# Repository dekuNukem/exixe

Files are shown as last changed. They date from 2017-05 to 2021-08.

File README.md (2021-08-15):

# exixe: Low-cost miniature Nixie tube driver modules

[Get exixe](https://www.tindie.com/products/dekuNukem/exixe-miniture-nixie-tube-driver-modules/) | [User manual](getting_started.md)



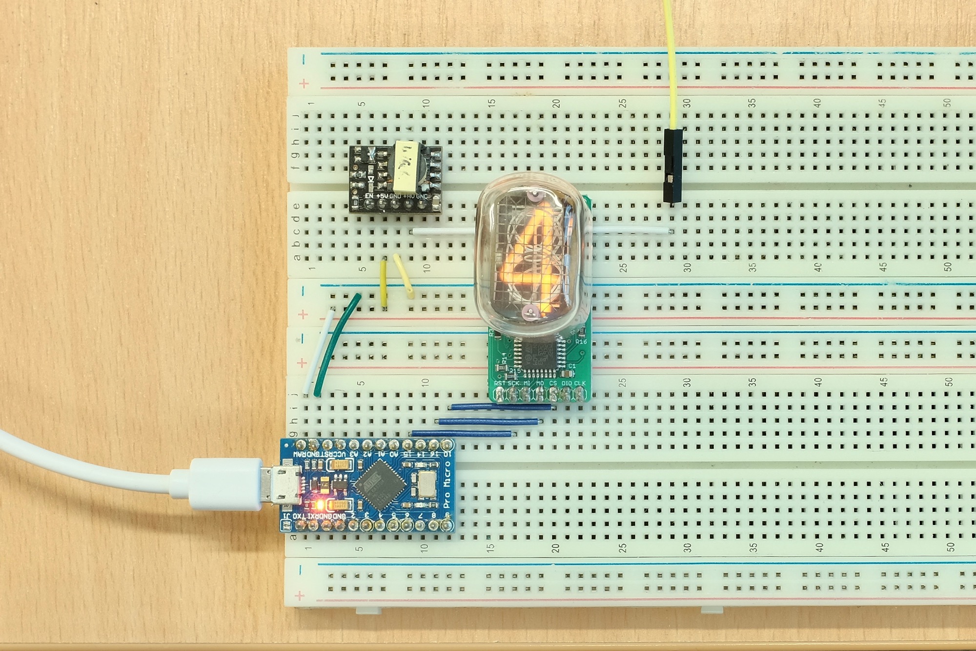
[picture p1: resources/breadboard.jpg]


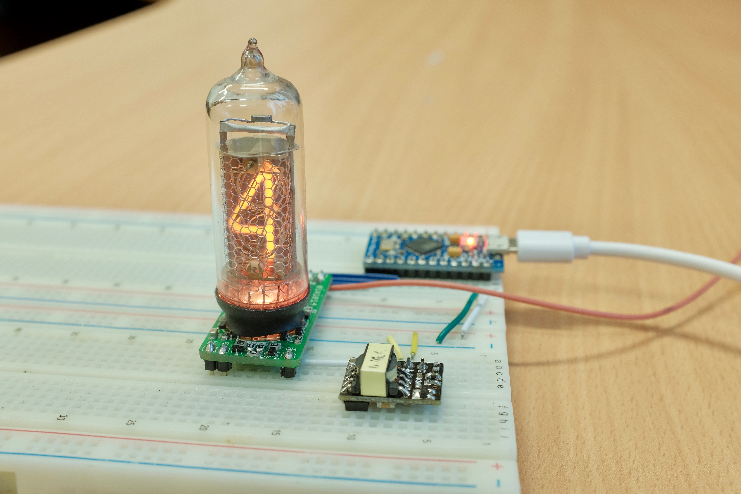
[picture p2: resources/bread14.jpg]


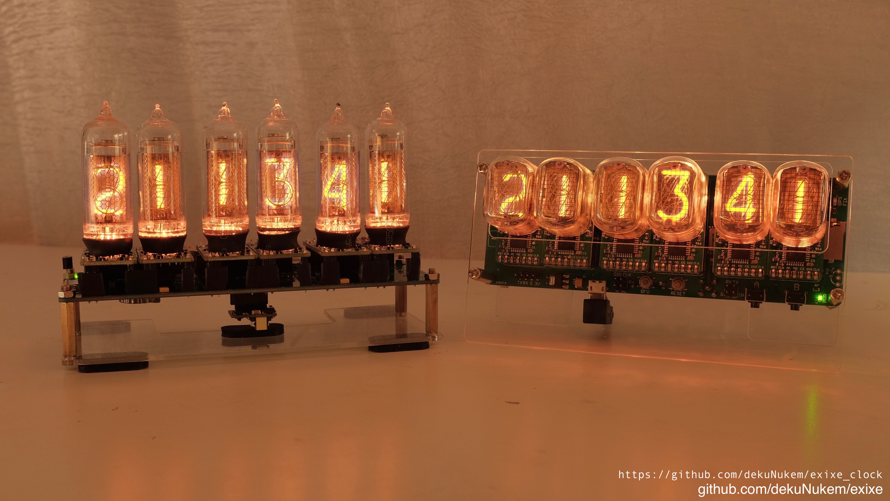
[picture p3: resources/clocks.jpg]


exixe is a miniature driver module for IN-12 and IN-14 Nixie tubes.

It aims to simplify Nixie tube related projects by eliminating the need for obscure vintage driver chips and multiplexing circuits. Instead, you can control every digit and the RGB backlight via SPI using only 3 wires and 1 line of code.

exixe is cheap, small and modular for easy integration. It is compatible with Arduino, Raspberry Pi, and virtually all embedded dev boards today.

## Buy exixe on Tindie!

I did a small production run of exixe modules, and now you can buy them directly on Tindie:

https://www.tindie.com/products/dekuNukem/exixe-miniture-nixie-tube-driver-modules/

## Features

Compared to the traditional approach, exixe modules offers significant advantages:

#### Small and modular
* 2x4 cm (0.79x1.57 inches)
* Breadboard friendly
* Easy integration
* Reusable

#### SPI interface
* High speed, up to 24MHz SCLK
* Simple 16-byte command packet
* Available on virtually all embedded systems including Arduino and Raspberry Pi

#### Advanced control
* RGB backlight
* 128 brightness levels
* Hardware PWM on all cathodes and LEDs for smooth dimming and animations

#### Tube overdrive
* Optionally allows twice the cathode current
* For poisoned cathodes in second-hand tubes
* [Before](resources/no_overdrive.jpg) and [after](resources/with_overdrive.jpg).

#### No multiplexing
* Brighter display
* Longer tube life
* Simpler design
* Lower power consumption

## Getting started

Please see [getting_started.md](/getting_started.md)

## Arduino Library

Please [click here](arduino_library)

## Raspberry Pi/Python Library

Please [click here](python_library)

## Pinout, SPI command format and technical details

Please see [technical_details.md](/technical_details.md)

## Supported tubes

exixe-14 module is primarily designed for IN-14 Nixie tubes, but will also work with IN-16 and IN-19 tubes.

exixe-12 module is primarily designed for IN-12 Nixie tubes, but works with IN-15 tubes as well.

## Using other tubes

You can also use exixe module with unsupported tubes, with some modification.

Please see [unsupported_tubes.md](/unsupported_tubes.md)

## Making some yourself

Please see [making_some.md](/making_some.md)

## Contact

Questions? Feel free to [open an issue](https://github.com/dekuNukem/exixe/issues). This is the preferred way since it helps other people too.

You can also email me at `dekunukem gmail com` for inquires.

## More photos

exixe-12 working with an Arduino Micro, showing a smooth crossfade animation:



exixe-14 in action on a [finished clock](https://github.com/dekuNukem/exixe_clock):



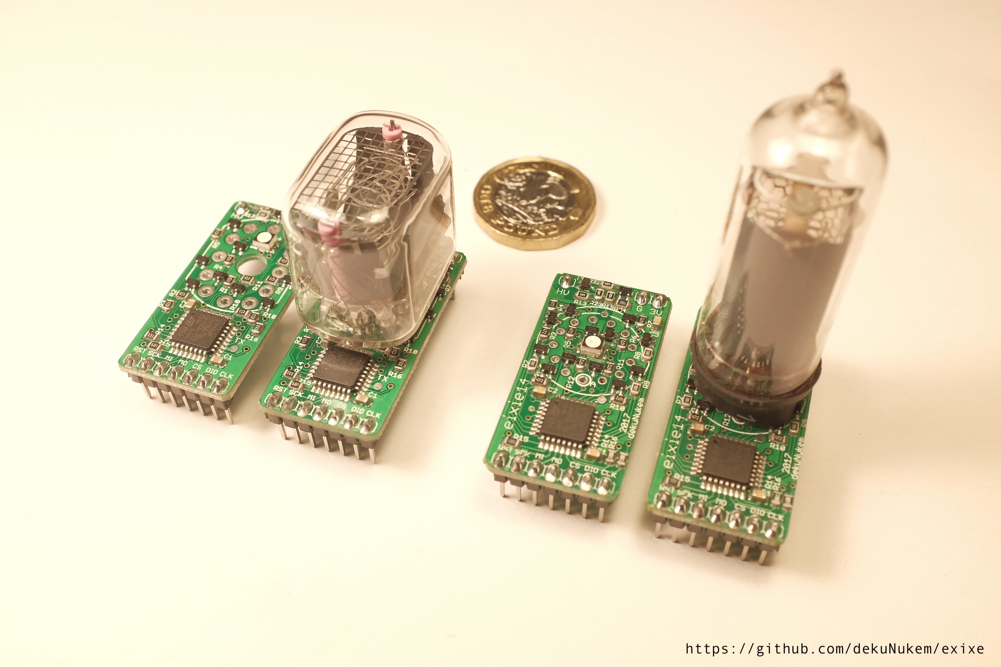
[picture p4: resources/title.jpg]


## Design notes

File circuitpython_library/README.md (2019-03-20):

# exixe Raspberry Pi/Python library

This is a simple Python library for exixe modules intended to be used on Adafruit CircuitPython devices.

# Requirements
Before you use this library, you should familiarize yourself with CircuitPython by reading through the 
following guides on the Adafruit Learning System. They will give you a good understanding of how
CircuitPython works, and differs from normal Python. They will also help you set up an appropriate 
Dev environment including the libraries you'll need, and help you make your your CircuitPython 
compatible board is set up properly
    https://learn.adafruit.com/welcome-to-circuitpython
    https://learn.adafruit.com/circuitpython-essentials/circuitpython-essentials
    https://learn.adafruit.com/circuitpython-basics-i2c-and-spi/spi-devices

# Usage 
The code has some good documentation that I dont want to repeat but this will be a general overview on how to use the library. 
1.	Create SPI initialization
> spi = busio.SPI(board.SCK, board.MOSI) <br>

2.	Identify CS pin to control the individual exixe
> cs_pin = board.D4

3.	Create exixe object
> exixe_1 = Exixe(cs_pin,spi)

4.	Control object
> exixe_1.set_digit(5) <br>
exixe_1.set_led(127,0,0) # turn led to red

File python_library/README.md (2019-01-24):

# exixe Raspberry Pi/Python library

This is a simple Python library for exixe modules intended to be used on a Raspberry Pi.

# Requirements
In order to use this library, you must have python installed, SPI interface turned on the Raspberry Pi and spidev python library installed.

# Configuration

## Turning on SPI
The SPI peripheral is not turned on by default. To enable it, do the following.
1.	Run sudo raspi-config.
2.	Use the down arrow to select 5 Interfacing Options
3.	Arrow down to P4 SPI.
4.	Select yes when it asks you to enable SPI,
5.	Also select yes if it asks about automatically loading the kernel module.
6.	Use the right arrow to select the < Finish > button.
7.	Select yes when it asks to reboot.

## Installing spidev 
**From pip:**
> pip install spidev

**From source:**
> sudo apt-get update sudo apt-get install python-dev <br>
git clone git://github.com/doceme/py-spidev <br>
cd py-spidev <br>
sudo python setup.py install <br>
sudo python3 setup.py install

# Usage 
The code has some good documentation that I dont want to repeat but this will be a general overview on how to use the library. 
1.	Create SPI initialization
> spi = spidev.SpiDev() <br>
spi.open(0,0) <br>
spi.max_speed = 7800000

2.	Identify CS pin to control the individual exixe
3.	Create exixe object
> exixe_1 = Exixe(cs_pin,spi)

4.	Control object
> exixe_1.set_digit(5) <br>
exixe_1.set_led(127,0,0) # turn led to red

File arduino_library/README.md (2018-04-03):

# exixe Arduino library

This is a simple Arduino library for exixe modules.

## Installation

[Click me](https://github.com/dekuNukem/exixe/blob/master/arduino_library/exixe.zip?raw=true) to download the library file.

In Arduino IDE, select `Sketch` -> `Include Library` -> `Add .ZIP Library`

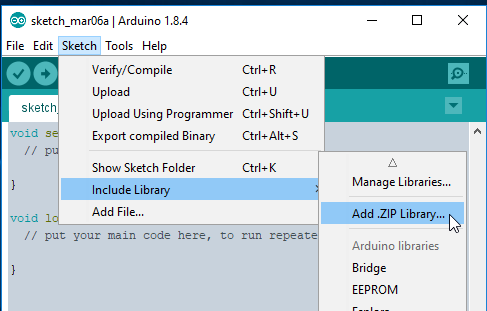
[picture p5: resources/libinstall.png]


Select the `exixe.zip` you just downloaded, and it should install automatically.

## Usage

A number of examples are [provided here](../arduino_examples). Take a look at the [getting started guide](../getting_started.md) to see how to use them.

#### `spi_init()`

* Initializes SPI peripheral, only call this once(even if you use multiple tubes) at the beginning of the sketch.

#### `show_digit(uint8_t digit, uint8_t brightness, uint8_t overdrive)`

* This sets `digit` in the tube to `brightness`.

* `digit` must be between 0 to 9.

* `brightness` must be between 0 and 127. 0 being off 127 being brightest.

* `overdrive` must be 0 or 1. When set to 1 the cathode current is doubled, helping to illuminate poisoned cathodes in second-hand tubes. [Before](../resources/no_overdrive.jpg) and [after](../resources/with_overdrive.jpg). Only use on poisoned tubes, otherwise it might shorten tube life.

* Overdrive is only available on exixe-14.

* [example usage](../arduino_examples/2_loop_digit_simple)

#### `set_led(uint8_t red, uint8_t green, uint8_t blue)`

* Set the LED backlight to provided RGB value.

* Color arguments must between 0 and 127, 0 being off 127 being brightest.

* [example usage](../arduino_examples/1_LED_test)

#### `set_dots(uint8_t left_brightness, uint8_t right_brightness)`

* Sets the decimal points in the tube to the brightness arguments.

* Brightness must be between 0 and 127, 0 being off 127 being brightest.

* IN-14 has 2 DPs, IN-12B has 1 DP, and IN-12A has no DP at all.

* You can use this to turn on DP alongside digits.

#### `clear()`

* Turns off all digits, DPs, and LED backlight.

#### `crossfade_init(uint8_t digit, uint16_t duration_frames, uint8_t brightness, uint8_t overdrive)`

* This sets up a crossfade animation.

* `digit` is the digit you want to fade into. Must be between 0 and 9.

* `duration_frames` is how long the crossfade animation should last, in number of frames. 1 second is 30 frames.

* `brightness` must be between 0 and 127, 0 being off 127 being brightest.

* `overdrive` must be 0 or 1. See `show_digit()` above for details.

* [example usage](../arduino_examples/3_loop_digit_crossfade)

#### `crossfade_run()`

* Executes the crossfade animation after `crossfade_init()`.

* Call this at **least every 33ms** for a smooth animation.

* This function is **non-blocking** and will return immediately, this allows you to do some other tasks while animation is underway. Just make sure to call it frequently enough as mentioned above.

* Check its return value to see if animation is finished. Once done it should return `EXIXE_ANIMATION_FINISHED`, otherwise `EXIXE_ANIMATION_IN_PROGRESS` is returned.

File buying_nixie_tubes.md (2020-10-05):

# Buying Nixie tubes

## Choices, choices...

Nixie tubes have been out of production for nearly 30 years. And thanks to the recent revival of Nixie clocks, the price of large tubes has gone through the roof. So if you want your project anywhere near reasonably priced and reliable, there are really only 2 tubes you can choose from, IN-12 or IN-14:

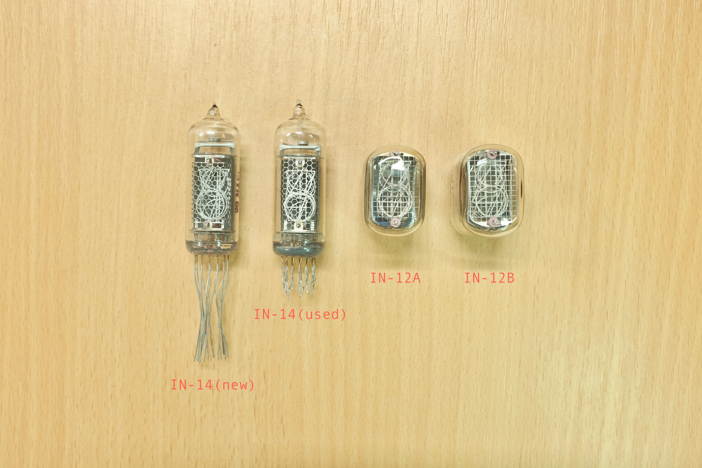
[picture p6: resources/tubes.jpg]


IN-14 is a side-view tube, while IN-12 is front-view. The digits inside are exactly the same, but IN-14 is more expensive thanks to its traditional tube shape. Still, those two mercury-enhanced USSR tubes have excellent reliability and easily last decades when properly driven.

exixe14 is compatible with IN-14 tubes, while exixe12 is for IN-12 tubes:



You can find those tubes on ebay by searching [IN-12 Nixie](https://www.ebay.com/sch/i.html?_from=R40&_nkw=in-12+nixie) or [IN-14 Nixie](https://www.ebay.com/sch/i.html?_from=R40&_nkw=in-14+nixie). Most of the sellers are from Ukraine, and often you have a choice of NOS (new old stock) or used tubes.

## NOS or used?

NOS tubes are brand new and have never been used before. They are more expensive but they are the best bet when it comes to reliability and brightness.

Used tubes are desoldered from old instruments. You don't know how long they have been operating and in what condition. They have shorter pins than new tubes, often have cathode poisoning, sometimes even missing digits or pins.

For IN-14 tubes, I recommend buying NOS if you can afford it. If not, used ones work too but you do need to buy a few more in case of duds.

IN-12 tubes are cheap enough that there are no reason to buy used ones at all. IN-12 has 2 variants. IN-12A has no decimal points, and IN-12B has a left decimal point. Both will work with exixe12 modules. 

## Symbol Tubes

There are a number of special tubes that has symbols inside them instead of numbers, usually for displaying the unit on a measuring equipment. Those tubes are cheaper than usual, but there aren't much you can do with them.

One example is the [IN-19 Nixie tube](http://www.tube-tester.com/sites/nixie/data/IN-19A/in-19a.htm). It is based on IN-14, so you can use it with exixe-14 modules, except all the numbers comes out as symbols instead. You can read more about it on [in-19_pin_mapping.md](in-19_pin_mapping.md)

Another example is [IN-15 Nixie tube](http://www.tube-tester.com/sites/nixie/data/in-15a.htm), which is based on IN-12. It will work with exixe-12 modules.

## Handling Nixie tubes

They are made of glass, and have mercury vapor inside, so don't break them.

Nixie tubes use a tiny amount of power and don't run hot at all, so it's alright to touch the glass while they are running. You can use rubbing alcohol and paper towel to clean the glass, although the alcohol might take the markings off.

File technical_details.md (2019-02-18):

## Specs

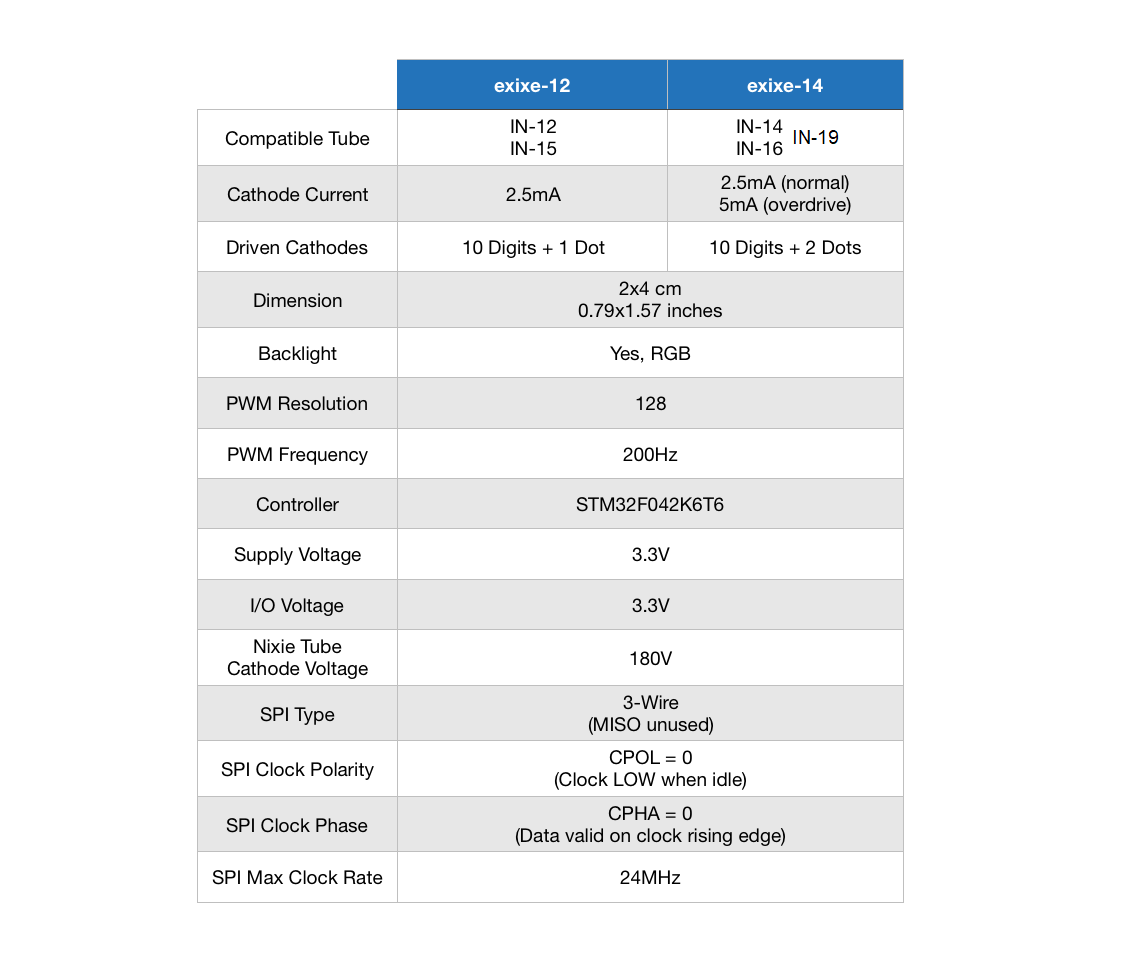
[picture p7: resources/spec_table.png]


Power consumption: 50mA per module at LED full brightness.

## Board pinout

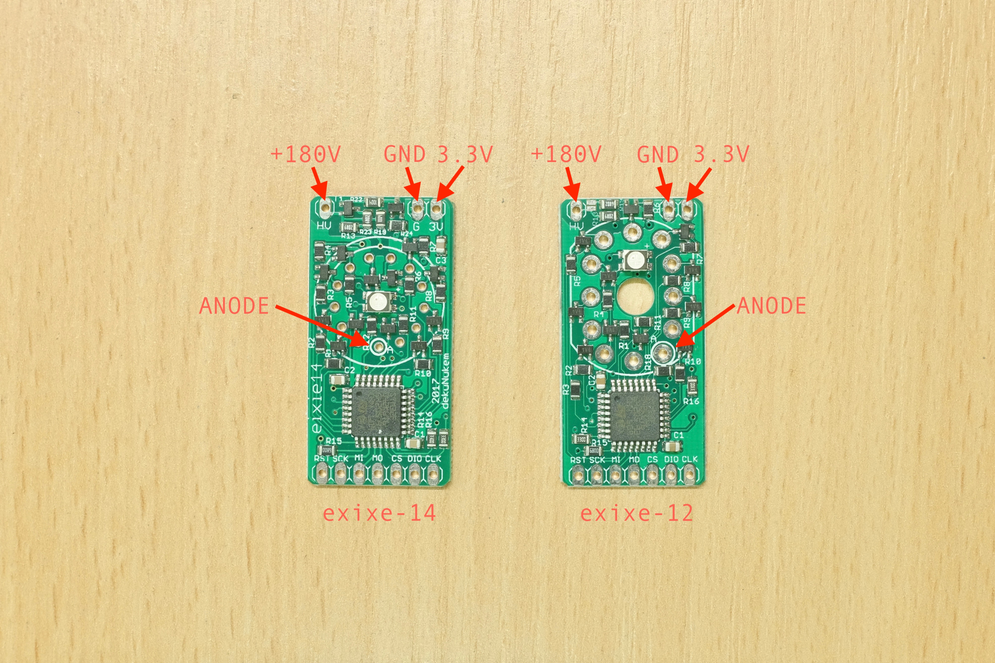
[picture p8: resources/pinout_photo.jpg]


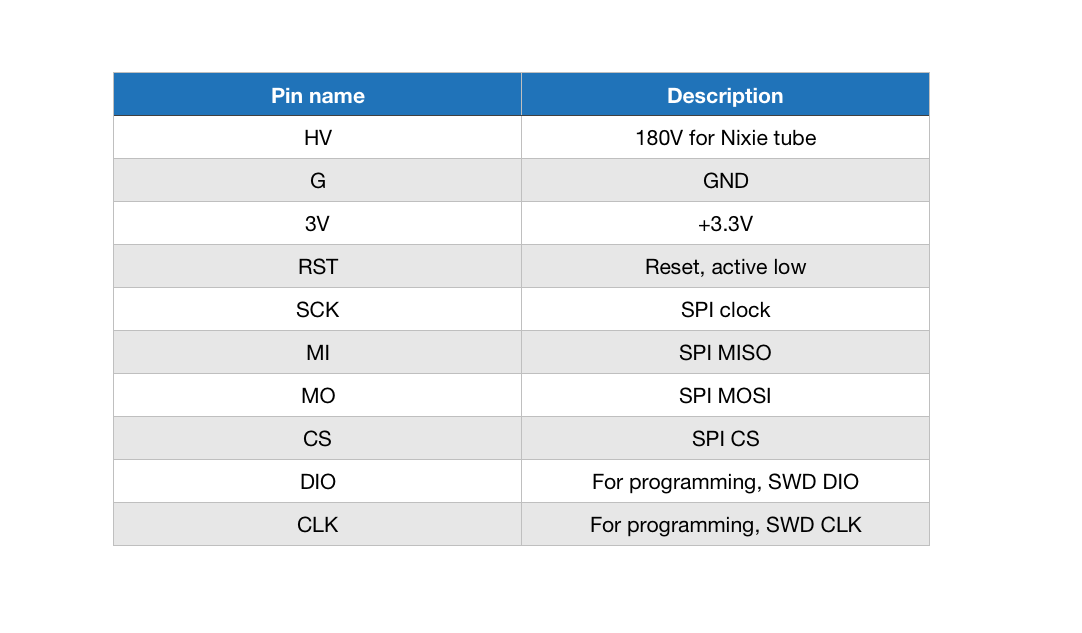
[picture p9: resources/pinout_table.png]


* Pinout and dimension are the same for exixe-12 and exixe-14.
* Officially, exixe modules are NOT 5V compatible, all signals are 3.3V level. However it does seem to work with 5V Arduinos without short term damage.
* Still, the module itself must be powered at 3.3V.

## SPI command protocol

### SPI configurations

* MSB first
* 8 bits per transfer
* Clock is LOW when inactive (CPOL = 0)
* MOSI data valid on clock rising edge (CPHA = 0)
* Max clock rate 24MHz (according to datasheet, I only tested up to 8MHz)
* Enable is active LOW
* MISO is not used.

### SPI data format

exixe expects a fixed 16-byte command, which should be sent within one CS activation (CS down, send 16 bytes, CS up):

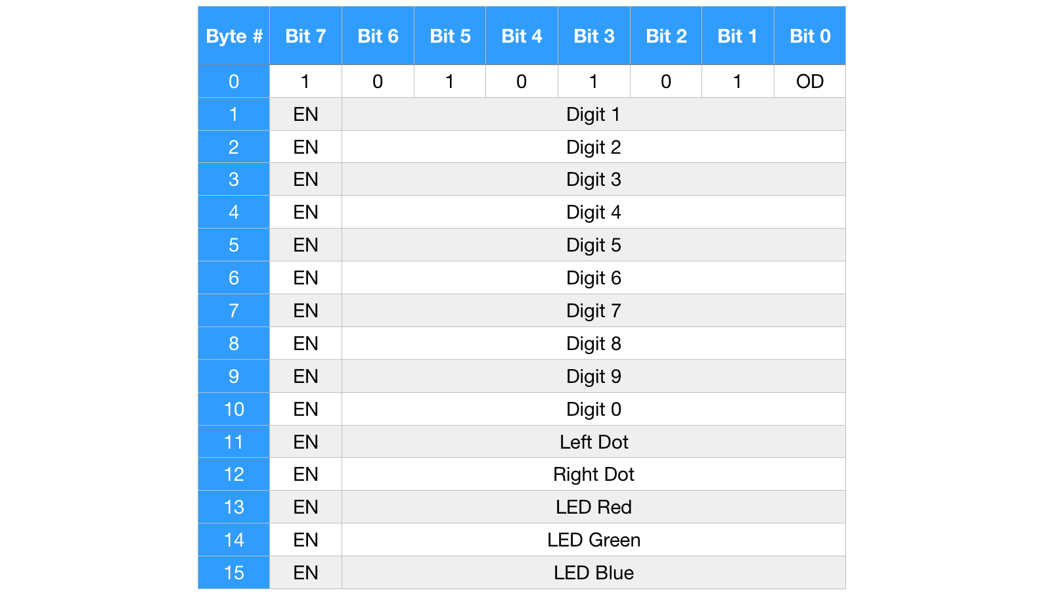
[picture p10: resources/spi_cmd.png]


* Byte 0 is sent first, byte 15 sent last.

* Set OD to 0 for regular current(2.5mA), 1 to enable overdrive (5mA)

* Set EN to 1 for the following value to take effect, 0 for no change.

* Brightness values are 7-bit integer from 0 to 127, 0 being off and 127 being brightest.

* SPI commands are the same for exixe-12 and exixe-14, however OD and right dot are not available on exixe-12, changing them will have no effect.

### Notes

* Only one single digit should be on at any given time, apart from during transition animations.

* Dots can be turned on alongside digits.

* If you are unfamiliar with SPI, or need a refresher, [sparkfun's introduction](https://learn.sparkfun.com/tutorials/serial-peripheral-interface-spi) is really helpful, and [the wikipedia page](https://en.wikipedia.org/wiki/Serial_Peripheral_Interface_Bus) has more details.

### Sample timing capture

Setting digit 4 to fully on while other digits are off, no overdrive, orange LED color:



Detailed timing for the first byte:



## Technical details

At the heart of the module is a STM32F042K6T6 microcontroller, which is connected to the cathodes of the Nixie tube through high-voltage transistors to turn them on or off. Thanks to the abundance of timers, every single cathode gets their own hardware PWM, which is much more consistent and smooth than software toggling.

The PWM frequency is 200Hz by default, it works well and can be changed by adjusting timer predivider values.

The microcontroller acts as a SPI slave and reads 16-byte commands from the master devices. Details of which can be found on the section above.

In normal operation each cathode has a 68K current resistor, allowing 2.6mA at 180V. However, if you're using IN-14 tubes chances are they are second-hand, and most I see doesn't light up all the way on digit 2 and 3. They are slightly poisoned and needs a bit more current to light up properly. Therefore exixe-14 features an overdrive command that allows twice that current to pass through.

Please note that you still need a high-voltage power supply around 180V for Nixie tubes to start glowing. You can design one yourself for your project, or use a pre-made module that takes 5V and outputs 180V. Just search "5V nixie power" on ebay, here's [one example](https://www.ebay.com/itm/DC-5V-12V-to-170V-DC-High-Voltage-NIXIE-Power-Supply-Module-PSU-NIXIE-TUBE-ERA-/322511957768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).

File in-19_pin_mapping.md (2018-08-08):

# IN-19(A,B,V) pin mapping

Exixe-14 modules are designed for IN-14 tubes, which have 13 pins. IN-19(A, B or V) tubes have 14 pins, but some are without function. The anode on IN-19 tubes (pin 8) is the one on the back and white inside the glass. Don't confuse it with the pin on the very front of the tube, which also has a white marking, but is unused (and sometimes cut off). The following table shows which pin to solder through which hole on the exixe module. Empty rows indicate that you should skip a hole and a pin. Also see the picture indicating which hole connects to which IN-14 pin. To show a IN-19 symbol using the arduino library, call `exixe::show_digit()` with the corresponding IN-14 digit, for example 3 to show a µ (IN-19A), Ω (IN-19B) or + (IN-19V).

| IN-14 pin | IN-14 symbol | IN-19 pin | IN-19A symbol | IN-19B symbol | IN-19V symbol |
|---:|---:|---:|---:|---:|---:|
| 1 | (anode) | 8 | (anode) | (anode) | (anode) |
| 2 | left dot | | | | |
| 3 | digit 1 | 10 | K | T | - |
| 4 | digit 2 | 11 | n | A | > |
| 5 | digit 3 | 12 | µ | Ω | + |
| 6 | digit 4 | | | | |
| 7 | digit 5 | 14 | °C | Hz | dB |
| 8 | digit 6 | | | | |
| 9 | digit 7 | 2 | % | S | Π |
| 10 | digit 8 | 4 | M | F | A/B |
| 11 | digit 9 | 5 | P | H | ~ |
| 12 | digit 0 | 6 | m | V | < |
| 13 | right dot | | | | |

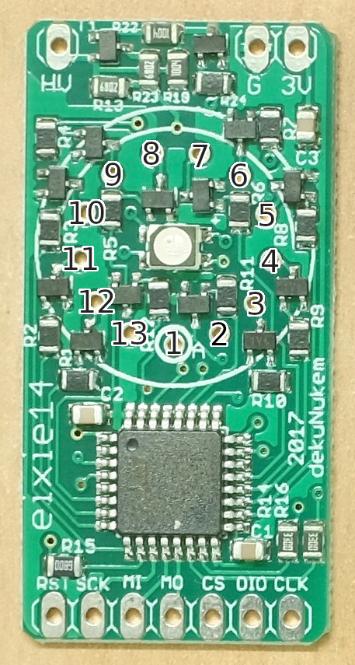
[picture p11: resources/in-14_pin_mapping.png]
IN-14 pin mapping


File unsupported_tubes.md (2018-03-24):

# Using other tubes with exixe modules

A number of people have been asking if they can use Nixie tubes other than IN-14 and IN-12 with exixe modules. The answer is, in most cases, yes. And here is a short guide on how to get started.

Note that I make no guarantee that it is going to work with an unsupported tube, or it won't damage the tube or itself.

Anyway, there are some subjects to consider:

## Which module?

I recommend using exixe-12 with unsupported tubes. It is cheaper and have larger holes that's easier to work with.

Get 1 or 2 at first to see if it works with your tube. [Click me to buy some](https://www.tindie.com/products/dekuNukem/exixe-miniture-nixie-tube-driver-modules/).

## Pin connections

Most likely the new tube will have a different pinout, and you won't be able to plug it in the module itself. As a result you need to use some extension wires to solder the correct pin into the correct hole. Consult this photo:

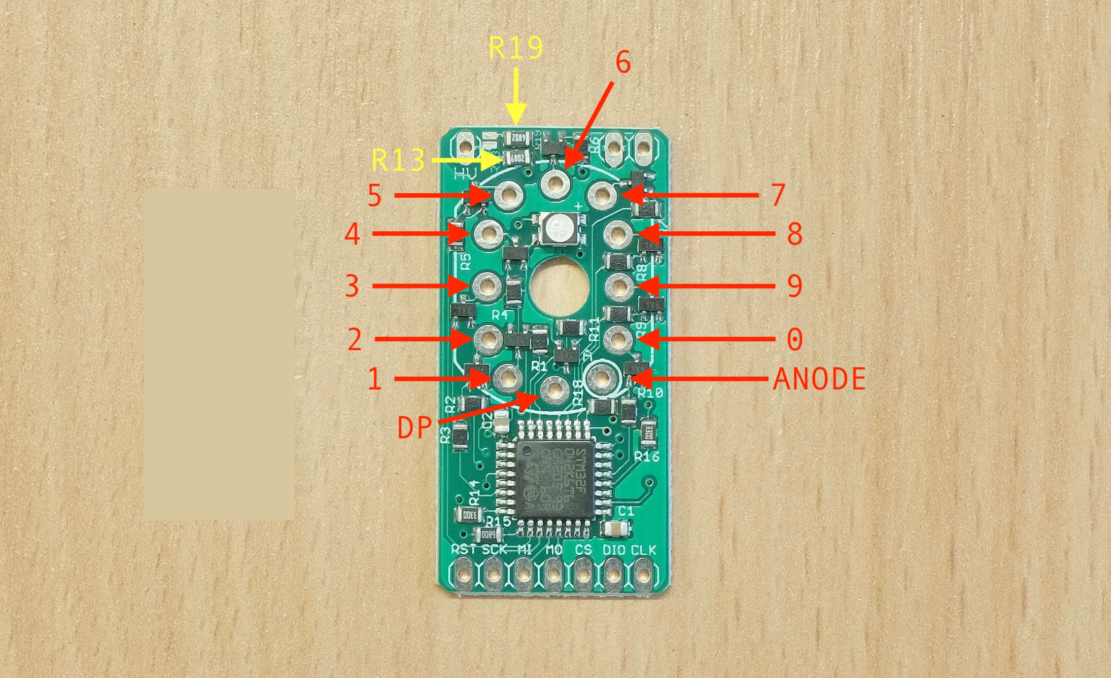
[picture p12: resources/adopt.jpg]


Connect the digit cathode pin to the corresponding hole, and anode pin to the anode hole.

## Cathode Current

The exixe modules limits cathode current to **`2.5mA`** by using an **`68K`** resistor before the anode.

If this works with your tube, you don't have to do anything.

If not, you will need to adjust the current limiting resistor. There are two ways of doing this.

### External resistor

This is the easiest way. Simply ignore the HV pin on the module and connect the +170V directly to your tube's anode **through a resistor of appropriate value**, then connect all the cathodes to the module as usual.

The external resistor will also be able to handle more power, so **use this method if the cathode current is more than 4mA**.

### Adjusting SMD resistor

You can also change the on-board resistor to one with the appropriate value. Here is the related circuit diagram:

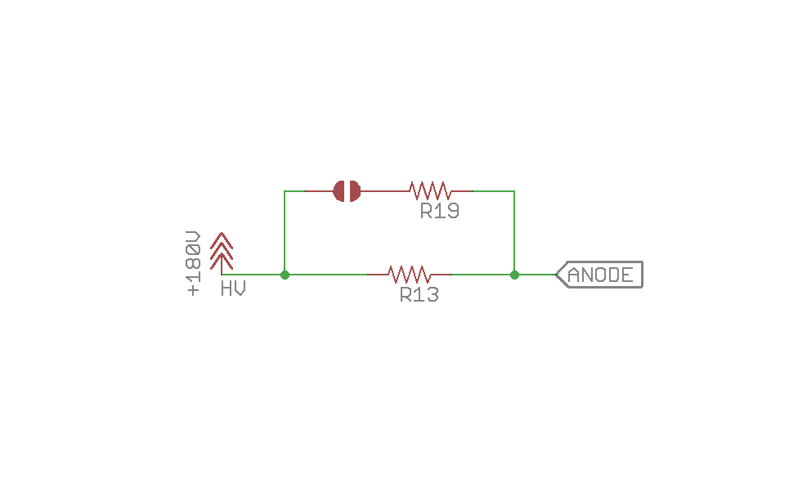
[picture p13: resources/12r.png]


As you can see, on the exixe12, the HV goes though R13 to the anode. Therefore you can change that 0805 resistor to the value you desire.

Conversely, you can also bridge the solder jumper and bring R19 into action. If you do, the two resistors will be in parallel but each will use less power, thus preventing them from overheating.

You can find the location of R13 and R19 on the photo in the `Pin connections` section above.

## Examples

An user have successfully adopted exixe-12 to work with Burroughs 5031/80376844A tubes. He used an external 10K resistor, and here is a video of it in action:

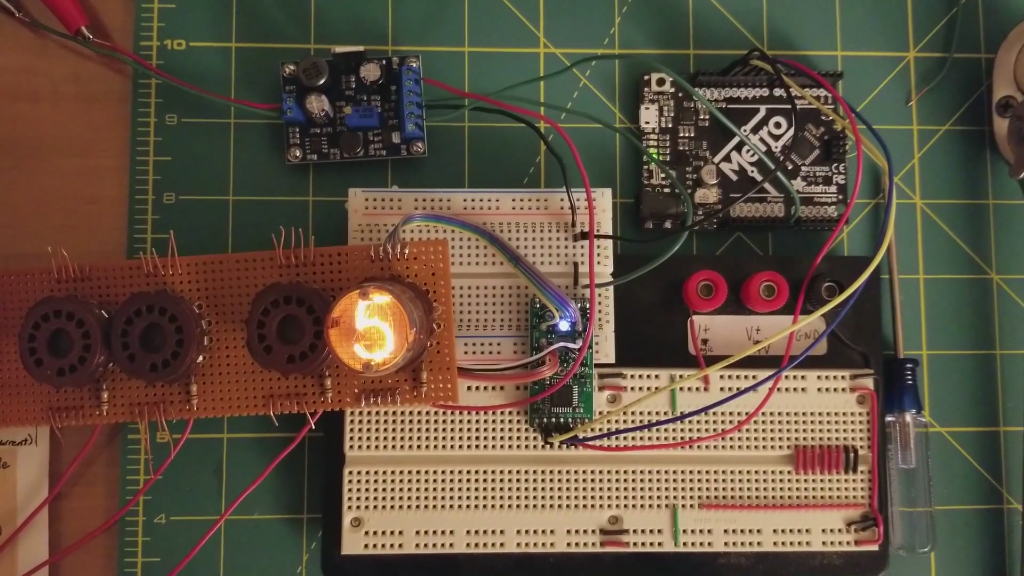
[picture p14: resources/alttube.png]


https://www.youtube.com/watch?v=TBaXTYCC1QY

## Questions?

That's pretty much it! As usual, feel free to [open an issue](https://github.com/dekuNukem/exixe/issues) if you have any questions. This is the preferred way since it helps other people too.

You can also email me at `dekunukem gmail com` for inquires.

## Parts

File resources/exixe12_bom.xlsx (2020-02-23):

Part | Value | Device | Package | Description
C1 | 1uF | CAP0805 | 0805 | Capacitor
C2 | 100nF | CAP0805 | 0805 | Capacitor
D1 | RGB LED | RGB_LED | 3528-COMMON-ANODE | SMD full-color LED
JP1 |  | PINHD-1X7 | 1X07 | PIN HEADER
JP2 |  | PINHD-1X7 | 1X07 | PIN HEADER
N1 | IN-12B | IN-12B | IN-12 | IN-12B: medium numeric topview nixie tube
Q1 |  | BF820 | SOT323 | NPN TRANSISTOR
Q2 |  | BF820 | SOT323 | NPN TRANSISTOR
Q3 |  | BF820 | SOT323 | NPN TRANSISTOR
Q4 |  | BF820 | SOT323 | NPN TRANSISTOR
Q5 |  | BF820 | SOT323 | NPN TRANSISTOR
Q6 |  | BF820 | SOT323 | NPN TRANSISTOR
Q7 |  | BF820 | SOT323 | NPN TRANSISTOR
Q8 |  | BF820 | SOT323 | NPN TRANSISTOR
Q9 |  | BF820 | SOT323 | NPN TRANSISTOR
Q10 |  | BF820 | SOT323 | NPN TRANSISTOR
Q11 |  | BF820 | SOT323 | NPN TRANSISTOR
R1 | 10K | RESISTOR0805-RES | 0805 | Resistor
R2 | 10K | RESISTOR0805-RES | 0805 | Resistor
R3 | 10K | RESISTOR0805-RES | 0805 | Resistor
R4 | 10K | RESISTOR0805-RES | 0805 | Resistor
R5 | 10K | RESISTOR0805-RES | 0805 | Resistor
R6 | 10K | RESISTOR0805-RES | 0805 | Resistor
R7 | 10K | RESISTOR0805-RES | 0805 | Resistor
R8 | 10K | RESISTOR0805-RES | 0805 | Resistor
R9 | 10K | RESISTOR0805-RES | 0805 | Resistor
R10 | 10K | RESISTOR0805-RES | 0805 | Resistor
R11 | 10K | RESISTOR0805-RES | 0805 | Resistor
R12 | 10K | RESISTOR0805-RES | 0805 | Resistor
R14 | 330 | RESISTOR0805-RES | 0805 | Resistor
R15 | 680 | RESISTOR0805-RES | 0805 | Resistor
R16 | 330 | RESISTOR0805-RES | 0805 | Resistor
R17 | 10K | RESISTOR0805-RES | 0805 | Resistor
R18 | 10K | RESISTOR0805-RES | 0805 | Resistor
R19 | 68K | RESISTOR0805-RES | 0805 | Resistor
U$2 | STM32F042K6T6 | STM32F042K6T6 | TQFP32-08 | STM32 microcontroller
 | Unlisted components need not to be populated

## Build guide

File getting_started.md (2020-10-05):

# Getting started with exixe modules

## Prerequisites

You do need a couple of things before we get going, so let's get them out of the way first:

#### Nixie Tubes

[Read this short guide to see what to buy.](buying_nixie_tubes.md)

#### High Voltage Power Supply

Nixie tubes need around 180V to start glowing. That means you need a high voltage supply.

You can design one yourself, although I recommend saving the trouble and getting a premade module [like this one](https://www.ebay.com/itm/DC-5V-12V-to-180V-DC-High-Voltage-NIXIE-Power-Supply-Module-PSU-NIXIE-TUBE-ERA-/322511957768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). They are tiny, inexpensive, efficient, and run on 5V. Just search [5V Nixie power supply](https://www.ebay.com/sch/i.html?_from=R40&_nkw=5V+Nixie+power+supply) on ebay or google. 

## What you should have

By now, you should have the tube, corresponding exixe board, headers, and the high voltage supply:

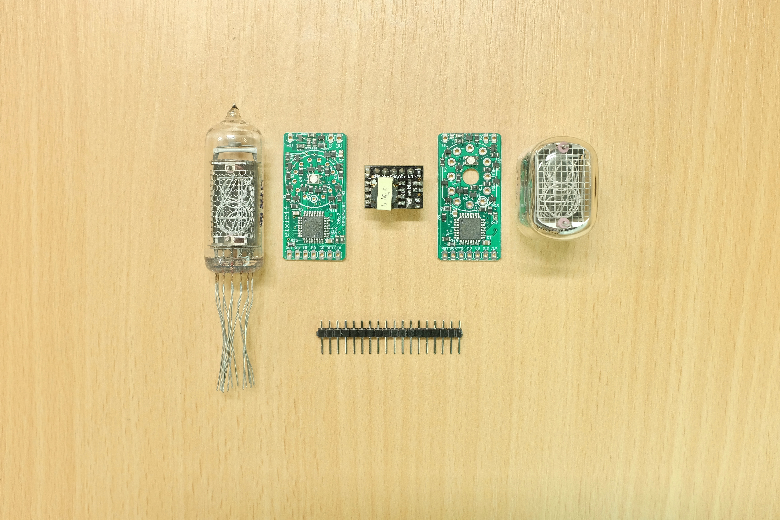
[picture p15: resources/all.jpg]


Good! Now we can get going.

## Installing the Arduino library

Take a look at the [Arduino library docs](arduino_library/README.md) to download and install the library.

If you're not using Arduino, there are some [barebone examples](/arduino_examples/barebone) too.

## Testing the bare module

Let's make sure the board works before soldering the tubes.

When handling the bare circuit board there is a risk of [electrostatic discharge](https://en.wikipedia.org/wiki/Electrostatic_discharge), where the static electricity(SE) on your body discharges and damages the board. This is especially a concern during dry weather. My suggestion is simply **wash your hands**, by doing so you discharge your existing SE through the metal water pipe, your hands are moist to prevent further SE build-up, and your clean hands won't leave greasy fingerprints all over the place, win-win-win!

So do that, solder on the headers, and take a look at the pinout in [technical_details.md](/technical_details.md). Turn off the power when hooking up the board, only turn it on after all connections are complete and double-checked!

First we hook up the power pins. Connect the GND to GND, and 3.3V power to 3V. 

Next are the SPI lines. Connect MO to MOSI line, SCK to SCK line, and CS to CS line. For Arduino UNO below, MOSI is pin 11, SCK is pin 13, CS is pin 10. Consult the datasheet if you're using other boards.

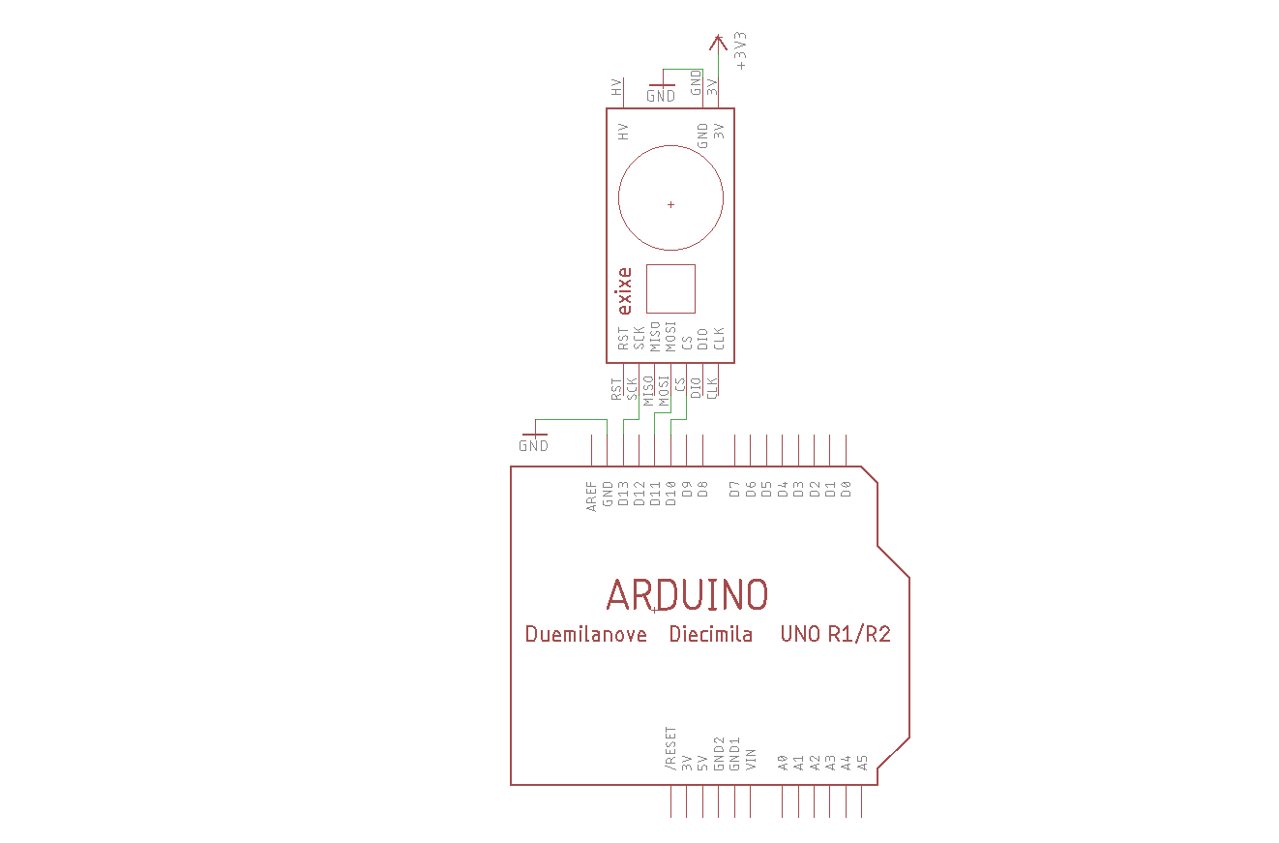
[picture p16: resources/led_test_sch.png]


Double check the connection, power on, and try the [LED test](/arduino_examples/1_LED_test). Change the `cs_pin` variable if you're using a different one. Compile and upload in Arduino IDE. 

The LED on the exixe module should turn purple. You can play around with the RGB values for other colors.

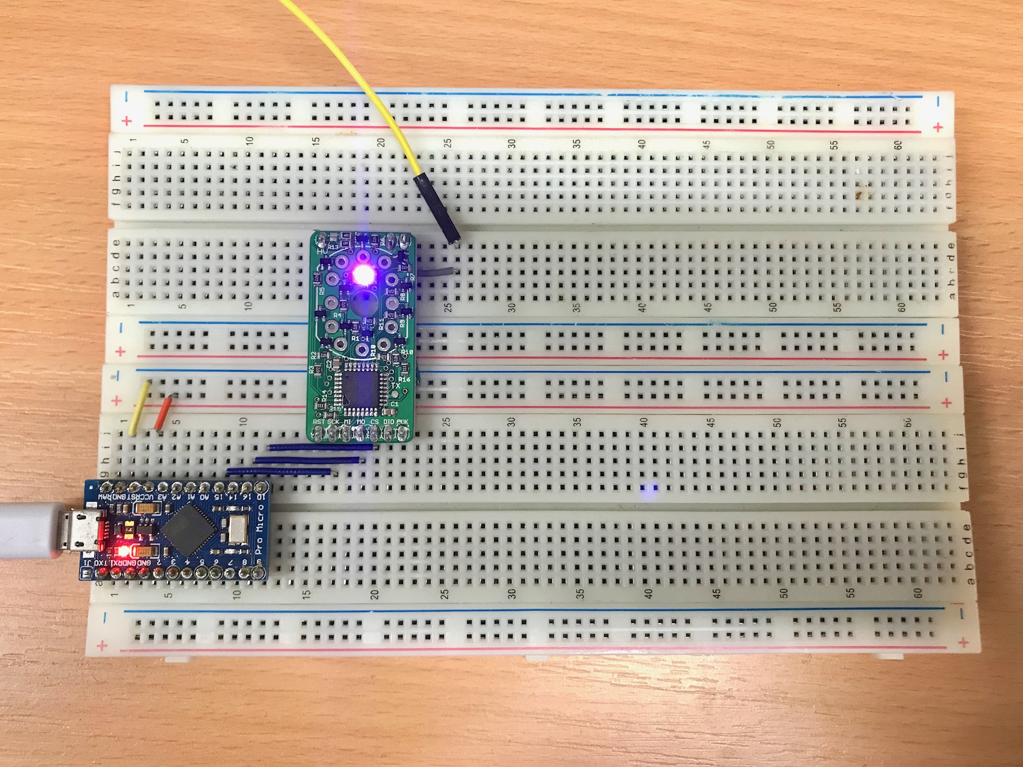
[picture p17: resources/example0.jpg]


If the board is not responding, take a look at the SPI commands in [technical_details.md](/technical_details.md) to make sure the SPI is configured properly, and the commands are valid. Also make sure the RST pin is HIGH, and CS pin is asserted properly. Use a logic analyzer to see what's going on if you have one.

### Testing tubes

I recommend testing your tubes first to make sure all digits light up, so you don't end up soldering a dud to the module.

First locate the anode on you tube:

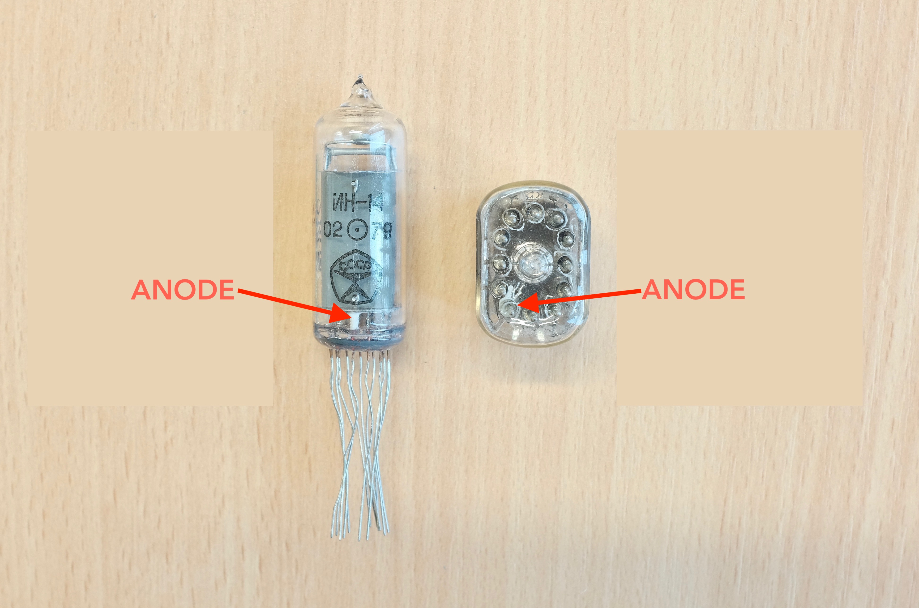
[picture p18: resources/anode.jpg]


On IN-14 the anode pin is on the very back of the tube and is white inside the glass. On IN-12 an arrow on the glass points to the anode pin, which is rather convenient.

Next, connect +5V to 5V input of the high voltage module, and GND to GND. You should get around 180V at the HV output pin. Be very careful not to touch that. It might not kill you but you'll definitely feel a shock.

To test the tube, connect the anode to 180V **THROUGH A 68K RESISTOR**, then touch each cathode with GND and see if the corresponding digit lights up:

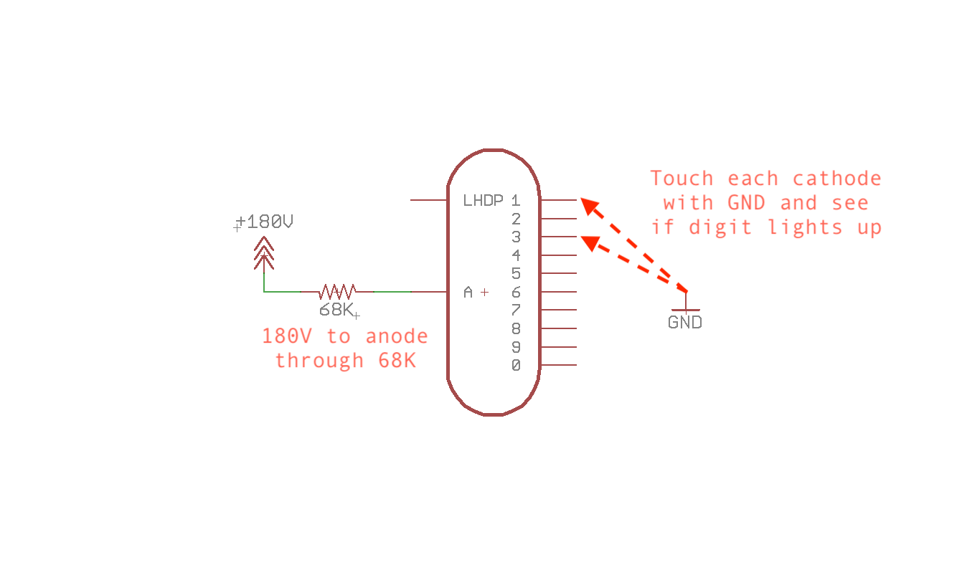
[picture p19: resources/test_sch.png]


Be very careful not to touch exposed metal pins, a pair of glove might help if you want to be sure.

## Solder it on

*If you're using IN-19 tube, please see [this guide](in-19_pin_mapping.md) for more information, otherwise read on.*

After confirming the tube is good, you can insert it to the module. Match anode pin to the anode hole, then line up everything else:

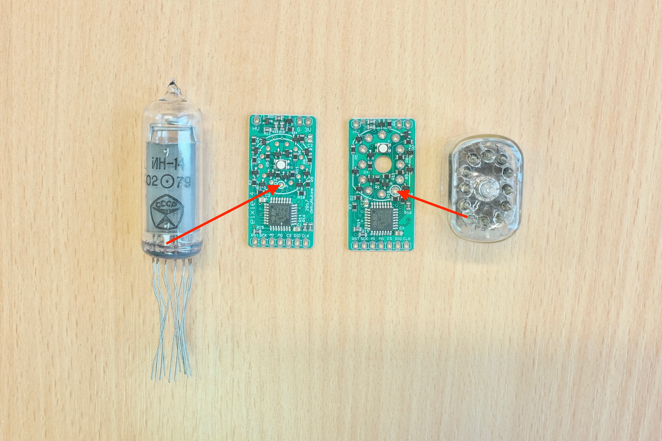
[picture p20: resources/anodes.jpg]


It's a bit tricky on the IN-14 since the pins are not rigid. Just be patient and eventually it will all go in. Again, make sure the anode and every other pin is lined up correctly, then solder the tube in place.

Try keeping the tube straight. For IN-14 leave around 5mm of pins between the PCB and the glass as demonstrated on the middle tube:

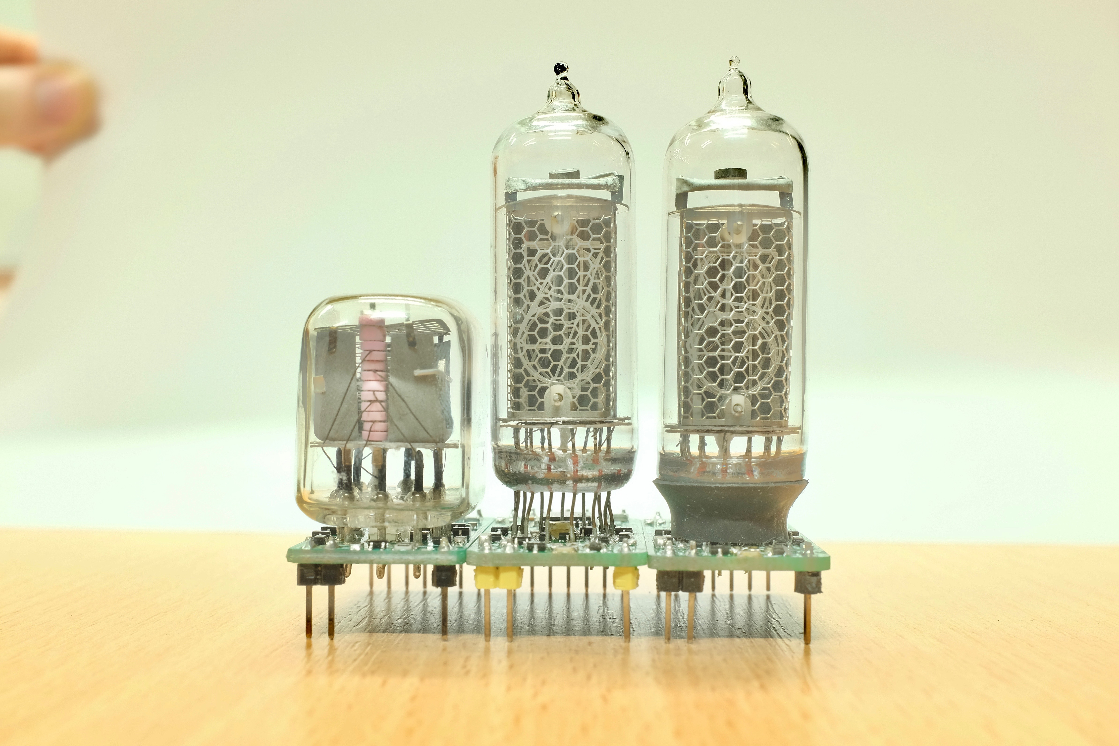
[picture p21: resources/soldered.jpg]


It's also a good idea to wrap the bottom of IN-14 tubes with heat-shrink tubing or electric tape like the one on the right, to prevent backlight leaking.

## Power consumption considerations

For the 3.3V power supply, please budget **at least 50mA** for *each* exixe module.

This is especially important if you're using Arduino UNO or other 5V Arduinos. The 3.3V power pin on those can only supply [50mA of current](resources/current.jpg), which is only enough for a single exixe module. If you connect more than one, things start to behave strangely.

You can either switch to a 3.3V Arduino where no such limit exists, or use a [5V to 3.3V regulator](https://www.sparkfun.com/products/526). Don't forget about the input and output capacitors, [they are important](https://electronics.stackexchange.com/questions/232935/why-is-there-always-a-capacitor-on-input-and-output-of-a-voltage-regulator)!

## Try some examples!

With tube soldered on, and [LED test](/arduino_examples/1_LED_test) working, connect 180V to the HV pin of exixe module, make sure your Arduino, high voltage supply, and exixe module all share the same GND. 

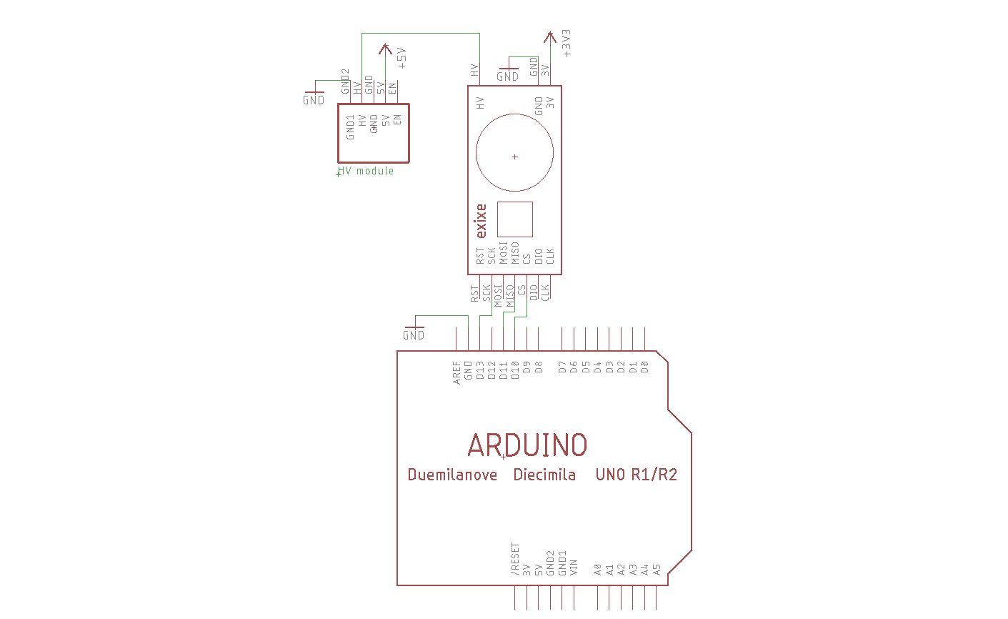
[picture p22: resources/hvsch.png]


First try the [loop digit](/arduino_examples/2_loop_digit_simple) example, which simply loops through all the digits from 0 to 9:



After that, you can try [crossfade](/arduino_examples/3_loop_digit_crossfade) to see the fancy crossfade animation:



If you're using more than one tube, take a look at [multiple tubes](/arduino_examples/4_multiple_tubes_simple) example:



Note that the multiple modules share the same SCK and MOSI line, only CS line is different.

Finally, the [multiple tubes crossfade](/arduino_examples/5_multiple_tubes_crossfade) example:



## Troubleshooting

If your exixe modules are behaving inconsistently, such as flickering or not responding to SPI commands, there are a couple of areas to check:

* As mentioned above, make sure your 3.3V power supply is adequate. Budget at least 50mA for **`EACH`** exixe module.

* Double check your connections. Make sure everything shares the same GND, and all the SPI lines are properly connected.

* If you're using a breadboard, beware of dead holes! It happened to one of my customers, so if you're truly desperate, try moving stuff around, or use a different breadboard.

* Some HV modules can produce significant noise on its output and corrupt SPI signals. Try leaving it out and see if situation improves (by playing with LED colours). You can reduce the noise by putting a ferrite bead along the HV wire, or try using decoupling capacitors. Make sure the voltage rating is adequate!

* Try using a logic analyzer or oscilloscope to see what exactly is happening on SPI lines. Make sure the [SPI configuration is correct](/technical_details.md#spi-command-protocol), and compare the waveform with [the correct sample capture](/technical_details.md#sample-timing-capture).

* If all else fails, start simple with a single module, no HV, and [barebone example](/arduino_examples/barebone). If that works, start adding more stuff in. This might give you a better idea of which part is causing the problem.

* Of course, you can always ask me! Feel free to [open an issue](https://github.com/dekuNukem/exixe/issues) or email me at `dekunukem gmail com`.

## Resources

Consult the [Arduino library docs](arduino_library/README.md) and [Python library docs](python_library/README.md) to see how to use library functions. And explore the [arduino sample sketches](/arduino_examples) and [python samples](/python_examples).

If you want to keep it simple, there are some self-contained [barebone examples](/arduino_examples/barebone) too.

For technical details and specifications, [see this guide](/technical_details.md).

## Go and have fun!

If you have any questions, feel free to [open an issue](https://github.com/dekuNukem/exixe/issues) or email me at `dekunukem gmail com`. The former is preferable since it helps other people too.

That's pretty much it! You can let your imagination run free now. Go wild and have fun!

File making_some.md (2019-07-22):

# Making some yourself

Making some exixe modules yourself is fairly straightforward, just order the PCBs and parts and solder them together. Since the component count is not small and they are densely populated, I suggest order the PCB in panels of 6 or 8 and get a matching stencil to apply the paste. Use of reflow oven or skillet reflow is also recommended, since soldering each and every component by hand is basically torture.

Full BOM here: [exixe12](resources/exixe12_bom.xlsx), [exixe14](resources/exixe14_bom.xlsx)

* The NPN transistor used on every cathode is [BF820](https://www.mouser.co.uk/Search/ProductDetail.aspx?R=BF820W%2c135virtualkey66800000virtualkey771-BF820W135)
* The single PNP transistor used in overdrive circuit is [MSB92](https://www.mouser.co.uk/Search/ProductDetail.aspx?R=MSB92ASWT1Gvirtualkey58410000virtualkey863-MSB92ASWT1G)
* Microcontroller is [STM32F042K6T6](https://www.mouser.co.uk/Search/ProductDetail.aspx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)
* LED is [Wurth Electronics 150141M173100](https://www.mouser.co.uk/Search/ProductDetail.aspx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)

## Upload Firmware

Once you have soldered the board together, you will need to upload the firmware to the STM32 microcontroller in order for the boards to function.

To do that you need a ST-Link V2 programmer. Just search "ST-Link V2" on ebay, they are dirt cheap (around $3). It should look like this:

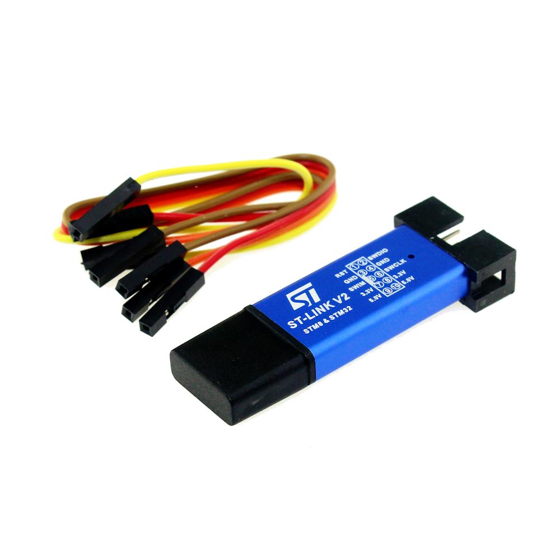
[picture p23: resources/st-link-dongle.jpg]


Then go and download the free STM32 ST-LINK Utility from the official ST website:

http://www.st.com/en/development-tools/stsw-link004.html

Click "get software" at the bottom of the page, then provide a name and email to get the download link. Use a fake name and a burner email like [this one](https://slippery.email/) to avoid spams.

The ST-LINK Utility will install the driver for the programmer automatically. After which you can connect the programmer to the exixe board:

* `GND` to `GND`
* `3.3V` to `3V`
* `SWDIO` to `DIO`
* `SWCLK` to `CLK`

After the board is connected to the programmer, plug the programmer into the USB port, then open the ST-LINK Utility. Click the button indicated below to connect to the microcontroller:

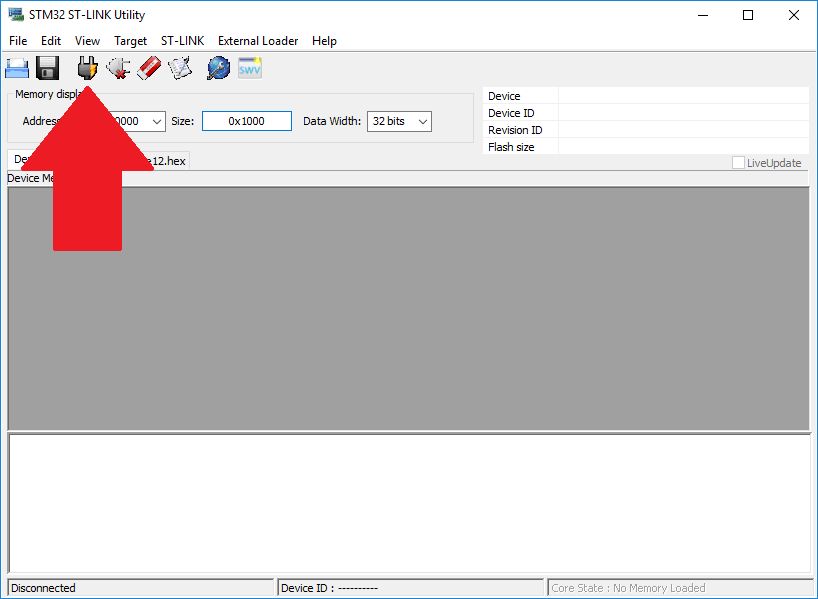
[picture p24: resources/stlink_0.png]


If your solder job is good, the ST-LINK Utility should be able to connect to the STM32 and show the content of its internal memory:

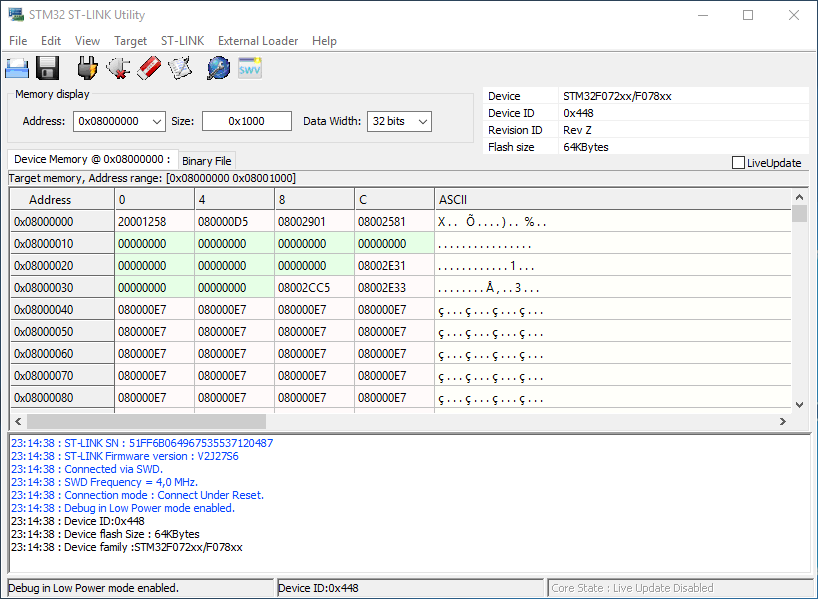
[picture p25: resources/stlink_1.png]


If the chip is brand new, everything shoud be 0xff. Anyway, click Target -> Program:

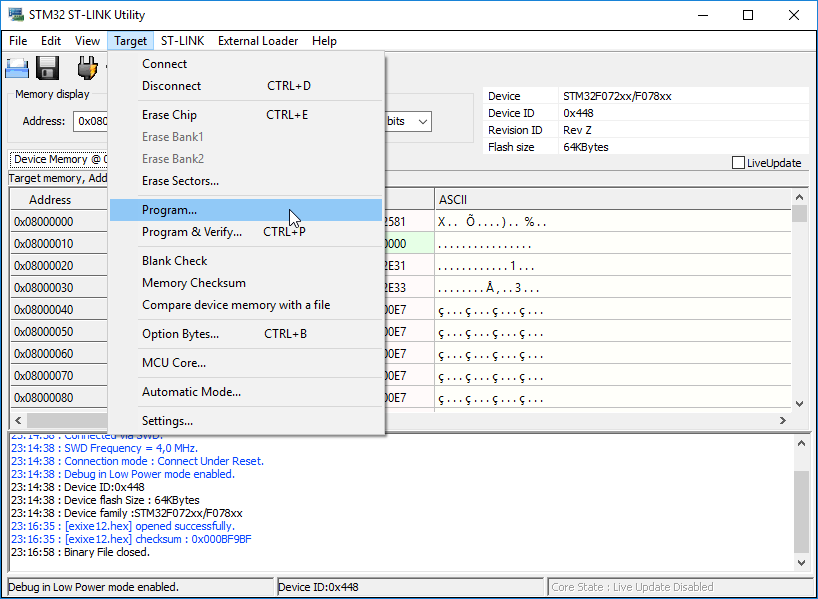
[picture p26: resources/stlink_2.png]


Then select the HEX file that you want to use, [exixe12](/firmware/exixe12/exixe12.hex) [exixe14](/firmware/exixe12/exixe14.hex):

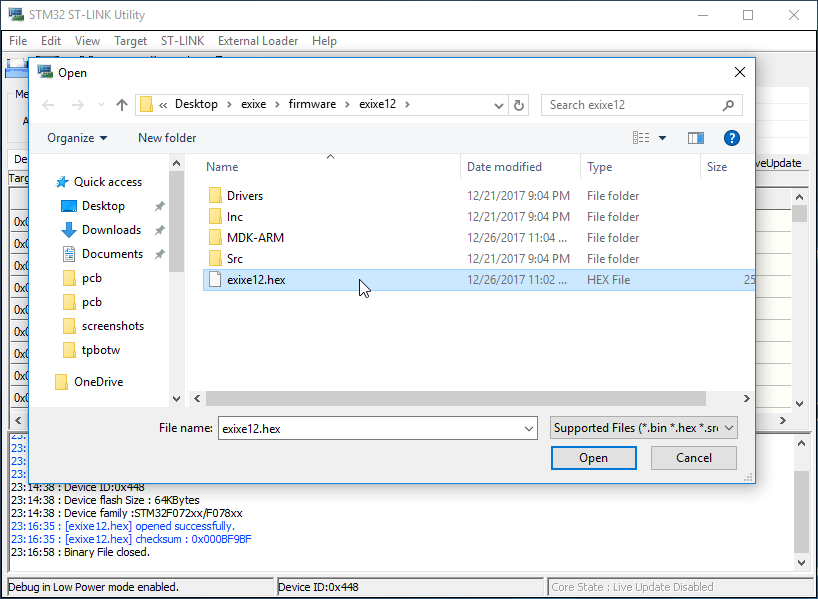
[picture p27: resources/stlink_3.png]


Then click start to upload the firmware:

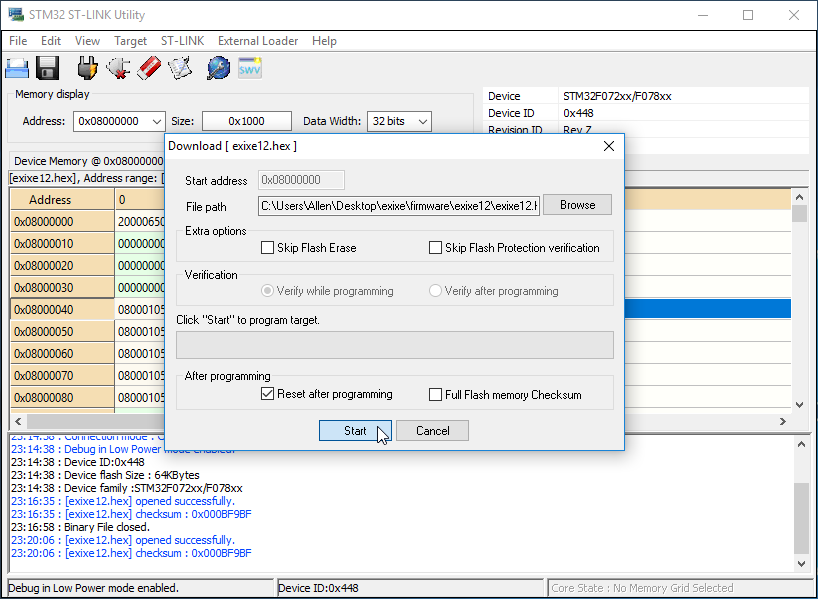
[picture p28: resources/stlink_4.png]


That's pretty much it if you don't want to recompile the firmware. If you do however you'll need to download the [Keil MDK](https://www.keil.com/demo/eval/arm.htm), it's slightly more involved, [see this guide](https://github.com/dekuNukem/STM32_tutorials) for details.

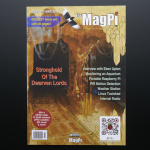
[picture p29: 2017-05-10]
resources/Choosing the Right Crystal and Caps for your Design « Adafruit Industries – Makers, hackers, artists, designers and engineers!_files/150x150_011.jpg

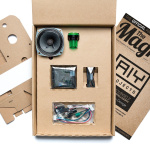
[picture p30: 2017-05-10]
resources/Choosing the Right Crystal and Caps for your Design « Adafruit Industries – Makers, hackers, artists, designers and engineers!_files/150x150_014.jpg

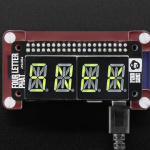
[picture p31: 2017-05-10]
resources/Choosing the Right Crystal and Caps for your Design « Adafruit Industries – Makers, hackers, artists, designers and engineers!_files/150x150_002.jpg

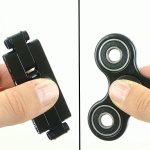
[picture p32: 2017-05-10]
resources/Choosing the Right Crystal and Caps for your Design « Adafruit Industries – Makers, hackers, artists, designers and engineers!_files/150x150_015.jpg

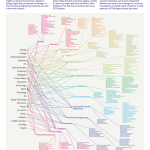
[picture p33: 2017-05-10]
resources/Choosing the Right Crystal and Caps for your Design « Adafruit Industries – Makers, hackers, artists, designers and engineers!_files/150x150_002.png

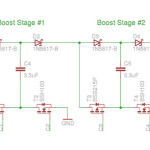
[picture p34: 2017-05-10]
resources/Choosing the Right Crystal and Caps for your Design « Adafruit Industries – Makers, hackers, artists, designers and engineers!_files/150x150_013.jpg

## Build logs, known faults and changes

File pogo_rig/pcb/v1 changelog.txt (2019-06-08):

removed unnecessary test points
changed pogo pin footprint
now using USBC connector
removed unused headers
removed unused LEDs
designed for STM32F042, added DFU button

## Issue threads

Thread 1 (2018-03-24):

LED does not stay lit

modalexii, 2018-03-24:
I think when you zero out the buffer in `exixe::set_led` and then `spi_write()` out that buffer, the LED gets turned off. Maybe unrelated, the LED does not light at all when `set_led()` is called in arduino's `setup()`.

dekuNukem, 2018-03-24:
Did LED work at all?  What kind of Arduino are you using?

I tested the library with an Arduino Uno and Arduino Micro and it seemed fine. I'll try it again tomorrow.

If there is no response from the module at all, then it's more likely something wrong with the wiring, maybe tell me more about it and I'll try to figure it out.

dekuNukem, 2018-03-24:
Here is a barebone sketch that doesn't use the library at all, maybe try it and see?

https://github.com/dekuNukem/exixe/blob/master/arduino_examples/barebone/0_LED_test/0_LED_test.ino

modalexii, 2018-03-25:
The LED works. Using Teensy 3.2 (& 3.5). The barebone sketch works, but it's different than the library - in both barebone sketches, the buffer is never cleared like it is in line 67 of `exixe.cpp`

modalexii, 2018-03-25:
Superficially this seems to fix it (I would submit a pull but the code is locked up in that zip :-) ):

`diff exixe.orig.cpp exixe.new.cpp `

```diff
67c67
<   memset(spi_buf, 0, EXIXE_SPI_BUF_SIZE); // clear SPI buffer
---
>   memset(spi_buf, 0, EXIXE_SPI_BUF_SIZE - 3); // clear SPI buffer except for LED
83d82
<   memset(spi_buf, 0, EXIXE_SPI_BUF_SIZE);// clear SPI buffer
136c135
< }
---
> }
```

dekuNukem, 2018-03-25:
well thanks modalexii! I'll update the library tomorrow and test it again.

dekuNukem, 2018-03-26:
I have updated the library file, please check it out and see if the issue is fixed

I also added the library files outside the zip file, so feel free to submit pull requests.

Closed 2018-04-02.

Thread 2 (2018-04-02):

Arduino library: Initialising multiple tubes doesn't seem to work

jbmorley, 2018-04-02:
I'm finding that initialising multiple exixe instances stops them all from working. For example,

```c
exixe_1 = exixe(cs_pin_1);
exixe_2 = exixe(cs_pin_2);
```

Individually each exixe works, but together, they do not.

I believe this is because the SPI initialisation is performed in the `exixe` method, and therefore called twice. This bit:

```c
  SPI.begin();
  SPI.beginTransaction(SPISettings(8000000, MSBFIRST, SPI_MODE0));
```

Removing this code, and performing it explicitly, just once, beforehand seems to work for me.

I propose introducing a new method, perhaps `begin`, or `setup`, which wraps the SPI setup and means that developers can still benefit from the convenience of using just the exixe library, but can also configure this all themselves if they want to.

dekuNukem, 2018-04-02:
I tested the multi module sketch on an Arduino Uno and Sparkfun Pro Micro and it was working, so I guess it's a ESP32 issue.

Still, it's a good practice to only initialising the SPI once. I'll rewrite and add a `exixe.begin` function tomorrow.

jbmorley, 2018-04-03:
Sounds great. Thanks!

Closed 2018-05-07.

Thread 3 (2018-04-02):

Arduino library: memset not defined

jbmorley, 2018-04-02:
I found that the library (used with the examples) wouldn't compile for me when targeting my Adafruit Huzzah32 ESP32-based board.

The specific issue appears to be that it can't find `memset`. I'm still not very familiar with Arduino and its idiosyncrasies, but some Googlging reveals that this can be fixed by importing Arduino.h.

I've added the following to the top of exixe.cpp and everything works fine:

```
#include "Arduino.h"
```

This could be an issue with my setup but it is, as far as I can tell, the default configuration for the ESP32 boards and I'm not aware I've done anything strange.

dekuNukem, 2018-04-02:
Thanks for the discovery, I don't have a ESP32 myself and apparently it's different.

Isn't `memset` in `string.h`?  Try`#include <string.h>` instead of `Arduino.h` and see if it works. I'll test and update the library tomorrow.

jbmorley, 2018-04-03:
A collection of other symbols seem to be missing with just `#include <string.h>`.

```
/Users/jbmorley/Documents/Arduino/libraries/exixe/exixe.cpp: In constructor 'exixe::exixe(int)':
/Users/jbmorley/Documents/Arduino/libraries/exixe/exixe.cpp:18:19: error: 'OUTPUT' was not declared in this scope
   pinMode(cs_pin, OUTPUT);
                   ^
/Users/jbmorley/Documents/Arduino/libraries/exixe/exixe.cpp:18:25: error: 'pinMode' was not declared in this scope
   pinMode(cs_pin, OUTPUT);
                         ^
/Users/jbmorley/Documents/Arduino/libraries/exixe/exixe.cpp:19:24: error: 'HIGH' was not declared in this scope
   digitalWrite(cs_pin, HIGH);
                        ^
/Users/jbmorley/Documents/Arduino/libraries/exixe/exixe.cpp:19:28: error: 'digitalWrite' was not declared in this scope
   digitalWrite(cs_pin, HIGH);
                            ^
/Users/jbmorley/Documents/Arduino/libraries/exixe/exixe.cpp: In member function 'void exixe::spi_write()':
/Users/jbmorley/Documents/Arduino/libraries/exixe/exixe.cpp:25:24: error: 'LOW' was not declared in this scope
   digitalWrite(cs_pin, LOW);
                        ^
/Users/jbmorley/Documents/Arduino/libraries/exixe/exixe.cpp:25:27: error: 'digitalWrite' was not declared in this scope
   digitalWrite(cs_pin, LOW);
                           ^
/Users/jbmorley/Documents/Arduino/libraries/exixe/exixe.cpp:26:11: error: 'delay' was not declared in this scope
   delay(10);
           ^
/Users/jbmorley/Documents/Arduino/libraries/exixe/exixe.cpp:29:24: error: 'HIGH' was not declared in this scope
   digitalWrite(cs_pin, HIGH);
                        ^
/Users/jbmorley/Documents/Arduino/libraries/exixe/exixe.cpp: In member function 'void exixe::crossfade_init(unsigned char, unsigned int, unsigned char, unsigned char)':
/Users/jbmorley/Documents/Arduino/libraries/exixe/exixe.cpp:107:34: error: 'millis' was not declared in this scope
   animation_start_frame = millis() / EXIXE_ANIMATION_FRAME_DURATION_MS;
                                  ^
/Users/jbmorley/Documents/Arduino/libraries/exixe/exixe.cpp: In member function 'unsigned char exixe::crossfade_run()':
/Users/jbmorley/Documents/Arduino/libraries/exixe/exixe.cpp:116:41: error: 'millis' was not declared in this scope
   unsigned long current_frame = (millis() / EXIXE_ANIMATION_FRAME_DURATION_MS) - animation_start_frame;
                                         ^
Multiple libraries were found for "WiFi.h"
 Used: /Users/jbmorley/Documents/Arduino/hardware/espressif/esp32/libraries/WiFi
 Not used: /Applications/Arduino.app/Contents/Java/libraries/WiFi
exit status 1
Error compiling for board Adafruit ESP32 Feather.
```

dekuNukem, 2018-04-03:
I updated the library just now so try it out.

Feel free to submit pull requests too if there are any other issues.

jbmorley, 2018-04-14:
Thank you so much!

Closed 2018-05-07.

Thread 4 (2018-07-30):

The MISO and MOSI pins are the wrong way around on the getting started page

jbmorley, 2018-07-30:
I've just noticed that the diagram on the getting_started.md page are switched:

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

This could be misleading.

jbmorley, 2018-07-30:
Wonderful. Thanks! 👍

chrisys, 2020-01-06:
@dekuNukem there's a second image on this page that's also wrong, the first one is now correct though

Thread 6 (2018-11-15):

exixe12_bom different capacitor values

BenRoe, 2018-11-15:
Hi,
in the [exixe12_bom.xlsx](https://github.com/dekuNukem/exixe/blob/master/resources/exixe12_bom.xlsx)
C1 has a capacity of 1uF, but in the eagle file it has 100nF (0,1uF).

100nF is the correct value?!

Btw thanks for sharing.

dekuNukem, 2018-11-15:
The capacitors on this board are for decoupling purposes only, so their values doesn't matter that much. Anywhere between 100nF and 1uF works, I used 100nF for my production run and hasn't had any problems.

BenRoe, 2018-11-15:
Ah ok. One more question. Is 0,125 W enough for the resistors?

dekuNukem, 2018-11-15:
Yes, I've measured that the voltage drop at the anode resistor is 44V, that with 68KΩ consumes 0.0284W of power, well below 0.125W.

Closed 2018-11-15.

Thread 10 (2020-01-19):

Windows 10 & STM32 ST-LINK

thijsdeschildre, 2020-01-19:
STM32 ST-LINK Utility (STSW-LINK004) doesn't seem to work on Windows 10.
I had the PCB's made, did an excellent job reflowing the PCB with solder paste, but couldn't connect with the programmer to the STM32. I used exactly the same software, programmer and settings.
After 2-3 hours of fiddling around I looked for another programmer, since the software looked quite old. STM32CubeProgrammer immediately connected to the STM32 and my board is working just fine.

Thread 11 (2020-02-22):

Exixe14 BOM not matching PCB

eben80, 2020-02-22:
Hi,
The labels on the pcb goes up to R28 while the BOM only goes to R25.
This means that i don't know the values for the bottom of pcb.

Thank you

dekuNukem, 2020-02-22:
Is R28 on the bottom layer? If so it is not needed. No components are soldered on bottom side.

eben80, 2020-02-23:
Hi,
Yes the highest R value on the top layer is R24.
So none of the 5 resistor pads need to be populated on the bottom?
I followed the markings on the resistors of your top layer with the posted photo.
Do you by any chance have a photo of the completed bottom of an Exixe14?
Thank you for an awesome design.

dekuNukem, 2020-02-23:
There are no components on the bottom layer at all, let me see if i can find a photo later today.

eben80, 2020-02-23:
OK thank you.

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

dekuNukem, 2020-02-23:
Here's a photo of the bottom side:

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

eben80, 2020-02-23:
Great thank you,
So just to confirm : Even though there's pads for resistors on the bottom,
they should not be populated when assembling my own.

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

dekuNukem, 2020-02-23:
that is correct.

eben80, 2020-02-24:
Thank you very much.

Closed 2020-02-24.

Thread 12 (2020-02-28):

Overdrive doesn't seem to do anything

chrisys, 2020-02-28:
I'm enjoying working with my boards. I have some tubes where certain digits are slightly faded in areas, which I thought the overdrive function could help with.

I've tried enabling it (I'm using the Python library on a Raspberry Pi), but don't seem to see any difference. I don't notice any increase in brightness or any help with the faded areas, so I question if I'm using it correctly. I'm doing `exixe.Exixe(cs_pin_m, spi, overdrive=True)` when initializing. I have 3 tubes next to each other and the one with overdrive turned on looks no different to the others.

So, am I using it incorrectly, or just expecting too much? TIA for any help!

dekuNukem, 2020-03-02:
Hi Chris:

The Python library on Raspberry Pi was ported by a contributor and I haven't tested it myself. It does seem to work on Arduino though:

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

It might be the library, and if you assembled and build the boards yourself, double check the components. And if you're using second-hand tubes, it might be they were so poisoned that even overdrive won't help. Although you probably should see a small difference with it being on and off.

Best Regards,

Allen

Closed 2020-06-03.

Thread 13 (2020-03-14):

Unable to completely turn of the LED

DunderStorm, 2020-03-14:
Hello!

I am unable to turn of the LED completely. When sending

my_tube.set_led(0, 0, 0);

I still get a weak white glow from the LED.

I get the same weak white glow from the LED when I first power a fresh board without connecting it to an arduino.

Is there anyway to fix this besides desoldering R14, R15 & R16.

dekuNukem, 2020-03-15:
This is a minor quirk that actually turned out to be slightly useful. It allows me to tell if a board is programmed or not during assembly, and it also shows if the board is powered on and working.

The dim glow won't be visible once the tube is installed, so I wouldn't worry too much about it.

Closed 2020-06-03.

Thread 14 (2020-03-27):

Mounting methods

spgfr, 2020-03-27:
Is there a preferred method of mounting the exixe board to something other than a breadboard?

chrisys, 2020-06-22:
I mounted mine with SIL headers, like this:

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

Hope this helps with some ideas, at least.

dekuNukem, 2020-06-22:
Hi Chris! Sorry for missing this issue, looks like you're using regular female headers, which is what I use myself. Looks pretty good!

Closed 2020-06-22.

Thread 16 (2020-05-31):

SPI pins

NegativCut, 2020-05-31:
Hi,are the green & blue addresses (spi_buf[14] and [15]) reversed in the Arduino 0_LED sketch? I find they are so I'm wondering if my boards have an issue. Tested 2x boards so far with the same results. exixe12. Thanks.

dekuNukem, 2020-05-31:
According to the [technical details](https://github.com/dekuNukem/exixe/blob/master/technical_details.md), spi_buf[13] should be red, spi_buf[14] should be green, and spi_buf[15] should be blue.

Are you saying on your boards spi_buf[14] and spi_buf[15] are reversed? As in spi_buf[14] is blue and spi_buf[15] is green? If true this is very bizarre indeed, I have never had this issue myself.

Have you tried the [Arduino examples with library](https://github.com/dekuNukem/exixe/blob/master/arduino_examples/1_LED_test/1_LED_test.ino)? And which Arduino board are you using?

NegativCut, 2020-06-01:
Arduino Nano being used.

Here is the code used to get a purple LED... left as original it's yellow.

`/*
  exixe modules:
  https://github.com/dekuNukem/exixe

  library docs:
  https://github.com/dekuNukem/exixe/tree/master/arduino_library

  Demo 1: LED test
*/

#include "exixe.h"

// change this to the cs pin you're using
int cs_pin = 10;
exixe my_tube = exixe(cs_pin);

void setup()
{
  my_tube.spi_init();
}

void loop()
{
  my_tube.set_led(127, 127, 0); // purple
  delay(500);
}`

dekuNukem, 2020-06-01:
This is very strange indeed. This project is more than 3 years old and it is my first time hearing this issue. I'll do a little testing myself.

dekuNukem, 2020-06-02:
Turns out all my Arduinos are at my workplace, and its closed.

I purchased a cheap one online, but it will take a day or two to arrive.

In the meantime, if its convient to do so, can you take a look at your exixe12 module and tell me what it says at the location below? Thanks.

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

NegativCut, 2020-06-02:
Hi, the area shown on the boards I have is blank, If you need a picture, I can supply one later today.

dekuNukem, 2020-06-02:
that would be great, thanks.

NegativCut, 2020-06-02:
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

NegativCut, 2020-06-02:
This one I am building at the moment.

dekuNukem, 2020-06-02:
woah this is a very old revision of the circuit board. It looks like a prototype-stage design from 2017. I didn't know you're building one yourself, I thought you purchased one from my Tindie shop.

Anyway, because this PCB revision is a very early design, I might have changed a few things around since then. The current library and documentation is for the production-run boards. If the swtiched RGB channel is the only issue, then thats actually not too bad!

NegativCut, 2020-06-02:
Yea I bought these off Tindie just during lockdown I've managed to get through a few projects :)
I have uploaded the hex from the repo and am using an Arduino, and all seems well except the RGB...

NegativCut, 2020-06-02:
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

Is this normal behavior running 2_loop_digit_simple?

dekuNukem, 2020-06-02:
It seems to be running a bit fast. In the [arduino code](https://github.com/dekuNukem/exixe/blob/master/arduino_examples/2_loop_digit_simple/2_loop_digit_simple.ino) the digit should be changing every half second, it looks about twice as fast in this gif.

The tube also turns off and flicker for a bit in the middle, if it happens on its own I would start by checking the 3.3V power supply. The 3.3V pin on 5V Arduino can hardly provide enough current for one module, so you might want to try a more beefy power source and see if it improves. I mentioned this issue in the [power consumption considerations](https://github.com/dekuNukem/exixe/blob/master/getting_started.md#power-consumption-considerations) sections of the user manual.

NegativCut, 2020-06-02:
Hmm, I'm running 5v through a 3v3 LD33 separate regulator, max 1A.

The other example, crossfade, is giving weird results. I'm going to try another Arduino to drive the spi.

dekuNukem, 2020-06-02:
The reset pin on the module is pulled up internally, so you don't have to pull it up again, but it wouldn't hurt.

I would check to make sure the SPI output from the arduino is at the correct speed and configuration with a logic analyser or osciliscope. You can [find the details here](https://github.com/dekuNukem/exixe/blob/master/technical_details.md).

NegativCut, 2020-06-02:
Ok, before I break out the saleae, I read the clock speed was tested up to 8Mhz, was there minimum viable during your tests?

dekuNukem, 2020-06-02:
Anything between 1MHz and 24MHz should work, although i would try slower speeds first to be on the safe side.

NegativCut, 2020-06-03:
Hi, so after connecting my Arduino and 3V3 grounds together the 2-digit counting and crossfading sketches are working just fine. I have tested the SPI clock up to 16Mhz and its working just fine.
Thanks for your help and feedback.

dekuNukem, 2020-06-03:
Yeah it's important that everything are at the same GND. Glad to hear it's working now.

Closed 2020-06-03.

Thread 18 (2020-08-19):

Inconsistent behavior with multiple exixe

poitch, 2020-08-19:
I'm trying to drive 4 nixie tubes (with the goal of driving 6 for a clock)

I'm seeing inconsistent behavior. I see either 0, 1, 2 or 3 tubes changing digits. Even when 2 tubes are running, sometimes a digit might not flip.

Based on the documentation, I'm guessing this might be due to a lack of power but the 4 exixe are getting the 3.3V from my power supply directly (3.3V rated at 800mA max) I do have a GPS module connected to the same supply and it is able to run and get a fix.

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

My code currently stores the last digit and calls show_digit when the digit changes for that particular tube
if (digit != tube_digit) {
tube.clear();
tube.show_digit(digit, 127, 0);
tube_digit = digit;
}

.spi_init() is only called once in setup()

If I use the first 2 exixe for seconds then I am able to see them count up based on GPS time. But the next 2 tubes which are hooked up to minutes aren't showing anything, even though I can see in the logs that I am calling show_digit.

I had followed the getting started guide and tested tubes and ran the LED test on the exixe board by themselves.

Any idea on how to debug the issue here? Thank you

dekuNukem, 2020-08-19:
There are a few things that I can think of. First off, check to make sure everything shares the same GND. There might be some noise on the SPI line, so maybe try calling `tube.show_digit()` multiple times in a row and see if it helps. Also, you don't need to call `tube.clear()` every time to update the tube, so maybe try leaving it out for now.

Also, only as a last resort, sometimes breadboards have dead holes in them, so try shifting the components around and see if it helps. This is unlikely, but it did happen to another user!

poitch, 2020-08-20:
I ran into the GND issue while running the LED test yesterday.

I just rewired everything from scratch and with only 2 tubes (no GPS) and made sure the ground was common between the Nano, the exixe, and the power supply.

I experimented some more and things are really bizarre at this point. I can get one tube to work really well when I connect SCK, MOSI, MISO, and CS but as soon as I remove MISO it stops working which does not make any sense.

If I ignore the fact that I shouldn't need MISO and add a second tube using the 4 lines (shared SCK, MOSI, MISO + 2 separate CS) then nothing works anymore. I even tried the multiple ```tube.show_digit()``` calls and removed ```tube.clear()``` that did not change anything.

I tried a few combinations and it seems that as soon as I plug in SCK or MOSI then the first tube stops working.

I have tried 2 different Nanos (unfortunately burnt one out), tried different holes in the breadboard, different jumper cables to no avail.

dekuNukem, 2020-08-20:
This is a bit bizarre indeed. It looks like the power supply board is providing both 170V and 3.3V, can you link the page of where you bought it from? I'd like to read about it a bit.

Other than that, I would suggest start as simple as possible with 1 exixe module, no high-voltage, and just the LED test in the example. If that works fine, expand the LED test to two modules and see if it works consistantly. It would also help if you have a oscilloscopeor logic analyser to see what's going on on the SPI line.

poitch, 2020-08-20:
I bought the power supply from ebay, but here is the [official website](https://www.lumos.sk/high-voltage-power-supply-extended/).

The 3.3V is actually coming from a DC-DC conversion from the 5V line. 5V is its own converter.

I have ordered a logic analyzer so I could see what was going on on the SPI lines.

poitch, 2020-08-21:
Tried again the basic LED test with one exixe only. Both using the 3.3V power supply and the Arduino Nano 3.3V. I did change the sequence to be ```tube.set_led(127, 0, 127); delay(500); tube.clear(); delay(500);```

I cannot get it to work consistently unless I hook up MISO.

It seems like when I fiddle around with the SCK cable I get the LED to light up sometimes, and sometimes it gets purple but in most cases, it is the wrong color. That seems to indicate some noise on the SCK line.

I'm curious though, what is MISO hooked up internally in the exixe to cause it to stabilize so well? I'm wondering if I'm still not sharing GND properly for some reason, but since I have the same problem when using the Arduino's power that seems unlikely.

I've tried a new breadboard and new cables to no avail.

What gauge would you recommend for the cables?

poitch, 2020-08-26:
I have tried quite many things over the last few days.

Looking at the logic analyzer and the decoded SPI messages, I see a lot of noise. Very often I see 0xAA only once out of many messages and even when I get 0xAA the body is usually not correct either. I made sure my logic analyzer was sampling at a multiple of 8MHz and that it was decoding MSB instead of LSB.

I also did try the bare bone example as well to make sure I would only send the one message and the logic analyzer would show garbled data and once in a while the proper message.

I have tried with the probe at the output of Arduino directly as well as along the lines.

With 6 tubes, I usually get only 0x00s on the MOSI line by the 5th tube.

I tried to mess around with the clock to no avail.

The code is the one from your example, so I'm not sure there is a lot of value for me to upload what I downloaded from you :)

Here is one example where I tried to have the 6 tubes connected and do a simple counter with nothing else and as usual saw only some digits light up here and there. As you can imagine with garbled SPI messages, the results are completely random and unpredictable.

```
#include <exixe.h>

#define CS1 10
#define CS2 9
#define CS3 8
#define CS4 7
#define CS5 6
#define CS6 5

exixe tube1 = exixe(CS1);
exixe tube2 = exixe(CS2);
exixe tube3 = exixe(CS3);
exixe tube4 = exixe(CS4);
exixe tube5 = exixe(CS5);
exixe tube6 = exixe(CS6);

void setup() {
  tube1.spi_init();
  tube1.clear();
  tube1.show_digit(0, 127, 0);

  tube2.clear();
  tube2.show_digit(0, 127, 0);

  tube3.clear();
  tube3.show_digit(0, 127, 0);

  tube4.clear();
  tube4.show_digit(0, 127, 0);

  tube5.clear();
  tube5.show_digit(0, 127, 0);

  tube6.clear();
  tube6.show_digit(0, 127, 0);
}

uint16_t count;

void loop() {
  count = (count + 1) % 100000;
  uint8_t v = (count / 100000) % 10;
  tube1.show_digit(v, 127, 0);

  v = (count / 10000) % 10;
  tube2.show_digit(v, 127, 0);

  v = (count / 1000) % 10;
  tube3.show_digit(v, 127, 0);

  v = (count / 100) % 10;
  tube4.show_digit(v, 127, 0);

  v = (count / 10) % 10;
  tube5.show_digit(v, 127, 0);

  v = (count / 1) % 10;
  tube6.show_digit(v, 127, 0);

  delay(300);
}
```

dekuNukem, 2020-08-26:
If attaching a probe changes the stability of the system, then it does seem like a noise issue. Is the SPI output correct straight from the Arduino pins when no exixe is connected? The logic analyzer sample rate doesn't haveto be multiples of SPI clock, just more than twice as fast is enough.

It would be great if you can post a screenshot of the logic analyzer capture of the problem SPI waveforms too.

poitch, 2020-08-28:
Yes, I had seen the capture which was really helpful in configuring my own logic analyzer.

See attached a capture straight out of the Arduino's pins. Arduino was just on a mat without nothing else plugged in. Only the USB to my computer and the probes of the logic analyzer on the header pins.

As you can see most messages aren't what they are supposed to be and eventually the header gets garbled and thus missed.

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

In this particular capture, 3 consecutive messages looked like this:
0xAA 0x80 0x80 0x80 0x80 0x80 0x80 0x00 0x80 0x80 0x80 0x80 0x00 0xFF 0x80 0xFF
0xAA 0x80 0x80 0x00 0x80 0x80 0x00 0x80 0x80 0x80 0x00 0x80 0x80 0xFF 0x01 0xFF
0x01 0x01 0x01 0x01 0x00 0x01 0x01 0x01 0x01 0x01 0x01 0x01 0x01 0x01 0xFF 0x01 0xFF

Here is the code that generated those captures:
```
#include <SPI.h>
#define SPI_BUF_SIZE 16
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
dekuNukem, 2020-08-28:
It looks like you have found the issue. If the SPI data is corrupted straight out of the arduino, then it's not suprising that exixe isn't working consistently as a result.

It is very strange to see SPI broken like this. The MOSI data is supposed to be valid and stable on the `rising` clock edge, so maybe check if that is the case.

You mentioned that you have tried a few different arduinos. Are they all like this?

RandomNameHere, 2020-09-19:
Hmm, I seem to have the exact same issue. No problems with single tubes at all, but running any more than one will cause numbers to not refresh, completely go away, or even have 2 numbers on the same tube. I don't understand the SPI data is getting corrupted (assuming that's the issue).

dekuNukem, 2020-09-19:
hi RandomNameHere! What microcontroller board are you using?

RandomNameHere, 2020-09-20:
Hey, I'm using a pro micro. Although I used an oscilloscope and figured the data isn't corrupt or anything. It seems that 3.3 volts isn't enough to consistently power multiple exixe modules. This is extremely strange to me. I am however using a linear voltage regulator to drop the input current down to 3.3 volts. The actual power source for the device is a 5 volt wall wart. No issues there and the input voltage is consistent. I don't see how the modules are requiring a higher voltage.

dekuNukem, 2020-09-20:
Can you post a photo of your setup?

I think I might have a pro micro somewhere too, and I'll try it out tomorrow if i can find it.

RandomNameHere, 2020-09-20:
Oh boy, I think I'm a huge idiot. I realized that I didn't run the CS lines through voltage regulators which was causing the exixe's to trigger off clock. I'm fixing it now and I don't think there should be issues otherwise.

User12512, 2022-02-09:
Sorry to wake this thread up after two years, but I'm having this exact issue. Random digits and backlight LED settings flashing only occasionally instead of the digit that was connected. I'm attempting to power 6 boards (currently have 3 rigged up at the moment) and using an LM2596 buck converter to power them with sufficient current. My ground is common between all components. From what I've gathered, this is an issue with the SPI lines but I don't see how that happens. RandomNameHere said having voltage regulators on each CS line would fix the problem, but would that be necessary? I just have digital pins connected directly to the CS pins on each exixe board.

dekuNukem, 2022-02-12:
Hi there! Sorry about missing the notification. Let's start simple with only one exixe module. Does that work reliability? Can you also let me know which microcontroller you're using, thanks!

User12512, 2022-02-14:
> Hi there! Sorry about missing the notification. Let's start simple with only one exixe module. Does that work reliability? Can you also let me know which microcontroller you're using, thanks!

Ok. One exixe works perfectly, but at two and up I get what others have mentioned - random digits and at times more than one illuminated. The backlight also goes from off to blue at random, even though in my code I commanded it to be dim. I'm using a single Arduino Uno to make the digits go from 00 through 99. Here's what that looks like:

https://user-images.githubusercontent.com/99311123/153782081-1ee7174f-7903-4f69-8bc3-87e1d8984625.mov

dekuNukem, 2022-02-14:
It could be a power issue, or even bad holes on the breadboard.

I wrote some suggestions at the [troubleshooting section](https://github.com/dekuNukem/exixe/blob/master/getting_started.md#troubleshooting), maybe try some of them out and see if it improves.

User12512, 2022-02-26:
Hey, sorry for such a long delay. I'm going ahead with putting together the module I'm trying to build, it's going to be entirely solder joints and prototyping board with header pins just so nothing's absolutely permanent. I'll let you know if it doesn't work after that.

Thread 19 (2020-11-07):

Random blinking numbers and inconsistent LED behaviour

Eternoxy, 2020-11-07:
Hello there,

i got myself some nixie tubes and the IN14 driver boards.
I tried hooking up the cables as shown in the getting started page and double checked the connections.
Then I tried running the LED-test code as prescribed. I could change the colour of the LED, but it also happened, that the LED changed randomly from bright to low white(ish) and to purple. So no consistent behaviour here.
When I tried the digit loop, the LED start blinking random, changing colour between purple and red and the digits of the Nixie tube show up, but in a random way and definetly not all 0.5s.
What could be possibly wrong and what else could I try to get this thing working?

I figured out several things what could be, but I´m not sure how to fix this.
What do you mean with RST must be high/low and how can I change this?

Should i attach a video with my current setup?

I´m not an electronic expert and I´m just starting to dive in the world of Arduino & Co, but I still want to figure out whats wrong and get this thing working. Unfortunately I dont own a logic analyzer yet. Would such a thing help figuring out the issue?

As a result i want 6 Nixie tubes showing a clock and changing to user defined values whenever i want it.
Its maybe still a long and bumpy road till there, but I think I can make it with some help.

dekuNukem, 2020-11-07:
Hi eternoxy! It would be great if you can provide a photo / video of your setup so I can take a closer look.

From what you describe it seems that the SPI command might be corrupted one way or the other. Does it happen to all the modules, or just one? The RST pin should be connected to 3.3V.

Eternoxy, 2020-11-07:
Hello dekuNukem,

thank you very much for your quick reply.
I did some more desperate testing and got some positive results with the RST connected to 3.3V but I´m still not there yet.
But at least I can say that the wiring should be correct.

I can now reliable change the LED colour. I can verify it by changing the RGB values in the arduino sketch. Sidenote here: I have to reconnect the power supply (sometimes several times) after uploading the sketch, the reset button won´t work to see an effect.

Next step would be getting the simple digit loop to work.
But when i upload the sketch and reconnect the power supply, i get a blue LED and nothing else.
I can confirm that the nixie tubes and the power supply works, because when i disconnect the 3.3V from RST pin, "magical" things happen and the whole thing goes blinkie blinkie but not the way its supposed to ;)

Any ideas?
I can provide a photo or video tomorrow. The way its built now you probably wont be able to see any mistake between all the beginning mistakes im currently doing.

Eternoxy, 2020-11-08:
Ok, after some more testing i could also get the simple digit loop kind of to work.

This gives me a red 3 after uploading the code and reconnecting RST to 3.3V.

`  my_tube.set_led(127, 0, 0);
   my_tube.show_digit(3, 127, 0);`

How will the digit loop work without reconnecting the RST pin every time?
Does it still need kind of a resistor?

dekuNukem, 2020-11-08:
I guess you can connect the RST pin to a digital pin on arduino. At the very start of the sketch make it go down like 50 milliseconds then back up, this will reset the module, then you program can start as usual :)

Eternoxy, 2020-11-08:
I´ve tried this now and it worked out:

`/*
  exixe modules:
  https://github.com/dekuNukem/exixe

  library docs:
  https://github.com/dekuNukem/exixe/tree/master/arduino_library

  Demo 2: loop digits
*/

#include "exixe.h"

// change this to the cs pin you're using
int cs_pin = 10;
unsigned char count;

exixe my_tube = exixe(cs_pin);
int rst_pin = 9;
void setup()
{
  my_tube.spi_init();
  my_tube.clear();
  pinMode(rst_pin, OUTPUT);
  digitalWrite(rst_pin, LOW);
  delay (50);
  digitalWrite(rst_pin, HIGH);
}

void loop()
{
  count++;
  my_tube.set_led(127, 0, 0); // purple
  /*
  1st arg: Digit to show, 0 to 9
  2nd arg: Digit brightness, 0 to 127
  3rd arg: Overdrive, 0 disable 1 enable
  */
  my_tube.show_digit(count, 127, 0);
  delay(500);
}`

Pin 9 is connected to RST.

I hope this  helps someone out. I can´t understand though why it worked for you without connecting the RST pin.

dekuNukem, 2020-11-08:
Great to hear that you got it working! I would put the reset right at the very beginning, and also give it a delay after it goes high. Something like this:

```
void setup()
{
  pinMode(rst_pin, OUTPUT);
  digitalWrite(rst_pin, LOW);
  delay (50);
  digitalWrite(rst_pin, HIGH);
  delay(50);
  my_tube.spi_init();
  my_tube.clear();
}
```
But if it works, it works!

The reason it worked for me without connecting to the RST pin is that it is weakly pulled up internally with a resistor around 13K, so it would stay high if nothing is connected to it. However if the circuit is noisy it's better to be sure and connect it properly.

Eternoxy, 2020-11-09:
Ok, i´ll try it also this way.
Thanks again for your quick and super helpful support!!!

I might have to ask something again, but thats it for now.
Wish me luck with the coding for the clock.

Closed 2020-11-09.

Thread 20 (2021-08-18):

The exixe 2018 boards not working

TheMobas0, 2021-08-18:
I have two exixe 2017 boards that work just fine, but when i tested the exixe 2018 boards with the same set-up, they didn't work.

dekuNukem, 2021-08-18:
hi there! Can you describe the issue in a bit more detail? Also let me know your order number and I can look it up too.

TheMobas0, 2021-08-18:
Hi, my order number is #273464. I've attached two nixies to two new 2018 exixe-14 boards, and then I put them on a breadboard and connected it, but then I turned it on the nixie tubes weren't working. I tried that exact set-up with my two other 2017 exixe boards and they worked just fine. Also am using a Raspberry Pi 4 and Python.

TheMobas0, 2021-08-19:
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
Added a photo to show one 2018 exixe board and one 2017 exixe board for context.

dekuNukem, 2021-08-19:
The soldering on the pin header on the upper board seems to be a bit iffy, especially the reset pin, I would suggest make sure they have good contact and no cold solder joints.

I would also suggest try starting with the simplest example, [LED test](https://github.com/dekuNukem/exixe/blob/master/arduino_examples/1_LED_test/1_LED_test.ino), see if the LED changes colour, and go from there.

Also, the year and production run is printed in the back of the modules, feel free to let me know the markings on yours.

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

TheMobas0, 2021-08-19:
LEDs work on both the 2017 and 2018 boards. My working 2017 boards have the number on the back but the 2018 don't. I attached pictures of both back and front of my 2018 boards.
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

dekuNukem, 2021-08-20:
You have tested the tubes before installing them right? That might well be the issue here. Make sure the HV pin is soldered properly.

Anyway, if it turns out to be an hardware issue with the board, I can send you a few replacement modules with the latest production date so you can try them out.

TheMobas0, 2021-08-20:
Yes, I tested both tubes before soldering them onto the boards. Also i rechecked the HV pin and its soldered properly.

dekuNukem, 2021-08-20:
Sure, I'll send you two replacement exixe14 boards to try out, same address as the order #273464?

TheMobas0, 2021-08-21:
Sorry, I made a mistake, it's actually order #270289 (the order where I purchesed the 2 not working exixes). Even Though the adresses should be the same.

TheMobas0, 2021-09-14:
Hello, I recieved my replacement exixes yesterday and finished desoldering and soldering today. The exixes work perfectly and the low-temprature solder was perfect for desoldering the nixies off the broken exixes. Thank you.

dekuNukem, 2021-09-14:
Glad to hear it worked out! Those low temp solders are amazingly versatile, perfect for desoldering chips without damaging them!

Closed 2021-09-14.

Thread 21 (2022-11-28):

sourcing STM32F030K6T6

thijsdeschildre, 2022-11-28:
Are there any requirements for the type of STM32F being used?
Availability of these chips is still bad. From what I can see, it needs to support the SPI bus and be in 32-LQFP footprint?

dekuNukem, 2022-11-28:
Yeah the availability of those chips is still very low, and cost has gone way up, that's why I'm not doing a production run right now.

Anyway, it has to support SPI, in LQFP32, and also has hardware timer PWM output on all cathode pins for smooth dimming. So I STM32F042K6T6 / K4T6 are pretty much the only option. You can also try QFN32 variants, but that would require redesigning the circuit board a bit.

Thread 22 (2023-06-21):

Created and assembled board, connected to ST Link V2

Mmma2345, 2023-06-21:
Hi DekuNukem,

so, firstly a massive thanks for the project; this is exactly what I’m looking for !

I’m also a beginner in electronics. But am a very quick learner. Before starting this I have done research and practiced using various boards etc.
so I believe my soldering job is half decent.

I’ve had the boards printed (Exixe-14)
I’ve assembled 1 board so far using the BOM provided and attached a working (and tested) IN-14 Nixie Tube.

I’ve soldered pins to pads :
3.3v
GND
DIO
CLK

from here I’ve attached the four pins via jumper wires to a ST LINK V2 as suggested. With the suggested software.

I click the button to link to the STM32 via the software but an error appears showing : no st link found ( I’m writing this from memory so will double check the wording of this when next at the pc! )

I also checked the voltage across the GND and 3.3v pins when connected to the ST LINK V2 with a multimeter; this only showed around 0.1volts.
but once disconnected the ST LINK V2 showed 3,3volts again. Seems odd ?

Any helps would be great!!

Mmma2345, 2023-07-02:
Turns out I had on positions C2, C3 a Feed through Capacitor, which was reducing the voltage to the circuit?

So Ive replaced this for a normal/ correct one and now the circuit has power.

But now/ still I am having issues connecting to the STlink Utility, it does not connect.

Please, if there is anything you can suggest to do?

Michail1, 2024-04-04:
If you include pictures, it may help in determining your problem.  After the CAP changes, were you able to have 3.3v?  Provide a HD picture of your board and I might be able to spot any issue.  (I've made many board and they work).  Also, provide picture of your STLink wiring.  Might be something as simple as wrong wiring.
Just try a firmware up on the STLink without anything connected just to see if the computer can at least talk to the programmer.
Then wire and try the board or boards you have made.  eMail me directly for other help and pictures.

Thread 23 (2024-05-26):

STM32 ST-LINK Utility Error (Can not connect to target!)

ccmilbrot, 2024-05-26:
I'm new to building and SMD components to pcb and have run into a problem trying to load the firmware to the STM-32  module. Attached is a photo of the error I'm running into, plus the front and back of the Exixe-12 board I soldered the components onto (maybe I messed that up).

Hoping someone can help me out or point me in the right direction.

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

ccmilbrot, 2024-06-02:
I solved this on my own. The cables that came with my ST-LINK V2 clone were too long at 18cm. I cut all the wires down to 10cm and reconnected them between the ST-LINK V2 and the Exixe12 board and launched STM32 ST-LINK Utility and it immediately connected to the target
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

Michail1, 2025-05-16:
Glad you got it to work, but I don't think the length was the issue.  My leads are about two feet without a problem; however, I don't use bread boards.  I wonder if the connection is simply poor enough to have caused the issue.  Also consider using a test rig with pogo pins or the pogopin rig in the github.

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

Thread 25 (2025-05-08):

Still viable?

jet438, 2025-05-08:
Is this still a viable project to buy a premade board?

nobodydontknow, 2025-05-09:
I'm also interested in this. I submitted once to PCBWay for another project (BlueSCSI) but that one had CSV files for the BOM and pick and play info. I didn't see that in this project.

Michail1, 2025-05-15:
I think he stopped making them a couple of years ago.  I have since started making my own since I use them alot.
You're welcome to email me for help/info.     M1@Michail.com

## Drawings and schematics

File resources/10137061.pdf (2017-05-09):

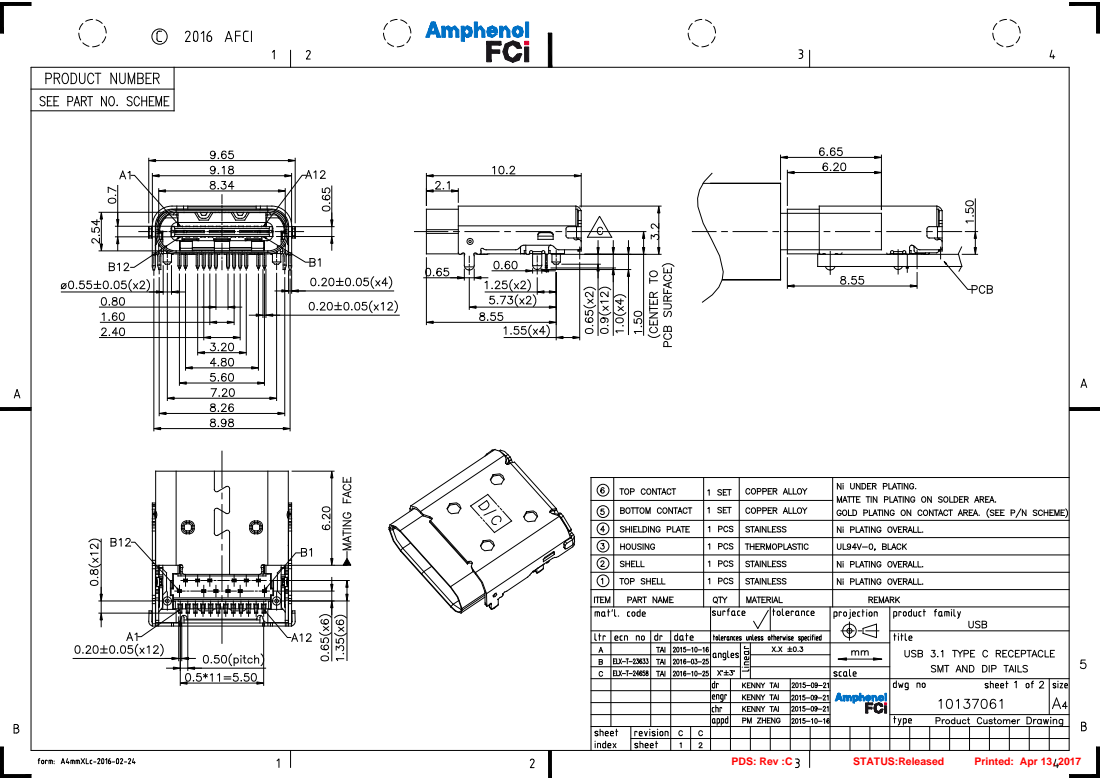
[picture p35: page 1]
PDS: Rev :C; STATUS:Released; Printed: Apr 13, 2017

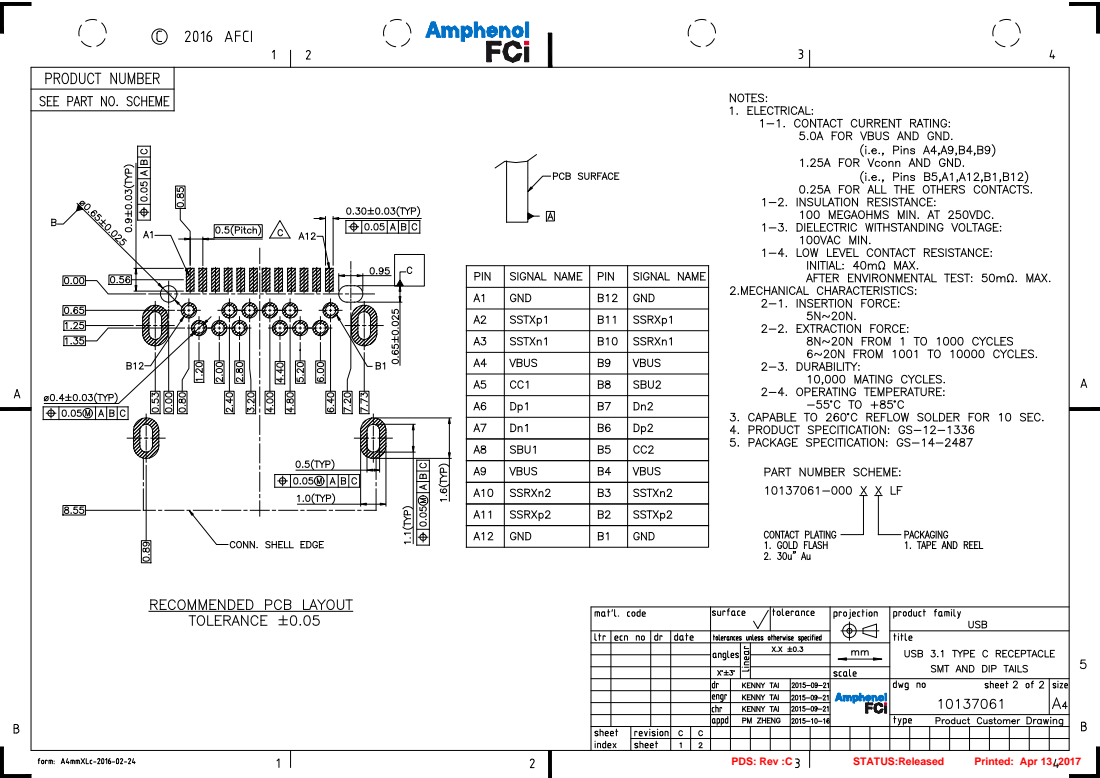
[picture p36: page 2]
PDS: Rev :C; STATUS:Released; Printed: Apr 13, 2017

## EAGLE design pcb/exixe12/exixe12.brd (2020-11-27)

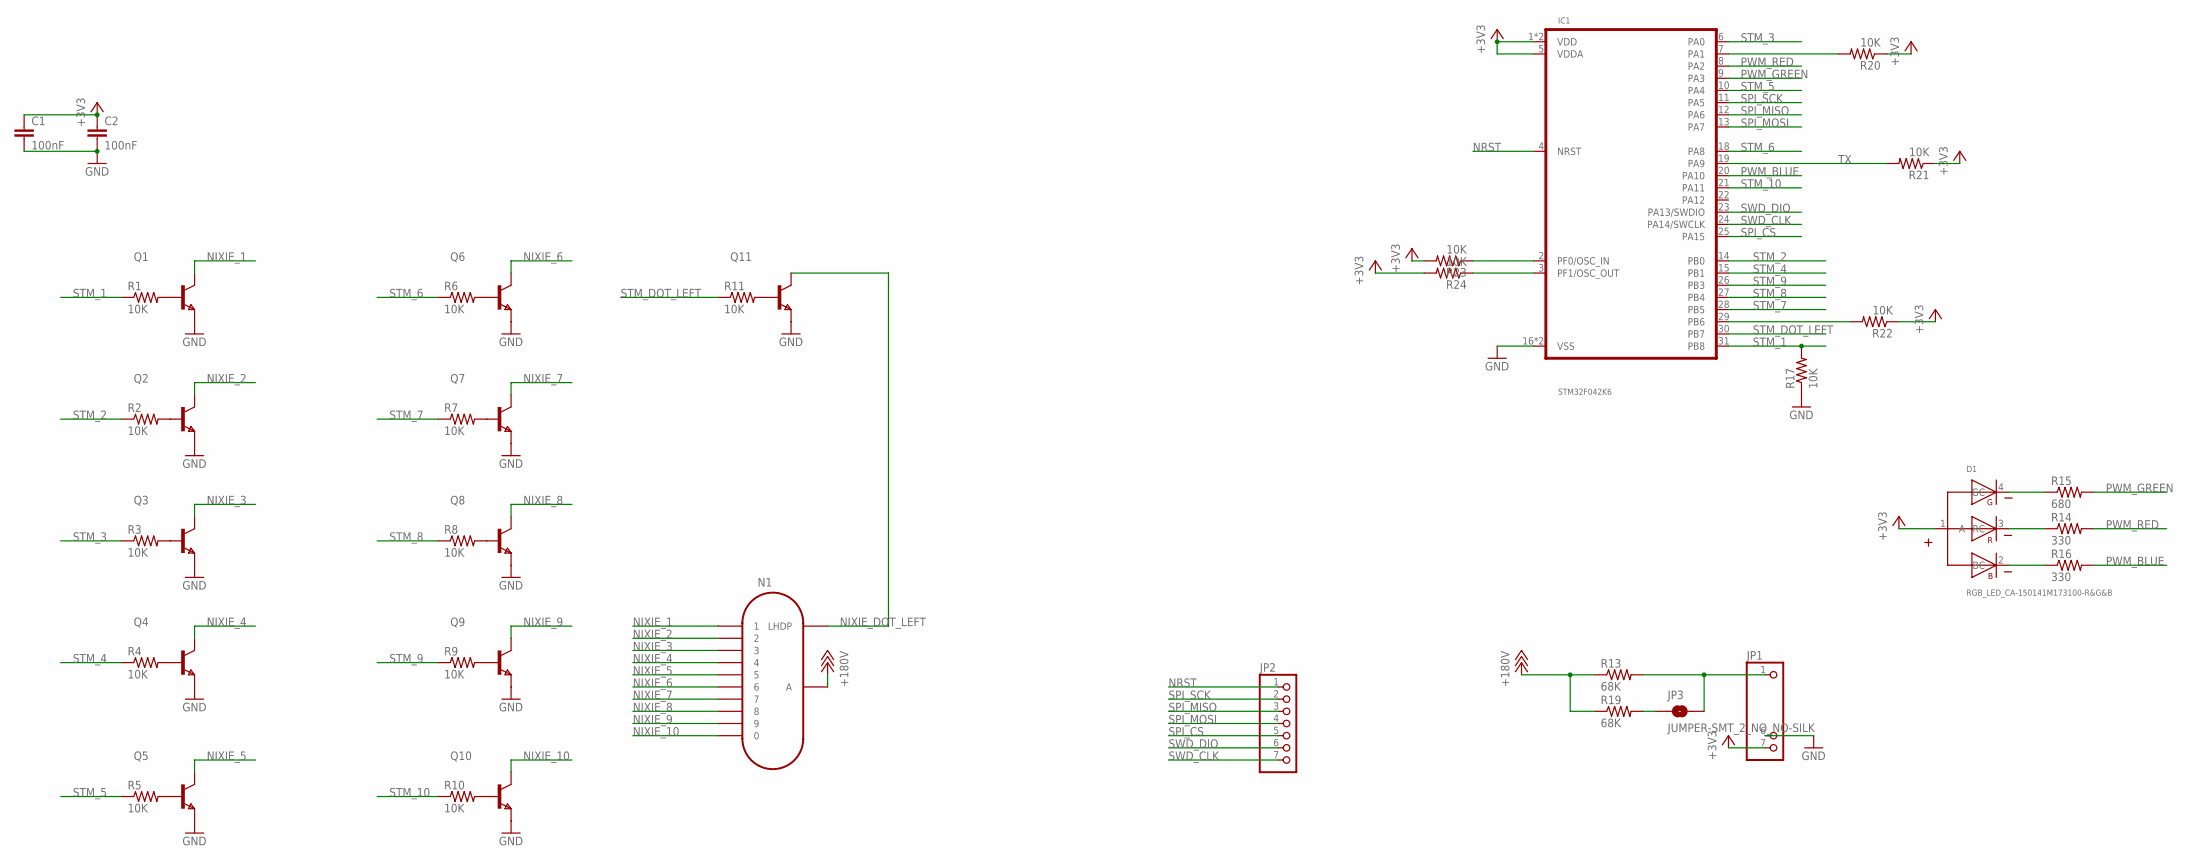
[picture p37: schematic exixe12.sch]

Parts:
C1, C2: 100nF; 0805
D1: RGB_LED_CA-150141M173100-R&G&B; 3528-COMMON-ANODE
IC1: STM32F042K6; TQFP32-08
JP1, JP2: PINHD-1X7; 1X07
JP3: JUMPER-SMT_2_NO_NO-SILK; SMT-JUMPER_2_NO_NO-SILK
N1: IN-12B; IN-12
Q1, Q2, Q3, Q4, Q5, Q6, Q7, Q8, Q9, Q10, Q11: BF820; SOT323
R1, R2, R3, R4, R5, R6, R7, R8, R9, R10, R11, R17, R20, R21, R22, R23, R24: 10K; 0805
R13, R19: 68K; 0805
R14, R16: 330; 0805
R15: 680; 0805

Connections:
+3V3: C1.1, C2.1, D1.1 (A), IC1.1 (VDD), IC1.5 (VDDA), IC1.17 (VDD), JP1.7, R20.1, R21.1, R22.1, R23.2, R24.2
+180V: N1.A, R13.1, R19.1
GND: C1.2, C2.2, IC1.16 (VSS), IC1.32 (VSS), JP1.6, Q1.2 (E), Q2.2 (E), Q3.2 (E), Q4.2 (E), Q5.2 (E), Q6.2 (E), Q7.2 (E), Q8.2 (E), Q9.2 (E), Q10.2 (E), Q11.2 (E), R17.1
unnamed: Q1.1 (B), R1.2
unnamed: JP3.1, R19.2
unnamed: D1.4 (GC), R15.1
unnamed: Q2.1 (B), R2.2
unnamed: Q3.1 (B), R3.2
unnamed: Q4.1 (B), R4.2
unnamed: Q5.1 (B), R5.2
unnamed: Q6.1 (B), R6.2
unnamed: Q7.1 (B), R7.2
unnamed: Q8.1 (B), R8.2
unnamed: Q9.1 (B), R9.2
unnamed: Q10.1 (B), R10.2
unnamed: Q11.1 (B), R11.2
unnamed: IC1.29 (PB6), R22.2
unnamed: D1.3 (RC), R14.1
unnamed: IC1.2 (PF0/OSC_IN), R23.1
unnamed: IC1.3 (PF1/OSC_OUT), R24.1
unnamed: JP1.1, JP3.2, R13.2
unnamed: IC1.7 (PA1), R20.2
unnamed: D1.2 (BC), R16.1
NIXIE_1: N1.1, Q1.3 (C)
NIXIE_2: N1.2, Q2.3 (C)
NIXIE_3: N1.3, Q3.3 (C)
NIXIE_4: N1.4, Q4.3 (C)
NIXIE_5: N1.5, Q5.3 (C)
NIXIE_6: N1.6, Q6.3 (C)
NIXIE_7: N1.7, Q7.3 (C)
NIXIE_8: N1.8, Q8.3 (C)
NIXIE_9: N1.9, Q9.3 (C)
NIXIE_10: N1.0, Q10.3 (C)
NIXIE_DOT_LEFT: N1.LHDP, Q11.3 (C)
NRST: IC1.4 (NRST), JP2.1
PWM_BLUE: IC1.20 (PA10), R16.2
PWM_GREEN: IC1.9 (PA3), R15.2
PWM_RED: IC1.8 (PA2), R14.2
SPI_CS: IC1.25 (PA15), JP2.5
SPI_MISO: IC1.12 (PA6), JP2.3
SPI_MOSI: IC1.13 (PA7), JP2.4
SPI_SCK: IC1.11 (PA5), JP2.2
STM_1: IC1.31 (PB8), R1.1, R17.2
STM_2: IC1.14 (PB0), R2.1
STM_3: IC1.6 (PA0), R3.1
STM_4: IC1.15 (PB1), R4.1
STM_5: IC1.10 (PA4), R5.1
STM_6: IC1.18 (PA8), R6.1
STM_7: IC1.28 (PB5), R7.1
STM_8: IC1.27 (PB4), R8.1
STM_9: IC1.26 (PB3), R9.1
STM_10: IC1.21 (PA11), R10.1
STM_DOT_LEFT: IC1.30 (PB7), R11.1
SWD_CLK: IC1.24 (PA14/SWCLK), JP2.7
SWD_DIO: IC1.23 (PA13/SWDIO), JP2.6
TX: IC1.19 (PA9), R21.2

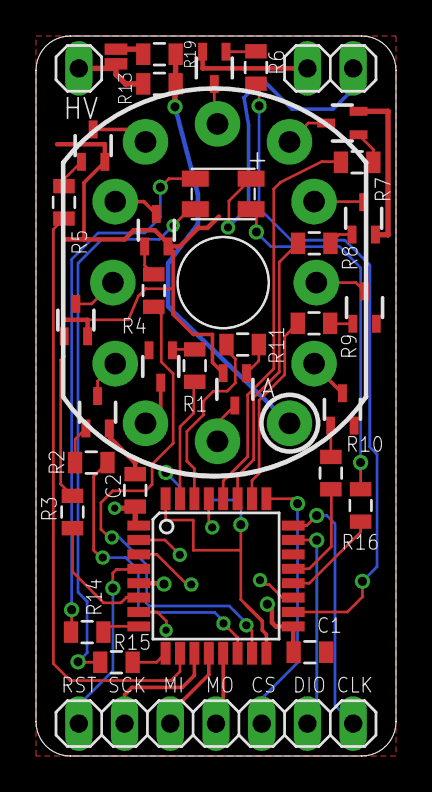
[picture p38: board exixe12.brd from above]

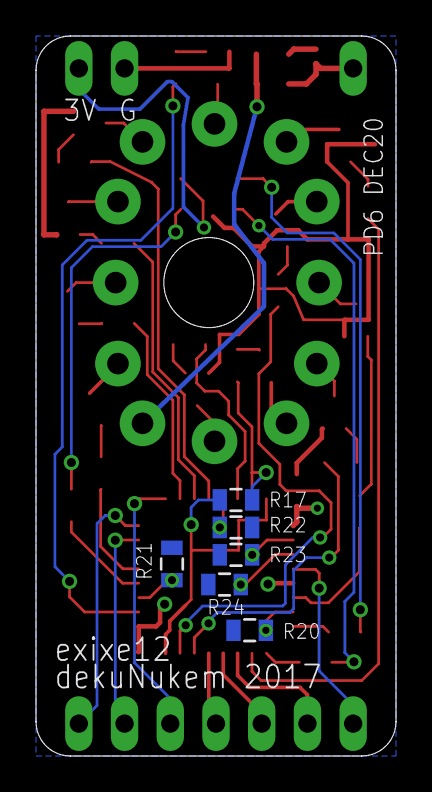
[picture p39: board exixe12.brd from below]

Board: 2 copper layers, 20.0 x 40.0 mm, 41 parts (6 on the bottom side), 56 nets.

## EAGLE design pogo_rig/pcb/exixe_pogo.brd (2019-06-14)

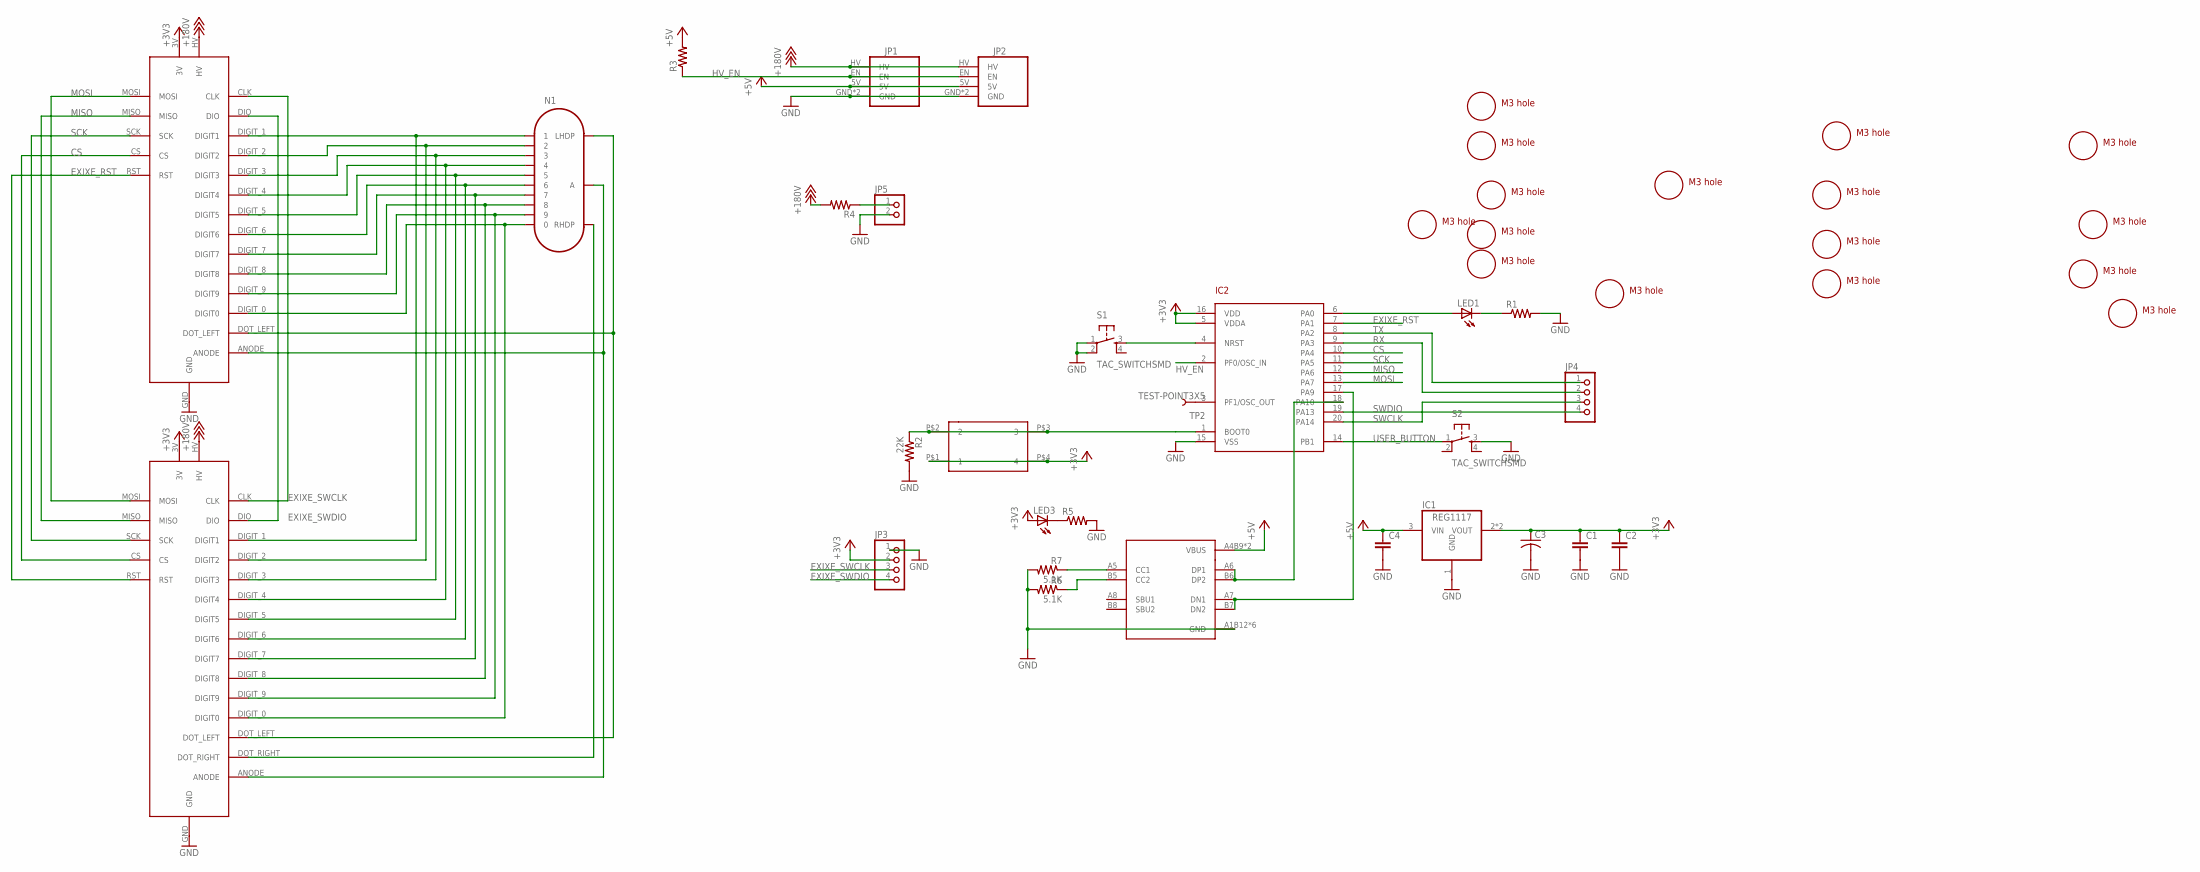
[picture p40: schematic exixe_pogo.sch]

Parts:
C1, C2, C4: CAP0805; 0805
C3: C-USC1210; C1210
IC1: REG1117; SOT223
IC2: STM32F030F4; TSSOP20
JP1: EBAY_MODULEEBAY; EBAY_PKG
JP2: EBAY_MODULETAOBAO; TAOBAO_PKG
JP3, JP4: PINHD-1X4; 1X04
JP5: PINHD-1X2; 1X02
LED1, LED3: LEDCHIP-LED0805; CHIP-LED0805
N1: IN-14
R1, R3, R4, R5: RESISTOR0805-RES; 0805
R2: 22K; 0805
R6, R7: 5.1K; 0805
S1, S2: TAC_SWITCHSMD; TACTILE-SWITCH-SMD
SW2: 324_SW324_SWITCH_FOOT_HOLE; 342_SWICH_FOOT_HOLE
TP2: TEST-POINT3X5; PAD.03X.05
U1: USBC_16P_CENTERED; USBC_16P_FOOT
U$1: EXIXE12_POGO; EXIXE12_PAC
U$2: EXIXE14_POGO; EXIXE14_PAC
U$3, U$4, U$5, U$6, U$7, U$8, U$9, U$10, U$11, U$12, U$13, U$14, U$15, U$16, U$17, U$18: M3_MOUNTING_HOLE; M3_MOUNTING_HOLE_PACK

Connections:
+3V3: C1.1, C2.1, C3.1, IC1.2 (VOUT), IC1.4 (VOUT), IC2.5 (VDDA), IC2.16 (VDD), JP3.2, LED3.A, SW2.P$1 (1), SW2.P$4 (4), U$1.3V, U$2.3V
+5V: C4.1, IC1.3 (VIN), JP1.5V, JP2.5V, R3.2, U1.A4B9 (VBUS), U1.B4A9 (VBUS)
+180V: JP1.HV, JP2.HV, R4.2, U$1.HV, U$2.HV
CS: IC2.10 (PA4), U$1.CS, U$2.CS
EXIXE_RST: IC2.7 (PA1), U$1.RST, U$2.RST
EXIXE_SWCLK: JP3.3, U$1.CLK, U$2.CLK
EXIXE_SWDIO: JP3.4, U$1.DIO, U$2.DIO
GND: C1.2, C2.2, C3.2, C4.2, IC1.1 (GND), IC2.15 (VSS), JP1.GND, JP1.GND2 (GND), JP2.GND, JP2.GND2 (GND), JP3.1, JP5.2, R1.2, R2.2, R5.2, R6.2, R7.2, S1.1, S1.2, S2.3, U1.A1B12 (GND), U1.B11A12 (GND), U1.P$13 (GND), U1.P$14 (GND), U1.P$15 (GND), U1.P$16 (GND), U$1.GND, U$2.GND
HV_EN: IC2.2 (PF0/OSC_IN), JP1.EN, JP2.EN, R3.1
MISO: IC2.12 (PA6), U$1.MISO, U$2.MISO
MOSI: IC2.13 (PA7), U$1.MOSI, U$2.MOSI
unnamed: N1.1, U$1.DIGIT_1 (DIGIT1), U$2.DIGIT_1 (DIGIT1)
unnamed: IC2.4 (NRST), S1.3
unnamed: N1.2, U$1.DIGIT_2 (DIGIT2), U$2.DIGIT_2 (DIGIT2)
unnamed: N1.3, U$1.DIGIT_3 (DIGIT3), U$2.DIGIT_3 (DIGIT3)
unnamed: N1.4, U$1.DIGIT_4 (DIGIT4), U$2.DIGIT_4 (DIGIT4)
unnamed: N1.5, U$1.DIGIT_5 (DIGIT5), U$2.DIGIT_5 (DIGIT5)
unnamed: N1.6, U$1.DIGIT_6 (DIGIT6), U$2.DIGIT_6 (DIGIT6)
unnamed: N1.7, U$1.DIGIT_7 (DIGIT7), U$2.DIGIT_7 (DIGIT7)
unnamed: N1.8, U$1.DIGIT_8 (DIGIT8), U$2.DIGIT_8 (DIGIT8)
unnamed: N1.9, U$1.DIGIT_9 (DIGIT9), U$2.DIGIT_9 (DIGIT9)
unnamed: N1.0, U$1.DIGIT_0 (DIGIT0), U$2.DIGIT_0 (DIGIT0)
unnamed: N1.RHDP, U$2.DOT_RIGHT
unnamed: N1.LHDP, U$1.DOT_LEFT, U$2.DOT_LEFT
unnamed: N1.A, U$1.ANODE, U$2.ANODE
unnamed: LED1.C, R1.1
unnamed: IC2.6 (PA0), LED1.A
unnamed: JP5.1, R4.1
unnamed: IC2.18 (PA10), U1.A6 (DP1), U1.B6 (DP2)
unnamed: IC2.17 (PA9), U1.A7 (DN1), U1.B7 (DN2)
unnamed: IC2.3 (PF1/OSC_OUT), TP2.P$1
unnamed: IC2.1 (BOOT0), R2.1, SW2.P$2 (2), SW2.P$3 (3)
unnamed: R6.1, U1.B5 (CC2)
unnamed: R7.1, U1.A5 (CC1)
unnamed: LED3.C, R5.1
RX: IC2.9 (PA3), JP4.2
SCK: IC2.11 (PA5), U$1.SCK, U$2.SCK
SWCLK: IC2.20 (PA14), JP4.3
SWDIO: IC2.19 (PA13), JP4.4
TX: IC2.8 (PA2), JP4.1
USER_BUTTON: IC2.14 (PB1), S2.1

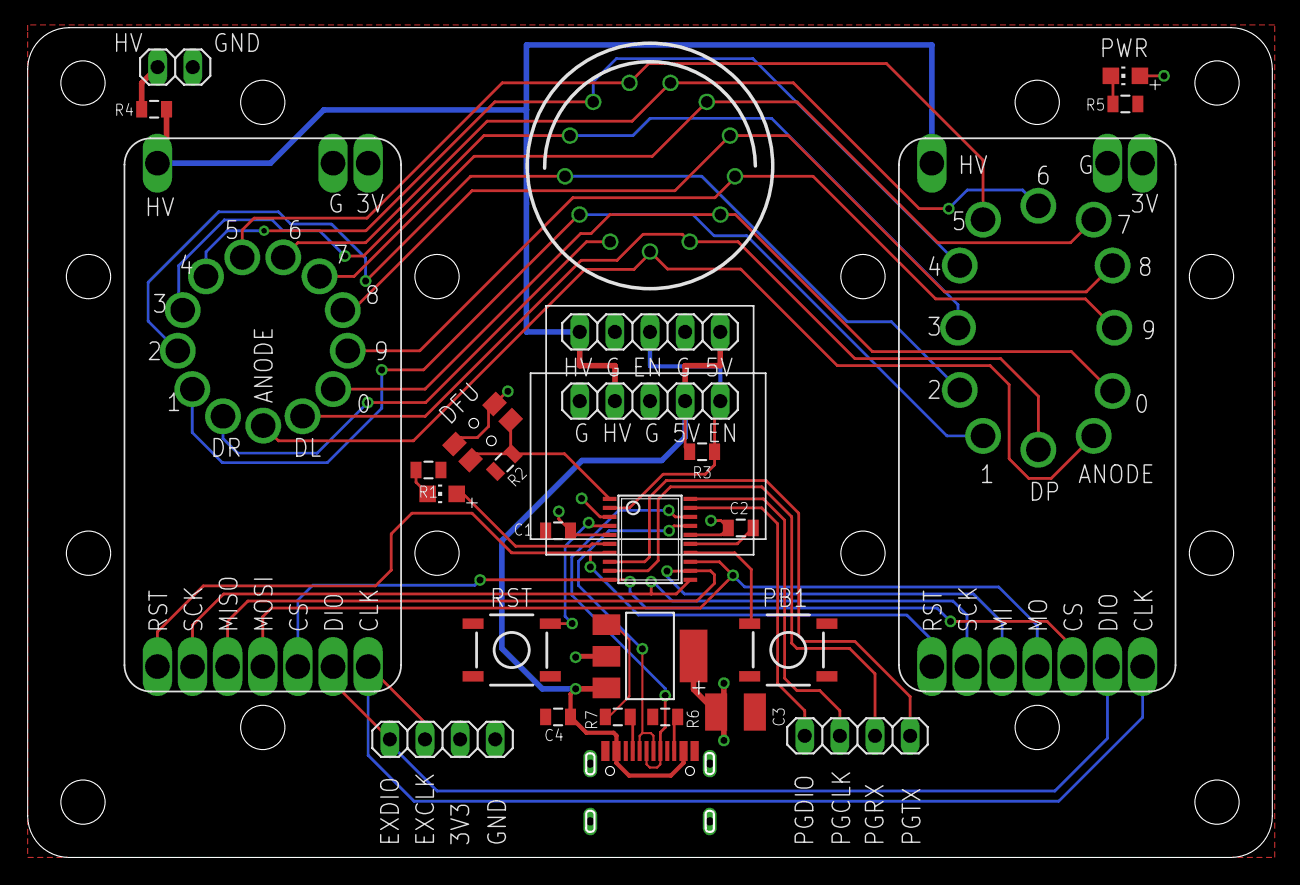
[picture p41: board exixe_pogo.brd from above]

Board: 2 copper layers, 90.0 x 60.0 mm, 44 parts (1 on the bottom side), 41 nets.

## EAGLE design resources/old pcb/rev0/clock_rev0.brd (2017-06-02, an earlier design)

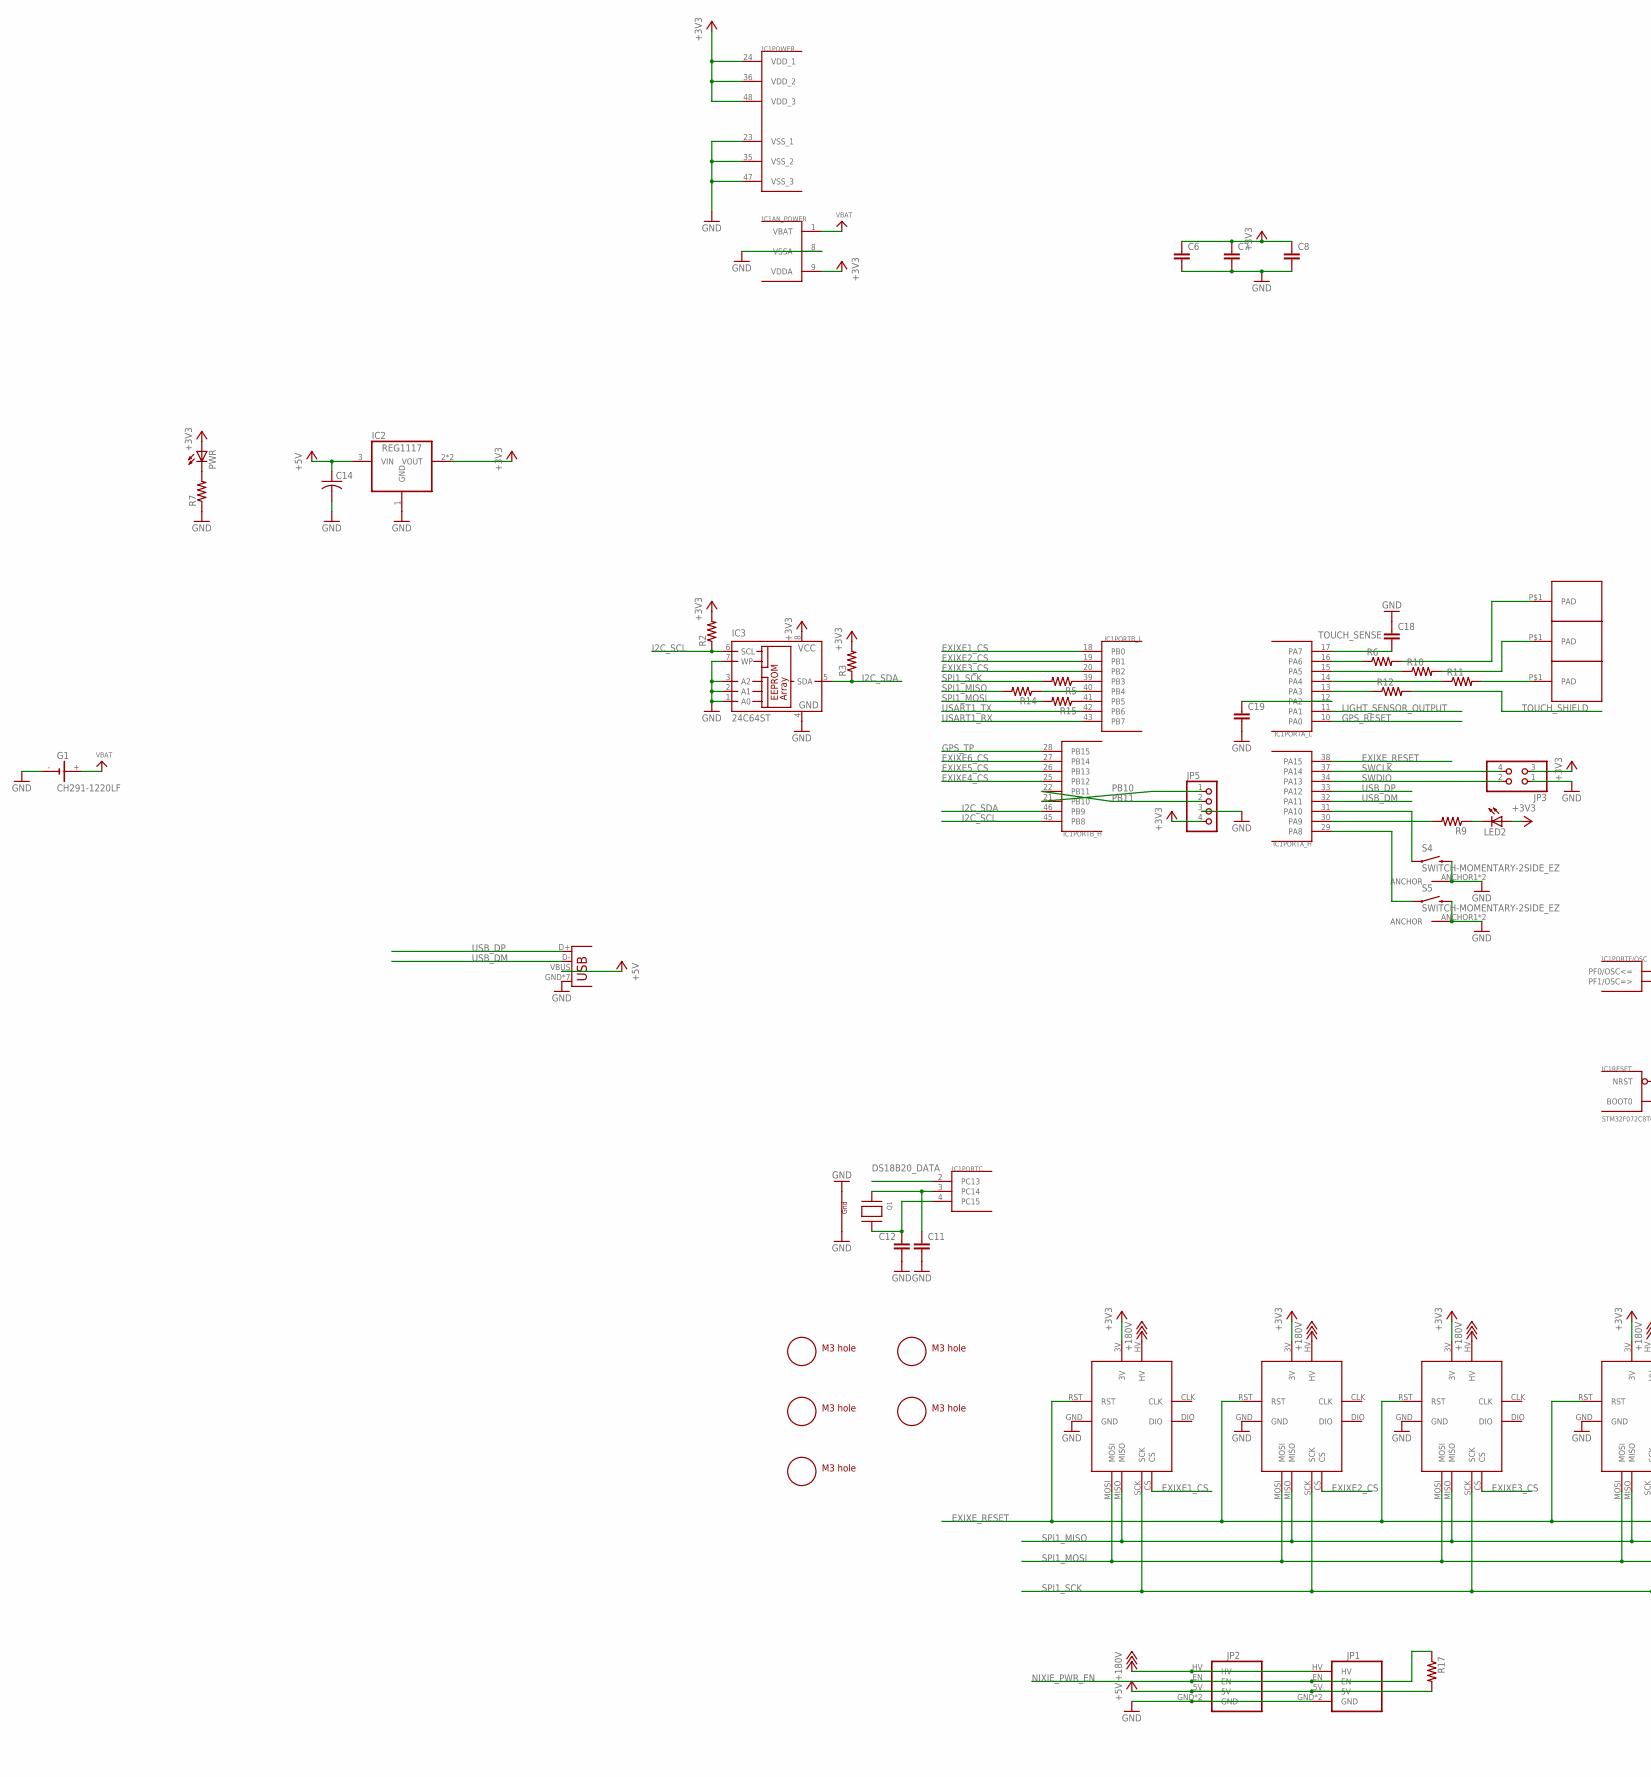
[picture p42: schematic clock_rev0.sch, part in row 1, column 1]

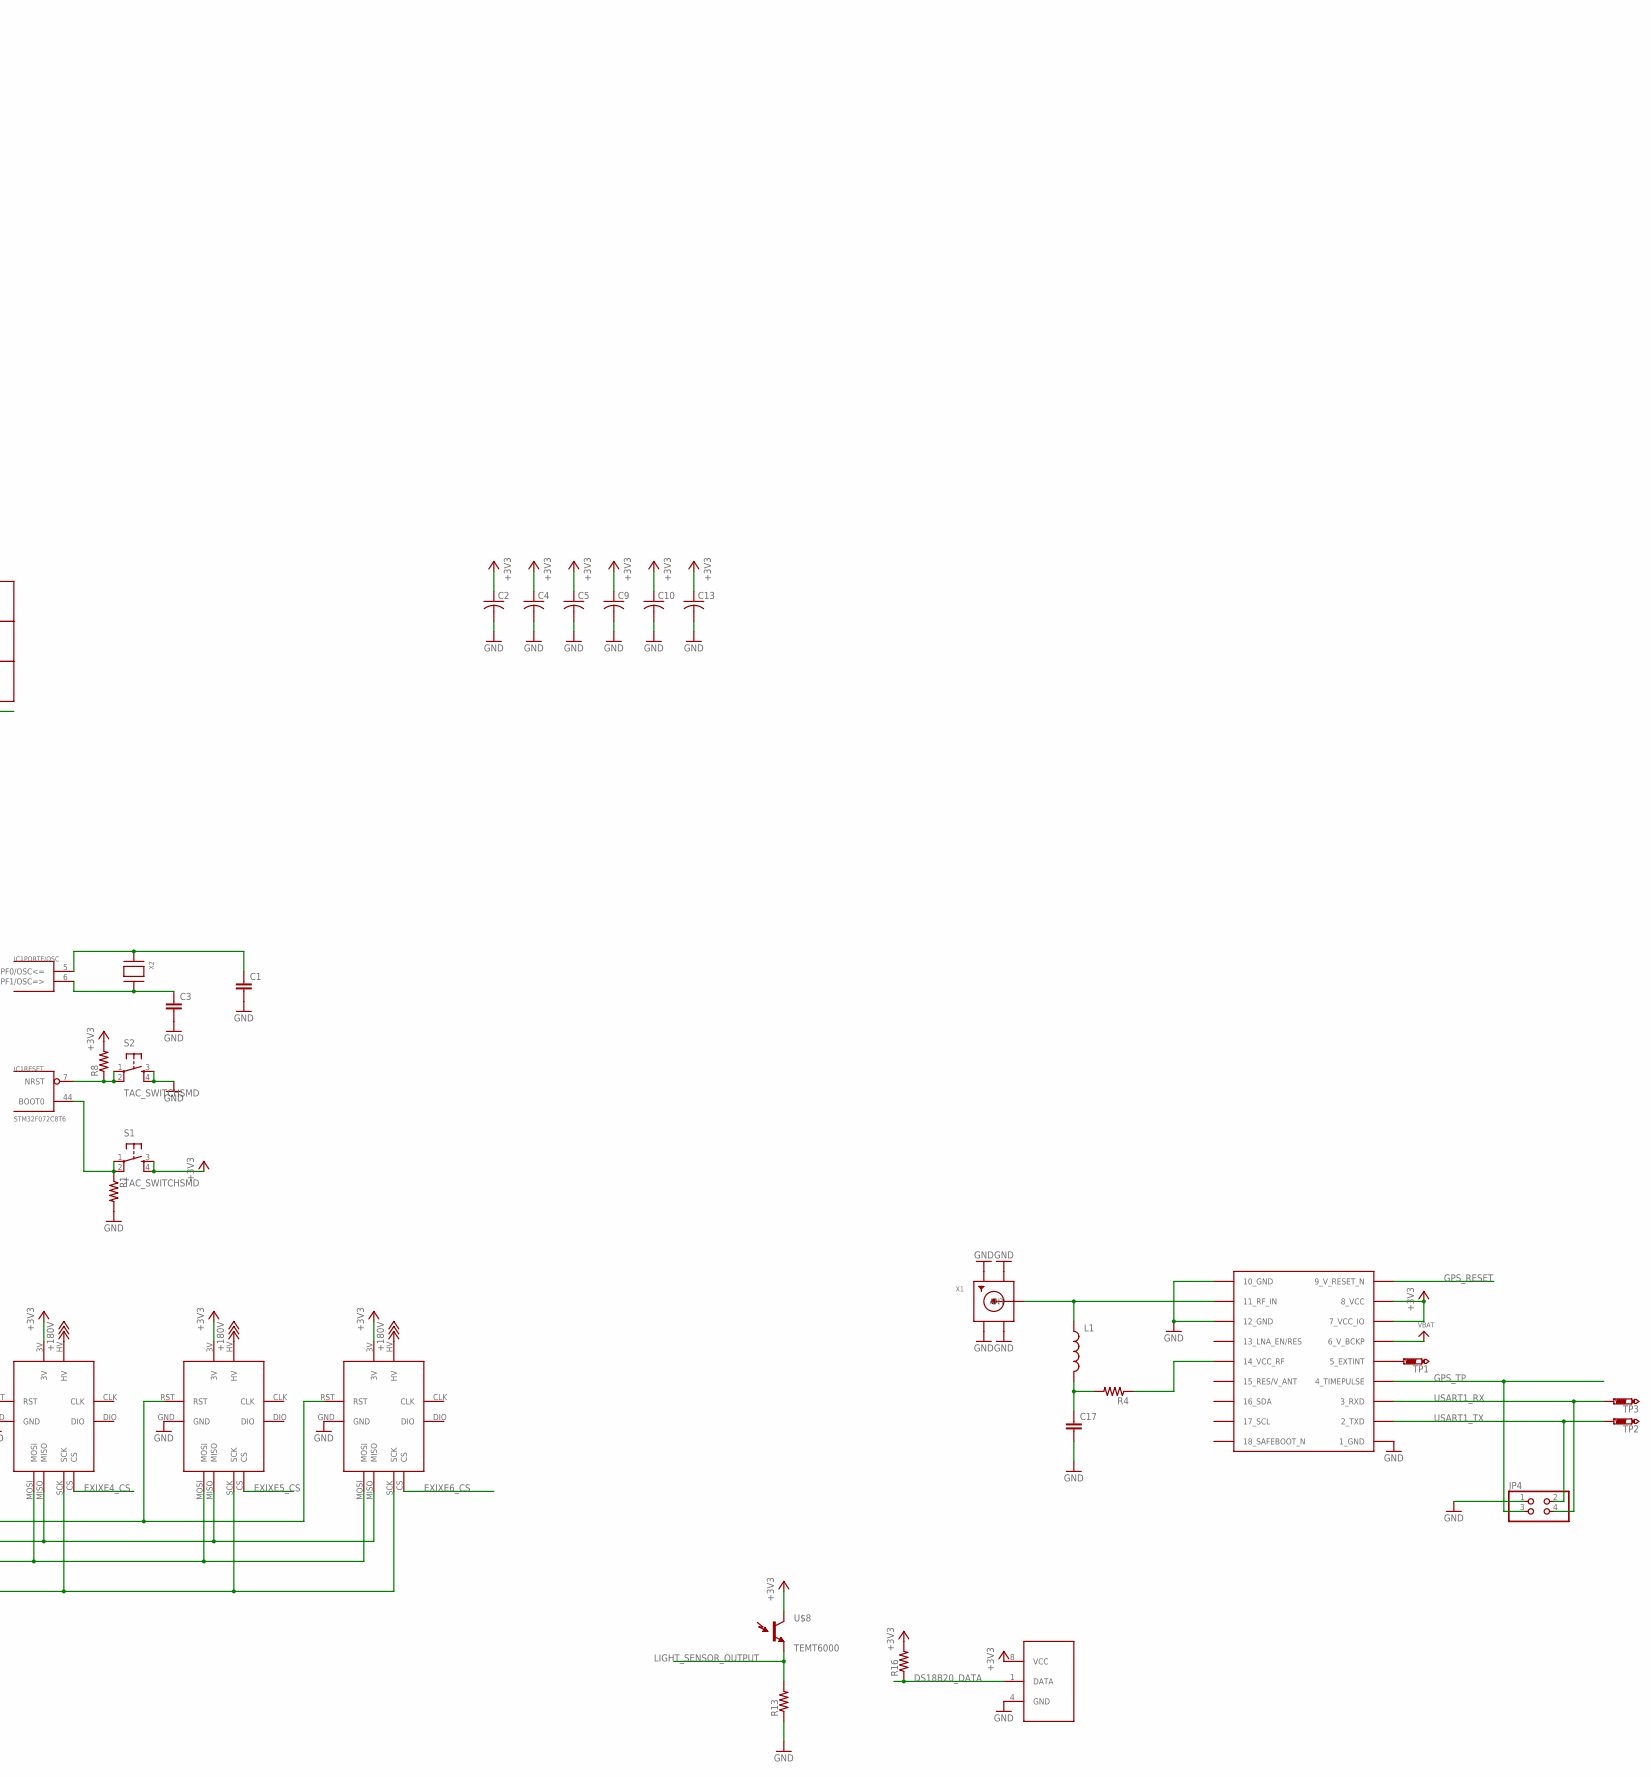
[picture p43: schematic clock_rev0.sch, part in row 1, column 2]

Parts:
C1, C3, C6, C7, C8, C11, C12, C17, C18, C19: CAP0805; 0805
C2, C4, C5, C9, C10, C13, C14: C-USC1210; C1210
G1: CH291-1220LF
IC1: STM32F072C8T6; TQFP48
IC2: REG1117; SOT223
IC3: 24C64ST; TSSOP8
JP1: EBAY_MODULEEBAY; EBAY_PKG
JP2: EBAY_MODULETAOBAO; TAOBAO_PKG
JP3, JP4: PINHD-2X2; 2X02
JP5: PINHD-1X4; 1X04
L1: INDUCTOR0805; 0805
LED2: LEDCHIP-LED0805; CHIP-LED0805
PWR: LEDCHIP-LED0805; CHIP-LED0805
Q1: XTAL-4-3225; NX3225
R1, R2, R3, R4, R5, R6, R7, R8, R9, R10, R11, R12, R13, R14, R15, R16, R17: RESISTOR0805-RES; 0805
S1, S2: TAC_SWITCHSMD; TACTILE-SWITCH-SMD
S4, S5: SWITCH-MOMENTARY-2SIDE_EZ; TACTILE-PTH-SIDEEZ
TP1, TP2, TP3: PTR1TP20R; TP20R
U$1, U$2, U$3, U$4, U$5, U$6: EXIXE; EXIXE_PAC
U$7: MAX-M8
U$8: TEMT6000; TEMT6000-SEN
U$9: DS18B20; MSOP8
U$10, U$11, U$12, U$13, U$20: M3_MOUNTING_HOLE; M3_MOUNTING_HOLE_PACK
U$14, U$15, U$16: TOUCHPAD; TOUCHPAD_PAK
X1: SMACONNECTOR; SMA90_DIP
X2: XTAL-3.2X1.5; XTAL3215
X3: USB-MICROB

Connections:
+3V3: C2.1, C4.1, C5.1, C6.1, C7.1, C8.1, C9.1, C10.1, C13.1, IC1.9 (VDDA), IC1.24 (VDD_1), IC1.36 (VDD_2), IC1.48 (VDD_3), IC2.2 (VOUT), IC2.4 (VOUT), IC3.8 (VCC), JP3.3, JP5.4, LED2.A, PWR.A, R2.2, R3.2, R8.2, R16.2, S1.3, S1.4, U$1.3V, U$2.3V, U$3.3V, U$4.3V, U$5.3V, U$6.3V, U$7.7_VCC_IO, U$7.8_VCC, U$8.COLLECTOR (C1), U$9.8 (VCC)
+5V: C14.1, IC2.3 (VIN), JP1.5V, JP2.5V, R17.2, X3.VBUS
+180V: JP1.HV, JP2.HV, U$1.HV, U$2.HV, U$3.HV, U$4.HV, U$5.HV, U$6.HV
DS18B20_DATA: IC1.2 (PC13), R16.1, U$9.1 (DATA)
EXIXE1_CS: IC1.18 (PB0), U$1.CS
EXIXE2_CS: IC1.19 (PB1), U$2.CS
EXIXE3_CS: IC1.20 (PB2), U$3.CS
EXIXE4_CS: IC1.25 (PB12), U$4.CS
EXIXE5_CS: IC1.26 (PB13), U$5.CS
EXIXE6_CS: IC1.27 (PB14), U$6.CS
EXIXE_RESET: IC1.38 (PA15), U$1.RST, U$2.RST, U$3.RST, U$4.RST, U$5.RST, U$6.RST
GND: C1.2, C2.2, C3.2, C4.2, C5.2, C6.2, C7.2, C8.2, C9.2, C10.2, C11.2, C12.2, C13.2, C14.2, C17.2, C18.1, C19.2, G1.-, IC1.8 (VSSA), IC1.23 (VSS_1), IC1.35 (VSS_2), IC1.47 (VSS_3), IC2.1 (GND), IC3.1 (A0), IC3.2 (A1), IC3.3 (A2), IC3.4 (GND), IC3.7 (WP), JP1.GND, JP1.GND2 (GND), JP2.GND, JP2.GND2 (GND), JP3.1, JP4.1, JP5.3, Q1.2 (G2), Q1.4 (G1), R1.2, R7.1, R13.1, S2.3, S2.4, S4.2, S4.ANCHOR1 (ANCHOR), S4.ANCHOR2 (ANCHOR), S5.2, S5.ANCHOR1 (ANCHOR), S5.ANCHOR2 (ANCHOR), U$1.GND, U$2.GND, U$3.GND, U$4.GND, U$5.GND, U$6.GND, U$7.1_GND, U$7.10_GND, U$7.12_GND, U$9.4 (GND), X1.GND1, X1.GND2, X1.GND3, X1.GND4, X3.GND, X3.P1 (GND), X3.P2 (GND), X3.P3 (GND), X3.P4 (GND), X3.P5 (GND), X3.P6 (GND)
GPS_RESET: IC1.10 (PA0), U$7.9_RESET_N (9_V_RESET_N)
GPS_TP: IC1.28 (PB15), JP4.3, U$7.4_TIMEPULSE
I2C_SCL: IC1.45 (PB8), IC3.6 (SCL), R2.1
I2C_SDA: IC1.46 (PB9), IC3.5 (SDA), R3.1
LIGHT_SENSOR_OUTPUT: IC1.11 (PA1), R13.2, U$8.EMITTER (E1)
unnamed: C11.1, IC1.3 (PC14), Q1.1 (X1)
unnamed: C12.1, IC1.4 (PC15), Q1.3 (X2)
unnamed: IC1.7 (NRST), R8.1, S2.1, S2.2
unnamed: L1.1, U$7.11_RF_IN, X1.ANTENNA (ANT)
unnamed: IC1.44 (BOOT0), R1.1, S1.1, S1.2
unnamed: C3.1, IC1.6 (PF1/OSC=>), X2.P$2
unnamed: C1.1, IC1.5 (PF0/OSC<=), X2.P$1
unnamed: IC1.14 (PA4), R11.1
unnamed: R10.2, U$15.P$1
unnamed: R6.2, U$16.P$1
unnamed: IC1.13 (PA3), R12.1
unnamed: C17.1, L1.2, R4.2
unnamed: R4.1, U$7.14_VCC_RF
unnamed: R11.2, U$14.P$1
unnamed: IC1.15 (PA5), R10.1
unnamed: IC1.16 (PA6), R6.1
unnamed: IC1.39 (PB3), R5.1
unnamed: C19.1, IC1.12 (PA2)
unnamed: IC1.41 (PB5), R15.1
unnamed: IC1.40 (PB4), R14.1
unnamed: LED2.C, R9.1
unnamed: IC1.31 (PA10), S4.1
unnamed: IC1.29 (PA8), S5.1
unnamed: IC1.30 (PA9), R9.2
unnamed: TP1.TP, U$7.5_EXTINT
unnamed: PWR.C, R7.2
NIXIE_PWR_EN: JP1.EN, JP2.EN, R17.1
PB10: IC1.21 (PB10), JP5.1
PB11: IC1.22 (PB11), JP5.2
SPI1_MISO: R14.2, U$1.MISO, U$2.MISO, U$3.MISO, U$4.MISO, U$5.MISO, U$6.MISO
SPI1_MOSI: R15.2, U$1.MOSI, U$2.MOSI, U$3.MOSI, U$4.MOSI, U$5.MOSI, U$6.MOSI
SPI1_SCK: R5.2, U$1.SCK, U$2.SCK, U$3.SCK, U$4.SCK, U$5.SCK, U$6.SCK
SWCLK: IC1.37 (PA14), JP3.4
SWDIO: IC1.34 (PA13), JP3.2
TOUCH_SENSE: C18.2, IC1.17 (PA7)
TOUCH_SHIELD: R12.2
USART1_RX: IC1.43 (PB7), JP4.4, TP3.TP, U$7.3_RXD
USART1_TX: IC1.42 (PB6), JP4.2, TP2.TP, U$7.2_TXD
USB_DM: IC1.32 (PA11), X3.D-
USB_DP: IC1.33 (PA12), X3.D+
VBAT: G1.+, IC1.1 (VBAT), U$7.6_V_BCKP

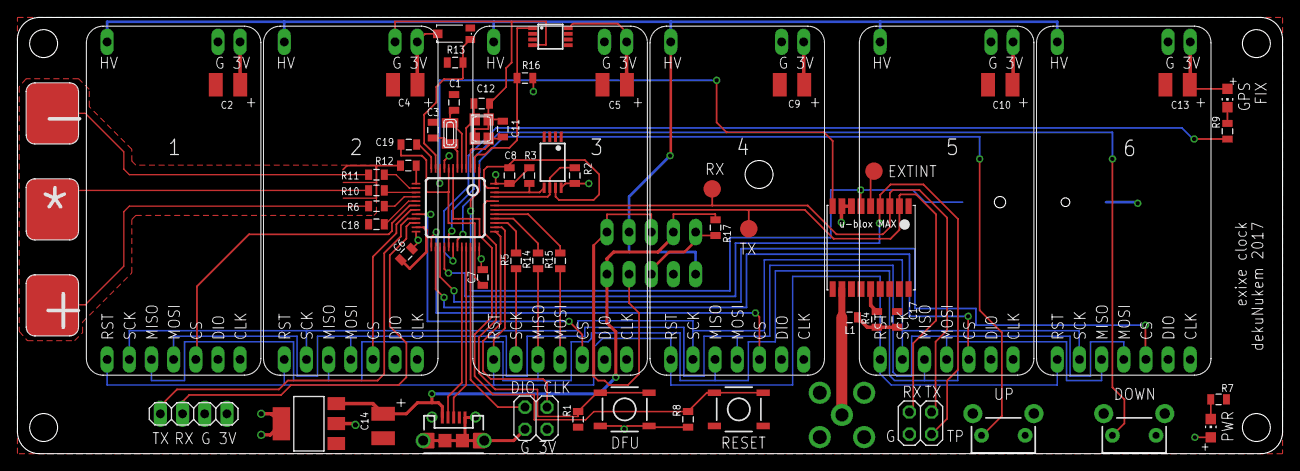
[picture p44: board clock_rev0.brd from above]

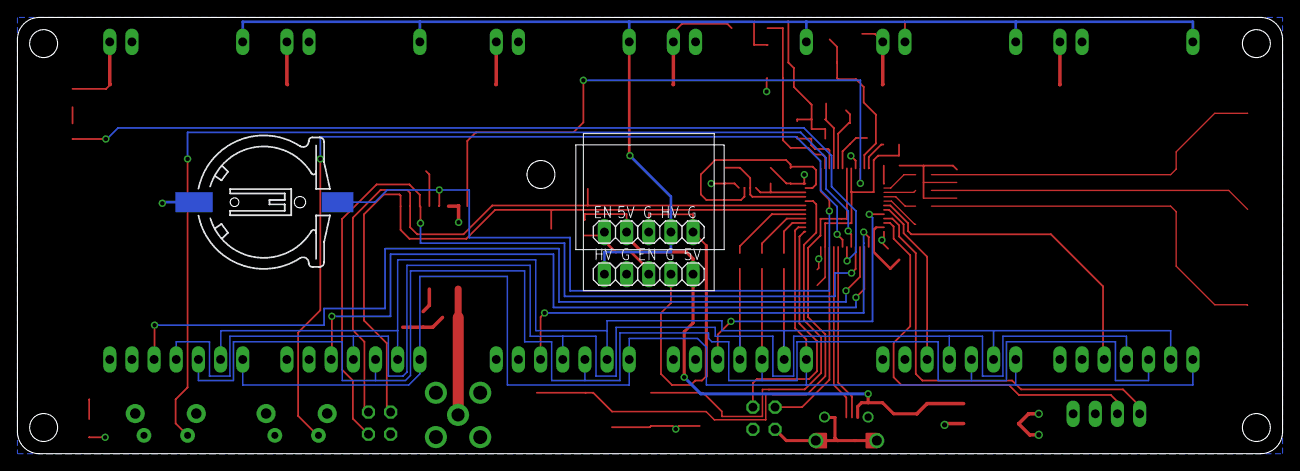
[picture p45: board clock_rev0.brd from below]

Board: 2 copper layers, 145.0 x 50.0 mm, 74 parts (3 on the bottom side), 57 nets.

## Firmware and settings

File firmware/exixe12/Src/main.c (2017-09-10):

/**
  ******************************************************************************
  * File Name          : main.c
  * Description        : Main program body
  ******************************************************************************
  ** This notice applies to any and all portions of this file
  * that are not between comment pairs USER CODE BEGIN and
  * USER CODE END. Other portions of this file, whether 
  * inserted by the user or by software development tools
  * are owned by their respective copyright owners.
  *
  * COPYRIGHT(c) 2017 STMicroelectronics
  *
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
  ******************************************************************************
  */
/* Includes ------------------------------------------------------------------*/
#include "main.h"
#include "stm32f0xx_hal.h"

/* USER CODE BEGIN Includes */
#include "shared.h"
#include "helpers.h"

/* USER CODE END Includes */

IWDG_HandleTypeDef hiwdg;

SPI_HandleTypeDef hspi1;
DMA_HandleTypeDef hdma_spi1_rx;

TIM_HandleTypeDef htim1;
TIM_HandleTypeDef htim2;
TIM_HandleTypeDef htim3;
TIM_HandleTypeDef htim14;
TIM_HandleTypeDef htim16;
TIM_HandleTypeDef htim17;

/* USER CODE BEGIN PV */

/* USER CODE END PV */

void SystemClock_Config(void);
static void MX_GPIO_Init(void);
static void MX_DMA_Init(void);
static void MX_SPI1_Init(void);
static void MX_TIM14_Init(void);
static void MX_TIM3_Init(void);
static void MX_TIM16_Init(void);
static void MX_TIM1_Init(void);
static void MX_TIM2_Init(void);
static void MX_TIM17_Init(void);
static void MX_IWDG_Init(void);

void HAL_TIM_MspPostInit(TIM_HandleTypeDef *htim);

/* USER CODE BEGIN PFP */
/* USER CODE END PFP */

int main(void)
{

  /* MCU Configuration----------------------------------------------------------*/

  /* Reset of all peripherals, Initializes the Flash interface and the Systick. */
  HAL_Init();

  /* Configure the system clock */
  SystemClock_Config();

  /* Initialize all configured peripherals */
  MX_GPIO_Init();
  MX_DMA_Init();
  MX_SPI1_Init();
  MX_TIM14_Init();
  MX_TIM3_Init();
  MX_TIM16_Init();
  MX_TIM1_Init();
  MX_TIM2_Init();
  MX_TIM17_Init();
  MX_IWDG_Init();

  /* Infinite loop */
  /* USER CODE BEGIN WHILE */
  timer_init();
  HAL_Delay(10);
  while (1)
  {
    HAL_IWDG_Refresh(&hiwdg);
    if(HAL_GPIO_ReadPin(GPIOA, GPIO_PIN_15) == GPIO_PIN_SET)
      HAL_SPI_Receive_DMA(&hspi1, spi_recv_buf, SPI_BUF_SIZE);
  /* USER CODE END WHILE */

  /* USER CODE BEGIN 3 */
  }
  /* USER CODE END 3 */

}

/** System Clock Configuration
*/
void SystemClock_Config(void)
{

  RCC_OscInitTypeDef RCC_OscInitStruct;
  RCC_ClkInitTypeDef RCC_ClkInitStruct;
	
	

    /**Initializes the CPU, AHB and APB busses clocks 
    */
  RCC_OscInitStruct.OscillatorType = RCC_OSCILLATORTYPE_HSI48|RCC_OSCILLATORTYPE_LSI;
  RCC_OscInitStruct.HSI48State = RCC_HSI48_ON;
  RCC_OscInitStruct.LSIState = RCC_LSI_ON;
  RCC_OscInitStruct.PLL.PLLState = RCC_PLL_NONE;
  if (HAL_RCC_OscConfig(&RCC_OscInitStruct) != HAL_OK)
  {
    _Error_Handler(__FILE__, __LINE__);
  }

    /**Initializes the CPU, AHB and APB busses clocks 
    */
  RCC_ClkInitStruct.ClockType = RCC_CLOCKTYPE_HCLK|RCC_CLOCKTYPE_SYSCLK
                              |RCC_CLOCKTYPE_PCLK1;
  RCC_ClkInitStruct.SYSCLKSource = RCC_SYSCLKSOURCE_HSI48;
  RCC_ClkInitStruct.AHBCLKDivider = RCC_SYSCLK_DIV1;
  RCC_ClkInitStruct.APB1CLKDivider = RCC_HCLK_DIV1;

  if (HAL_RCC_ClockConfig(&RCC_ClkInitStruct, FLASH_LATENCY_1) != HAL_OK)
  {
    _Error_Handler(__FILE__, __LINE__);
  }

    /**Configure the Systick interrupt time 
    */
  HAL_SYSTICK_Config(HAL_RCC_GetHCLKFreq()/1000);

    /**Configure the Systick 
    */
  HAL_SYSTICK_CLKSourceConfig(SYSTICK_CLKSOURCE_HCLK);

  /* SysTick_IRQn interrupt configuration */
  HAL_NVIC_SetPriority(SysTick_IRQn, 0, 0);
}

/* IWDG init function */
static void MX_IWDG_Init(void)
{

  hiwdg.Instance = IWDG;
  hiwdg.Init.Prescaler = IWDG_PRESCALER_4;
  hiwdg.Init.Window = 4095;
  hiwdg.Init.Reload = 4095;
  if (HAL_IWDG_Init(&hiwdg) != HAL_OK)
  {
    _Error_Handler(__FILE__, __LINE__);
  }

}

/* SPI1 init function */
static void MX_SPI1_Init(void)
{

  hspi1.Instance = SPI1;
  hspi1.Init.Mode = SPI_MODE_SLAVE;
  hspi1.Init.Direction = SPI_DIRECTION_2LINES;
  hspi1.Init.DataSize = SPI_DATASIZE_8BIT;
  hspi1.Init.CLKPolarity = SPI_POLARITY_LOW;
  hspi1.Init.CLKPhase = SPI_PHASE_1EDGE;
  hspi1.Init.NSS = SPI_NSS_HARD_INPUT;
  hspi1.Init.FirstBit = SPI_FIRSTBIT_MSB;
  hspi1.Init.TIMode = SPI_TIMODE_DISABLE;
  hspi1.Init.CRCCalculation = SPI_CRCCALCULATION_DISABLE;
  hspi1.Init.CRCPolynomial = 7;
  hspi1.Init.CRCLength = SPI_CRC_LENGTH_DATASIZE;
  hspi1.Init.NSSPMode = SPI_NSS_PULSE_DISABLE;
  if (HAL_SPI_Init(&hspi1) != HAL_OK)
  {
    _Error_Handler(__FILE__, __LINE__);
  }

}

/* TIM1 init function */
static void MX_TIM1_Init(void)
{

  TIM_ClockConfigTypeDef sClockSourceConfig;
  TIM_MasterConfigTypeDef sMasterConfig;
  TIM_OC_InitTypeDef sConfigOC;
  TIM_BreakDeadTimeConfigTypeDef sBreakDeadTimeConfig;

  htim1.Instance = TIM1;
  htim1.Init.Prescaler = 1920;
  htim1.Init.CounterMode = TIM_COUNTERMODE_UP;
  htim1.Init.Period = 127;
  htim1.Init.ClockDivision = TIM_CLOCKDIVISION_DIV1;
  htim1.Init.RepetitionCounter = 0;
  htim1.Init.AutoReloadPreload = TIM_AUTORELOAD_PRELOAD_DISABLE;
  if (HAL_TIM_Base_Init(&htim1) != HAL_OK)
  {
    _Error_Handler(__FILE__, __LINE__);
  }

  sClockSourceConfig.ClockSource = TIM_CLOCKSOURCE_INTERNAL;
  if (HAL_TIM_ConfigClockSource(&htim1, &sClockSourceConfig) != HAL_OK)
  {
    _Error_Handler(__FILE__, __LINE__);
  }

  if (HAL_TIM_PWM_Init(&htim1) != HAL_OK)
  {
    _Error_Handler(__FILE__, __LINE__);
  }

  sMasterConfig.MasterOutputTrigger = TIM_TRGO_RESET;
  sMasterConfig.MasterSlaveMode = TIM_MASTERSLAVEMODE_DISABLE;
  if (HAL_TIMEx_MasterConfigSynchronization(&htim1, &sMasterConfig) != HAL_OK)
  {
    _Error_Handler(__FILE__, __LINE__);
  }

  sConfigOC.OCMode = TIM_OCMODE_PWM1;
  sConfigOC.Pulse = 0;
  sConfigOC.OCPolarity = TIM_OCPOLARITY_HIGH;
  sConfigOC.OCNPolarity = TIM_OCNPOLARITY_HIGH;
  sConfigOC.OCFastMode = TIM_OCFAST_DISABLE;
  sConfigOC.OCIdleState = TIM_OCIDLESTATE_RESET;
  sConfigOC.OCNIdleState = TIM_OCNIDLESTATE_RESET;
  if (HAL_TIM_PWM_ConfigChannel(&htim1, &sConfigOC, TIM_CHANNEL_1) != HAL_OK)
  {
    _Error_Handler(__FILE__, __LINE__);
  }

  if (HAL_TIM_PWM_ConfigChannel(&htim1, &sConfigOC, TIM_CHANNEL_3) != HAL_OK)
  {
    _Error_Handler(__FILE__, __LINE__);
  }

  if (HAL_TIM_PWM_ConfigChannel(&htim1, &sConfigOC, TIM_CHANNEL_4) != HAL_OK)
  {
    _Error_Handler(__FILE__, __LINE__);
  }

  sBreakDeadTimeConfig.OffStateRunMode = TIM_OSSR_DISABLE;
  sBreakDeadTimeConfig.OffStateIDLEMode = TIM_OSSI_DISABLE;
  sBreakDeadTimeConfig.LockLevel = TIM_LOCKLEVEL_OFF;
  sBreakDeadTimeConfig.DeadTime = 0;
  sBreakDeadTimeConfig.BreakState = TIM_BREAK_DISABLE;
  sBreakDeadTimeConfig.BreakPolarity = TIM_BREAKPOLARITY_HIGH;
  sBreakDeadTimeConfig.AutomaticOutput = TIM_AUTOMATICOUTPUT_DISABLE;
  if (HAL_TIMEx_ConfigBreakDeadTime(&htim1, &sBreakDeadTimeConfig) != HAL_OK)
  {
    _Error_Handler(__FILE__, __LINE__);
  }

  HAL_TIM_MspPostInit(&htim1);

}

/* TIM2 init function */
static void MX_TIM2_Init(void)
{

  TIM_ClockConfigTypeDef sClockSourceConfig;
  TIM_MasterConfigTypeDef sMasterConfig;
  TIM_OC_InitTypeDef sConfigOC;

  htim2.Instance = TIM2;
  htim2.Init.Prescaler = 1920;
  htim2.Init.CounterMode = TIM_COUNTERMODE_UP;
  htim2.Init.Period = 127;
  htim2.Init.ClockDivision = TIM_CLOCKDIVISION_DIV1;
  htim2.Init.AutoReloadPreload = TIM_AUTORELOAD_PRELOAD_DISABLE;
  if (HAL_TIM_Base_Init(&htim2) != HAL_OK)
  {
    _Error_Handler(__FILE__, __LINE__);
  }

  sClockSourceConfig.ClockSource = TIM_CLOCKSOURCE_INTERNAL;
  if (HAL_TIM_ConfigClockSource(&htim2, &sClockSourceConfig) != HAL_OK)
  {
    _Error_Handler(__FILE__, __LINE__);
  }

  if (HAL_TIM_PWM_Init(&htim2) != HAL_OK)
  {
    _Error_Handler(__FILE__, __LINE__);
  }

  sMasterConfig.MasterOutputTrigger = TIM_TRGO_RESET;
  sMasterConfig.MasterSlaveMode = TIM_MASTERSLAVEMODE_DISABLE;
  if (HAL_TIMEx_MasterConfigSynchronization(&htim2, &sMasterConfig) != HAL_OK)
  {
    _Error_Handler(__FILE__, __LINE__);
  }

  sConfigOC.OCMode = TIM_OCMODE_PWM1;
  sConfigOC.Pulse = 0;
  sConfigOC.OCPolarity = TIM_OCPOLARITY_HIGH;
  sConfigOC.OCFastMode = TIM_OCFAST_DISABLE;
  if (HAL_TIM_PWM_ConfigChannel(&htim2, &sConfigOC, TIM_CHANNEL_1) != HAL_OK)
  {
    _Error_Handler(__FILE__, __LINE__);
  }

  if (HAL_TIM_PWM_ConfigChannel(&htim2, &sConfigOC, TIM_CHANNEL_2) != HAL_OK)
  {
    _Error_Handler(__FILE__, __LINE__);
  }

  if (HAL_TIM_PWM_ConfigChannel(&htim2, &sConfigOC, TIM_CHANNEL_3) != HAL_OK)
  {
    _Error_Handler(__FILE__, __LINE__);
  }

  if (HAL_TIM_PWM_ConfigChannel(&htim2, &sConfigOC, TIM_CHANNEL_4) != HAL_OK)
  {
    _Error_Handler(__FILE__, __LINE__);
  }

  HAL_TIM_MspPostInit(&htim2);

}

/* TIM3 init function */
static void MX_TIM3_Init(void)
{

  TIM_ClockConfigTypeDef sClockSourceConfig;
  TIM_MasterConfigTypeDef sMasterConfig;
  TIM_OC_InitTypeDef sConfigOC;

  htim3.Instance = TIM3;
  htim3.Init.Prescaler = 1920;
  htim3.Init.CounterMode = TIM_COUNTERMODE_UP;
  htim3.Init.Period = 127;
  htim3.Init.ClockDivision = TIM_CLOCKDIVISION_DIV1;
  htim3.Init.AutoReloadPreload = TIM_AUTORELOAD_PRELOAD_DISABLE;
  if (HAL_TIM_Base_Init(&htim3) != HAL_OK)
  {
    _Error_Handler(__FILE__, __LINE__);
  }

  sClockSourceConfig.ClockSource = TIM_CLOCKSOURCE_INTERNAL;
  if (HAL_TIM_ConfigClockSource(&htim3, &sClockSourceConfig) != HAL_OK)
  {
    _Error_Handler(__FILE__, __LINE__);
  }

  if (HAL_TIM_PWM_Init(&htim3) != HAL_OK)
  {
    _Error_Handler(__FILE__, __LINE__);
  }

  sMasterConfig.MasterOutputTrigger = TIM_TRGO_RESET;
  sMasterConfig.MasterSlaveMode = TIM_MASTERSLAVEMODE_DISABLE;
  if (HAL_TIMEx_MasterConfigSynchronization(&htim3, &sMasterConfig) != HAL_OK)
  {
    _Error_Handler(__FILE__, __LINE__);
  }

  sConfigOC.OCMode = TIM_OCMODE_PWM1;
  sConfigOC.Pulse = 0;
  sConfigOC.OCPolarity = TIM_OCPOLARITY_HIGH;
  sConfigOC.OCFastMode = TIM_OCFAST_DISABLE;
  if (HAL_TIM_PWM_ConfigChannel(&htim3, &sConfigOC, TIM_CHANNEL_1) != HAL_OK)
  {
    _Error_Handler(__FILE__, __LINE__);
  }

  if (HAL_TIM_PWM_ConfigChannel(&htim3, &sConfigOC, TIM_CHANNEL_2) != HAL_OK)
  {
    _Error_Handler(__FILE__, __LINE__);
  }

  if (HAL_TIM_PWM_ConfigChannel(&htim3, &sConfigOC, TIM_CHANNEL_3) != HAL_OK)
  {
    _Error_Handler(__FILE__, __LINE__);
  }

  if (HAL_TIM_PWM_ConfigChannel(&htim3, &sConfigOC, TIM_CHANNEL_4) != HAL_OK)
  {
    _Error_Handler(__FILE__, __LINE__);
  }

  HAL_TIM_MspPostInit(&htim3);

}

/* TIM14 init function */
static void MX_TIM14_Init(void)
{

  TIM_OC_InitTypeDef sConfigOC;

  htim14.Instance = TIM14;
  htim14.Init.Prescaler = 1920;
  htim14.Init.CounterMode = TIM_COUNTERMODE_UP;
  htim14.Init.Period = 127;
  htim14.Init.ClockDivision = TIM_CLOCKDIVISION_DIV1;
  htim14.Init.AutoReloadPreload = TIM_AUTORELOAD_PRELOAD_DISABLE;
  if (HAL_TIM_Base_Init(&htim14) != HAL_OK)
  {
    _Error_Handler(__FILE__, __LINE__);
  }

  if (HAL_TIM_PWM_Init(&htim14) != HAL_OK)
  {
    _Error_Handler(__FILE__, __LINE__);
  }

  sConfigOC.OCMode = TIM_OCMODE_PWM1;
  sConfigOC.Pulse = 0;
  sConfigOC.OCPolarity = TIM_OCPOLARITY_HIGH;
  sConfigOC.OCFastMode = TIM_OCFAST_DISABLE;
  if (HAL_TIM_PWM_ConfigChannel(&htim14, &sConfigOC, TIM_CHANNEL_1) != HAL_OK)
  {
    _Error_Handler(__FILE__, __LINE__);
  }

  HAL_TIM_MspPostInit(&htim14);

}

/* TIM16 init function */
static void MX_TIM16_Init(void)
{

  TIM_OC_InitTypeDef sConfigOC;
  TIM_BreakDeadTimeConfigTypeDef sBreakDeadTimeConfig;

  htim16.Instance = TIM16;
  htim16.Init.Prescaler = 1920;
  htim16.Init.CounterMode = TIM_COUNTERMODE_UP;
  htim16.Init.Period = 127;
  htim16.Init.ClockDivision = TIM_CLOCKDIVISION_DIV1;
  htim16.Init.RepetitionCounter = 0;
  htim16.Init.AutoReloadPreload = TIM_AUTORELOAD_PRELOAD_DISABLE;
  if (HAL_TIM_Base_Init(&htim16) != HAL_OK)
  {
    _Error_Handler(__FILE__, __LINE__);
  }

  if (HAL_TIM_PWM_Init(&htim16) != HAL_OK)
  {
    _Error_Handler(__FILE__, __LINE__);
  }

  sConfigOC.OCMode = TIM_OCMODE_PWM1;
  sConfigOC.Pulse = 0;
  sConfigOC.OCPolarity = TIM_OCPOLARITY_HIGH;
  sConfigOC.OCNPolarity = TIM_OCNPOLARITY_HIGH;
  sConfigOC.OCFastMode = TIM_OCFAST_DISABLE;
  sConfigOC.OCIdleState = TIM_OCIDLESTATE_RESET;
  sConfigOC.OCNIdleState = TIM_OCNIDLESTATE_RESET;
  if (HAL_TIM_PWM_ConfigChannel(&htim16, &sConfigOC, TIM_CHANNEL_1) != HAL_OK)
  {
    _Error_Handler(__FILE__, __LINE__);
  }

  sBreakDeadTimeConfig.OffStateRunMode = TIM_OSSR_DISABLE;
  sBreakDeadTimeConfig.OffStateIDLEMode = TIM_OSSI_DISABLE;
  sBreakDeadTimeConfig.LockLevel = TIM_LOCKLEVEL_OFF;
  sBreakDeadTimeConfig.DeadTime = 0;
  sBreakDeadTimeConfig.BreakState = TIM_BREAK_DISABLE;
  sBreakDeadTimeConfig.BreakPolarity = TIM_BREAKPOLARITY_HIGH;
  sBreakDeadTimeConfig.AutomaticOutput = TIM_AUTOMATICOUTPUT_DISABLE;
  if (HAL_TIMEx_ConfigBreakDeadTime(&htim16, &sBreakDeadTimeConfig) != HAL_OK)
  {
    _Error_Handler(__FILE__, __LINE__);
  }

  HAL_TIM_MspPostInit(&htim16);

}

/* TIM17 init function */
static void MX_TIM17_Init(void)
{

  TIM_OC_InitTypeDef sConfigOC;
  TIM_BreakDeadTimeConfigTypeDef sBreakDeadTimeConfig;

  htim17.Instance = TIM17;
  htim17.Init.Prescaler = 1920;
  htim17.Init.CounterMode = TIM_COUNTERMODE_UP;
  htim17.Init.Period = 127;
  htim17.Init.ClockDivision = TIM_CLOCKDIVISION_DIV1;
  htim17.Init.RepetitionCounter = 0;
  htim17.Init.AutoReloadPreload = TIM_AUTORELOAD_PRELOAD_DISABLE;
  if (HAL_TIM_Base_Init(&htim17) != HAL_OK)
  {
    _Error_Handler(__FILE__, __LINE__);
  }

  if (HAL_TIM_PWM_Init(&htim17) != HAL_OK)
  {
    _Error_Handler(__FILE__, __LINE__);
  }

  sConfigOC.OCMode = TIM_OCMODE_PWM1;
  sConfigOC.Pulse = 0;
  sConfigOC.OCPolarity = TIM_OCPOLARITY_HIGH;
  sConfigOC.OCNPolarity = TIM_OCNPOLARITY_HIGH;
  sConfigOC.OCFastMode = TIM_OCFAST_DISABLE;
  sConfigOC.OCIdleState = TIM_OCIDLESTATE_RESET;
  sConfigOC.OCNIdleState = TIM_OCNIDLESTATE_RESET;
  if (HAL_TIM_PWM_ConfigChannel(&htim17, &sConfigOC, TIM_CHANNEL_1) != HAL_OK)
  {
    _Error_Handler(__FILE__, __LINE__);
  }

  sBreakDeadTimeConfig.OffStateRunMode = TIM_OSSR_DISABLE;
  sBreakDeadTimeConfig.OffStateIDLEMode = TIM_OSSI_DISABLE;
  sBreakDeadTimeConfig.LockLevel = TIM_LOCKLEVEL_OFF;
  sBreakDeadTimeConfig.DeadTime = 0;
  sBreakDeadTimeConfig.BreakState = TIM_BREAK_DISABLE;
  sBreakDeadTimeConfig.BreakPolarity = TIM_BREAKPOLARITY_HIGH;
  sBreakDeadTimeConfig.AutomaticOutput = TIM_AUTOMATICOUTPUT_DISABLE;
  if (HAL_TIMEx_ConfigBreakDeadTime(&htim17, &sBreakDeadTimeConfig) != HAL_OK)
  {
    _Error_Handler(__FILE__, __LINE__);
  }

  HAL_TIM_MspPostInit(&htim17);

}

/** 
  * Enable DMA controller clock
  */
static void MX_DMA_Init(void) 
{
  /* DMA controller clock enable */
  __HAL_RCC_DMA1_CLK_ENABLE();

  /* DMA interrupt init */
  /* DMA1_Channel2_3_IRQn interrupt configuration */
  HAL_NVIC_SetPriority(DMA1_Channel2_3_IRQn, 0, 0);
  HAL_NVIC_EnableIRQ(DMA1_Channel2_3_IRQn);

}

/** Configure pins as 
        * Analog 
        * Input 
        * Output
        * EVENT_OUT
        * EXTI
*/
static void MX_GPIO_Init(void)
{

  /* GPIO Ports Clock Enable */
  __HAL_RCC_GPIOA_CLK_ENABLE();
  __HAL_RCC_GPIOB_CLK_ENABLE();

}

/* USER CODE BEGIN 4 */
void HAL_SPI_RxCpltCallback(SPI_HandleTypeDef *hspi)
{
  if((spi_recv_buf[0] & 0xfe) != SPI_CMD_UPDATE)
    HAL_NVIC_SystemReset();
  set_pwm(spi_recv_buf);
  HAL_SPI_Receive_DMA(&hspi1, spi_recv_buf, SPI_BUF_SIZE);
}

/* USER CODE END 4 */
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


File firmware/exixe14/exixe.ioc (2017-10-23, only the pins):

Mcu.UserName=STM32F042K6Tx
PA0.Signal=S_TIM2_CH1_ETR
PA1.Signal=S_TIM2_CH2
PA10.Signal=S_TIM1_CH3
PA11.Signal=S_TIM1_CH4
PA12.GPIO_Label=BAKE
PA12.Signal=GPIO_Output
PA13.Signal=SYS_SWDIO
PA14.Signal=SYS_SWCLK
PA15.Signal=SPI1_NSS
PA2.Signal=S_TIM2_CH3
PA3.Signal=S_TIM2_CH4
PA4.Signal=S_TIM14_CH1
PA5.Signal=SPI1_SCK
PA6.Signal=SPI1_MISO
PA7.Signal=SPI1_MOSI
PA8.Signal=S_TIM1_CH1
PA9.Signal=S_TIM1_CH2
PB0.Signal=S_TIM3_CH3
PB1.Signal=S_TIM3_CH4
PB4.Signal=S_TIM3_CH1
PB5.Signal=S_TIM3_CH2
PB6.Signal=USART1_TX
PB7.Signal=TIM17_CH1N
PB8.Signal=S_TIM16_CH1

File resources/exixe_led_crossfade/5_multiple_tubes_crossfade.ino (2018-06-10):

/*
  exixe modules:
  https://github.com/dekuNukem/exixe

  library docs:
  https://github.com/dekuNukem/exixe/tree/master/arduino_library

  Demo 5: Loop digits on two tubes with crossfade animation
*/

#define RAINBOW_COLORS 6

#include "exixe.h"

// change those to the cs pins you're using
int cs1 = 10;
int cs2 = 9;
unsigned char count;

unsigned char cl_red[RAINBOW_COLORS] = {148, 0, 0, 255, 255, 255};
unsigned char cl_green[RAINBOW_COLORS] = {0, 0, 255, 255, 127, 0};
unsigned char cl_blue[RAINBOW_COLORS] = {211, 255, 0, 0, 0, 0};


exixe my_tube1 = exixe(cs1);
exixe my_tube2 = exixe(cs2);

void setup()
{
  // ONLY CALL THIS ONCE
  my_tube1.spi_init();

  my_tube1.clear();
  my_tube2.clear();
  randomSeed(analogRead(0));
}

void loop()
{
  count = (count + 1) % 10; // keep count between 0 to 9
  unsigned char cc1 = random(RAINBOW_COLORS);
  unsigned char cc2 = random(RAINBOW_COLORS);

  my_tube1.crossfade_init(count, 15, 127, 0, cl_red[cc1]/2, cl_green[cc1]/2, cl_blue[cc1]/2);
  my_tube2.crossfade_init(10-count, 15, 127, 0, cl_red[cc2]/2, cl_green[cc2]/2, cl_blue[cc2]/2);

  /*
      again, crossfade_run() is non-blocking, that means
    you can run other tasks in the loop.
      just make sure to call it at least every 33ms
    and check its return value to see if it's finished.
  */
  while(1)
  {
    unsigned char result1 = my_tube1.crossfade_run();
    unsigned char result2 = my_tube2.crossfade_run();
    // exit when both animations are finished 
    if(result1 == EXIXE_ANIMATION_FINISHED && result2 == EXIXE_ANIMATION_FINISHED)
      break;
  }

  delay(500);
}

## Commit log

2017-04-26 started sch
    [nixx.brd, nixx.sch]
2017-04-26 sorted into folders
    [nixx.brd, nixx.sch]
2017-04-26 working on it
    [nixx.brd, nixx.sch]
2017-04-26 pcb routing done
    [nixx.brd, nixx.sch]
2017-04-26 silkscreen update
    [nixx.brd, nixx.sch]
2017-04-26 rounded corners
    [nixx.brd]
2017-04-26 layout adjust
    [nixx.brd]
2017-04-27 aligned to 2.54mm grid
    [nixx.brd]
2017-04-27 moved 3v3 pin
    [nixx.brd, nixx.sch]
2017-04-27 sch cleanup
    [nixx.sch]
2017-04-27 added eeprom
    [nixx.brd, nixx.sch]
2017-04-27 added name, logo
    [nixx.brd]
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2017-05-01 using NSS, SPI test
    [nixx.brd, nixx.sch]
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2017-05-02 PA12 testpoint
    [nixx.brd, nixx.sch]
2017-05-05 updated text and miter
    [nixx.brd]
2017-05-07 started firmware
    [nixx.brd, nixx.sch]
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2017-05-07 added pulldown on BOOT0
    [nixx.brd, nixx.sch]
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2017-05-08 made eeprom optional, added PF silkscreen
    [nixx.brd, nixx.sch]
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2017-05-08 tim17 interrupt not working
    [exixe.ioc, main.c, temp.c]
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2017-05-08 moved to linux
    [clock.brd, clock.sch, nixx.brd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]
2017-05-08 rough layout
    [clock.brd, clock.sch]
2017-05-09 USBC, GPS etc
    [clock.brd, clock.sch, nixx.brd]
2017-05-10 added bake control
    [clock.brd, clock.sch, nixx.brd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]
2017-05-10 positioned boards
    [clock.brd, clock.sch, nixx.brd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]
2017-05-11 added touch
    [clock.brd, clock.sch, nixx.brd]
2017-05-12 routing done
    [clock.brd, clock.sch, nixx.brd]
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2017-05-12 started in12
    [exixe12.brd, exixe12.sch]
2017-05-14 added gps header
    [clock.brd, clock.sch]
2017-05-14 added silkscreen labels
    [clock.brd, clock.sch]
2017-05-15 sending out
    [clock.brd, exixe12.brd, exixe12.sch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]
2017-05-15 something is wrong with digit mapping
    [temp.c]
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2017-05-23 fixed bake
    [nixx.brd, nixx.sch]
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2017-05-29 all 6
    [clock_rev0.brd, clock_rev0.sch]
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2017-05-31 wtf pc13 not working
    [helpers.c, main.c, main.h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]
2017-05-31 6 tube time display
    [nixx.brd, nixx.sch]
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2017-06-02 before 1wire different pin
    [clock_rev0.brd]
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2017-06-08 new routing
    [clock.brd, clock.sch, clock_rev0.brd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]
2017-06-22 removed bake
    [exixe12.brd, exixe12.sch]
2017-07-17 working on exixe 12
    [exixe12.brd]
2017-07-18 exixe12 draft finishewd
    [exixe12.brd, exixe12.sch]
2017-07-18 added restrict
    [exixe12.brd]
2017-07-19 clened up added credit
    [exixe12.brd, exixe12.sch]
2017-07-26 added nixie dot current limit resistor
    [exixe12.brd, exixe12.sch, nixx.brd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]
2017-07-26 adjusted resistor
    [exixe12.brd, nixx.brd]
2017-07-26 main clock board adj
    [clock.brd, nixx.brd, nixx.sch]
2017-07-26 ready to fab
    [clock.brd, exixe12.brd]
2017-07-26 gerber exported
    [clock.GBL, clock.GBO, clock.GBP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]
2017-08-06 updated to use timer
    [exixe12.brd, exixe12.sch, exixe14.brd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]
2017-08-07 board cleanup
    [exixe12.brd, exixe14.brd]
2017-08-07 rev2 fab
    [exixe12.GBL, exixe12.GBO, exixe12.GBP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]
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2017-09-10 adjusted values
    [exixe14.brd, exixe14.sch]
2017-09-10 clean up pcb folder
    [clock.GBL, clock.GBO, clock.GBP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]
2017-09-10 rearranged dirctory structure
    [clock.GBL, clock.GBO, clock.GBP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]
2017-10-20 moved exixe clock to its own repo
    [clock.brd, clock.sch, exixe12.brd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]
2017-10-24 more readme
    [exixe14.sch]
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2017-11-22 adjust passive values and added bom
    [exixe12.brd, exixe12.sch, exixe12_bom.xlsx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]
2017-12-13 added more hv isolation
    [exixe12.brd, exixe14.brd]
2017-12-15 clean up silkscreen
    [exixe12.brd]
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2017-12-19 increased board isolation
    [exixe12.GBL, exixe12.GBO, exixe12.GBP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]
2017-12-19 removed gerber file
    [exixe12.GBL, exixe12.GBO, exixe12.GBP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]
2017-12-19 started working on pogo rig
    [exixe14.brd]
2017-12-19 working on pogo rig
    [exixe14.brd, exixe_pogo.brd, exixe_pogo.sch]
2017-12-19 pogo rig mcu setup
    [exixe_pogo.brd, exixe_pogo.sch]
2017-12-20 refining board design for production run
    [exixe14.brd, exixe14.sch]
2017-12-20 adjusted passive values
    [exixe14.brd, exixe14.sch]
2017-12-21 changed testpoints to unpopulated resistors
    [exixe12.brd, exixe12.sch, exixe14.brd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]
2017-12-21 adjusted more values
    [exixe12.brd, exixe12.sch]
2017-12-22 working on pogo board
    [exixe_pogo.brd, exixe_pogo.sch]
2017-12-23 pogo rig mostly finished
    [exixe_pogo.brd, exixe_pogo.sch]
2017-12-26 changed pogo pad size
    [exixe_pogo.brd, exixe_pogo.sch]
2017-12-26 increased HV width
    [exixe_pogo.brd]
2017-12-26 added HEX firmware file, added gerber files
    [exixe12.GBL, exixe12.GBO, exixe12.GBP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]
2017-12-26 added firmware upload instruction, moved making some into its own md file
    [exixe_pogo.brd, exixe_pogo.sch]
2017-12-29 added plate
    [exixe_pogo.brd, exixe_pogo.sch]
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2018-03-26 fixed a bug in library
    [1_LED_test.ino, 2_loop_digit_simple.ino, 3_loop_digit_crossfade.ino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]
2018-04-03 fixed issue 2 and 3
    [0_LED_test.ino, 1_LED_test.ino, 1_show4.ino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]
2018-06-10 fixed typo
    [exixe12_bom.xlsx]
2018-06-29 fixed a stupid typo on the silkscreen
    [exixe12.brd, exixe14.brd]
2018-07-30 fixed SPI a wiring error
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2018-10-27 added date mark
    [exixe12.GBL, exixe12.GBO, exixe12.GBP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]
2018-10-29 removed DP resistor, new pogo firmware
    [exixe12.brd, exixe12.sch, exixe14.brd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]
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2019-06-08 updated pogo board
    [exixe_pogo.brd, exixe_pogo.sch]
2019-06-12 updated pogo rig
    [exixe_pogo.brd, exixe_pogo.sch]
2019-06-14 pogo v2 working
    [exixe_pogo.brd]
2019-08-27 prepare for a new production run
    [exixe12.brd, exixe14.brd]
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2020-02-23 new production, updated BOM about unused components
    [exixe12.brd, exixe12_bom.xlsx, exixe14.brd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]
2020-06-04 fixed SPI diagram
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

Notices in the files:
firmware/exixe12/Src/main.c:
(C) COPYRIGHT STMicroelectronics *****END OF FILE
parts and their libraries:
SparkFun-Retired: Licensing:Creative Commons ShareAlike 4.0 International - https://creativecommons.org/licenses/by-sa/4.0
